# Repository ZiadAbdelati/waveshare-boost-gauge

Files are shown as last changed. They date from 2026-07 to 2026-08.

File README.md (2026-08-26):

# Boost Gauge

An open-source digital boost/vacuum gauge and dashboard for the **[Waveshare ESP32-S3-Touch-AMOLED-1.75](https://www.waveshare.com/esp32-s3-touch-amoled-1.75.htm)** (466x466 CO5300 AMOLED).

It runs an ESP-IDF + LVGL firmware that samples a GM 3-bar MAP sensor through an ADS1115 (with an optional BMP280 for ambient reference), renders a crisp 60 Hz analog-style gauge, and serves a companion web dashboard for telemetry, theming, TPMS, and Wi-Fi/OTA setup.

It swaps straight onto the Waveshare board, replacing the stock factory launcher.

## Screenshots

| Boost / vacuum | Overboost | Neon theme |
|---|---|---|
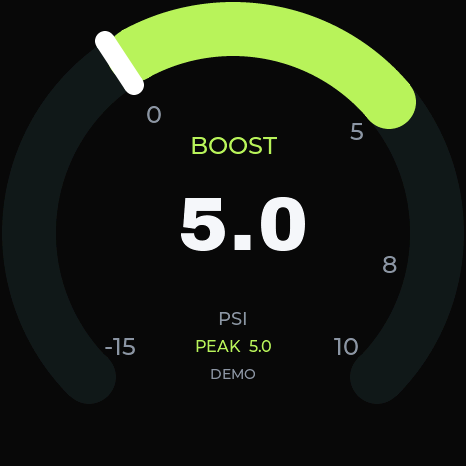
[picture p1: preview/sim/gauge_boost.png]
Boost gauge
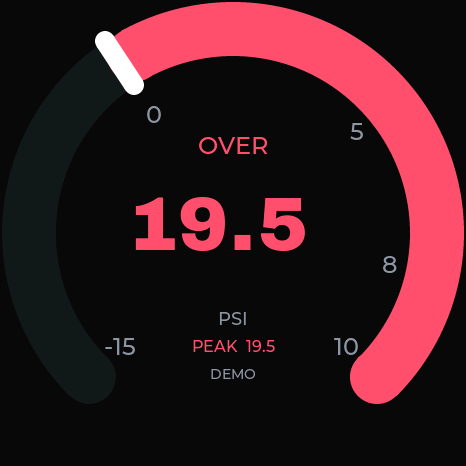
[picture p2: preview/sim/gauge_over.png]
Overboost
|  |  | `tools/sim` generates more |

More rendered previews live in [`preview/sim/`](preview/sim/).

## Features

- **Live gauge at 60 Hz** - a single filled arc that changes climate at zero: teal vacuum, lime boost, red overboost, with a big signed PSI readout and peak hold.
- **Five full gauge faces** (themes), each a distinct layout, not just a palette swap: Dyno Cell, Vault-Tec, Night City, Big Digit, and Neon.
- **Neon variants** - three layouts, four color presets, and SF Alien or Doto readout fonts.
- **Touch gestures** - tap to reset peak, swipe up/down to change themes, swipe left/right for TPMS, hold to dim, and two-finger hold for the AP QR code.
- **Web dashboard** - live cockpit, sparkline, settings, Wi-Fi setup, theme editor, and OTA updates over HTTP/WebSocket.
- **OBD-II / BLE TPMS** - Mazda MX-5 ND tire pressure plus generic mode-01 PIDs and battery voltage through a BLE ELM327 adapter.
- **Battery-backed clock** via a DS3231 RTC, DST-aware timezones, and dim-schedule control.
- **GIF playback** from the raw `media` partition.

## Hardware

- Waveshare ESP32-S3-Touch-AMOLED-1.75
- GM 12223861 (3-bar MAP) sensor through an ADS1115 on the sensor I2C bus
- Optional BMP280 ambient-pressure sensor
- Optional DS3231 RTC
- Optional BLE OBD-II/ELM327 adapter

## Quick start

The prebuilt image needs no ESP-IDF toolchain:

```bash
git clone https://github.com/ZiadAbdelati/waveshare-boost-gauge.git
cd waveshare-boost-gauge/release
python -m pip install esptool

# Linux / macOS
./flash.sh /dev/ttyACM0

# Windows PowerShell (replace COM5 with your port)
python -m esptool --chip esp32s3 -p COM5 -b 460800 `
  --before default_reset --after hard_reset write_flash `
  --flash_mode dio --flash_size 16MB --flash_freq 80m `
  0x0 boost_gauge_merged.bin
```

Newest prebuilt firmware (currently **v0.8.1**, ESP-IDF 5.5.1) is in [`release/`](release/) and on the [releases page](https://github.com/ZiadAbdelati/waveshare-boost-gauge/releases/latest). See [`release/README.md`](release/README.md) for details.

### Connect

- With saved Wi-Fi: use the address printed to serial as `BOOST_WEB_IP=`.
- Without saved Wi-Fi: join **`BoostGauge-XXXX`** / `boost1234`, then open `http://192.168.4.1/`.

## Build from source

Requires ESP-IDF **v5.5.1** with the `esp32s3` target.

```bash
git clone https://github.com/ZiadAbdelati/waveshare-boost-gauge.git
cd waveshare-boost-gauge
idf.py set-target esp32s3
idf.py build
idf.py -p /dev/ttyACM0 flash monitor
```

First build fetches the Waveshare BSP and LVGL from the ESP-IDF component registry. For a stubborn flash, hold **BOOT**, tap **RESET**, start flashing, then release **BOOT** when upload begins.

## Themes

Swipe vertically or use Settings:

```text
Dyno Cell -> Vault-Tec -> Night City -> Big Digit -> Neon -> Dyno Cell ...
```

Zone colors, arc range, zero angle, and theme-specific settings such as Neon layout, preset, and font persist in NVS.

## Project layout

```text
main/       ESP-IDF firmware
web/        dashboard sources embedded into firmware
tools/      asset, mock, benchmark, and cadence utilities
sim/        host LVGL simulator
release/    prebuilt firmware
docs/       technical documentation and measurements
preview/    simulator reference renders
```

## Documentation

- [Architecture](docs/architecture.md)
- [Display & cadence](docs/display-and-cadence.md)
- [Network & telemetry](docs/network-and-telemetry.md)
- [GIF playback](docs/gif-playback.md)
- [TPMS & OBD](docs/tpms-obd.md)
- [Sensors & calibration](docs/sensors-and-calibration.md)
- [GUI guide](docs/gui-guide.md)
- [Themes](docs/themes.md)
- [Release notes](docs/release-notes.md)
- [Regression ledger](docs/regression-ledger.md)

## Restore factory launcher

Flash the factory image from the [Waveshare releases](https://github.com/waveshareteam/ESP32-S3-Touch-AMOLED-1.75/releases).

## BLE central test harness (Intel hackintosh)

`tools/ble_central_test` scans for the gauge (`B6A00000`) and connects; it absorbs the IntelBluetoothFirmware 5→1 state flap (releases the central, waits 3 s, recreates it, retries the scan once) and self-exits instead of hanging. If a connection still fails with `saw N reset(s)`, the Intel stack cannot sustain a GATT link: add `-btlfxbeta` to the boot-args and ensure BlueToolFixup/IntelBTPatcher are current, stop concurrent `itlwm` WiFi scans (`sudo wdutil scan` or assoc churn) during the test, and if it persists prefer a `THIRD_PARTY_DONGLE` USB Bluetooth adapter over the internal Intel radio.

## License

Third-party code and OFL fonts are attributed in their sources. Doto's license ships as [`web/OFL-Doto.txt`](web/OFL-Doto.txt).

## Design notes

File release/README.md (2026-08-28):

# Prebuilt firmware v0.9.2 — companion BLE hardening

Firmware **`v0.9.2`**, built with **ESP-IDF 5.5.1** for **ESP32-S3**, 16 MB
flash. Headlines: the **BLE Control surface is now a real HTTP mirror** —
`/logs` returns a bounded compact window (128 points, decimated evenly across
the requested window so the 9.789 psi/s demo sweep draws triangles, not
staircases), and `/network` GET/PUT/DELETE + `/network/scan` +
`/network/reconnect` are served over Bluetooth, so the companion apps' Settings
and Wi-Fi pages work without joining the gauge's Wi-Fi. Blocking routes (logs
build, Wi-Fi scan, calibration) run on the driver task with heap buffers — the
NimBLE host loop is never stalled. The **OBD2 central defers its scan bursts
while a phone holds the companion link**, so enabling TPMS/OBD2 no longer
starves Logs. Companion apps gained **link self-healing** (iOS re-subscribes
notifications after a board reboot; Android detects and re-bonds a stale bond
left by reflashes), **instant log-window switching** (stale-while-revalidate),
and a **theme preview that actually updates** on selection. Carries v0.9.1's
Display/Demo reorg and v0.9.0's DMA-safe AMOLED path, DS3231/DST clock, and
calibrated GM 12223861 MAP path. The same files are published on the
[latest GitHub release](https://github.com/ZiadAbdelati/waveshare-boost-gauge/releases/latest).

The image reports its own version on `/api/v1/state` (`firmwareVersion`), taken
from `git describe` at build time. This release was tagged first, then
reconfigured/built/flash-verified from the tagged tree, so the board reports a
clean `v0.9.2` (serial-verified: UI ready, brightness, HTTP API ready, BLE
advertising, zero panics).

## Files

| File | Purpose |
|---|---|
| `bootloader.bin` @ `0x0` | 2nd-stage bootloader |
| `partition-table.bin` @ `0x11000` | Partition table |
| `ota_data_initial.bin` @ `0x12000` | OTA data (boots ota_0) |
| `boost_gauge.bin` @ `0x20000` | App image — use for **web OTA** |
| `boost_gauge_merged.bin` @ `0x0` | Full-flash image for a complete reset |
| `flash.sh` + `flash_args` | Helper to flash the merged image |
| `BoostGauge-android-debug.apk` | Android companion (debug-signed, versionCode 3) |
| `BoostGauge-ios-app.zip` | iOS companion `.app` bundle (install via Xcode/devicectl) |
| `SHA256SUMS` | Checksums for everything above |

## What changed since v0.9.1

### Firmware
- **BLE `/logs` route is real.** Compact `{"tMs","psi"}` samples, ~22 B each,
  128 points (cap/32) decimated evenly across the requested `?limit=` — the
  verbose 42-point window aliased the demo sweep into staircase pulses.
- **BLE `/network*` routes.** Settings/Wi-Fi pages in the apps now reflect the
  real STA state (SSID, IP, RSSI, saved networks) and can join/remove networks
  over Bluetooth. Wi-Fi scan runs on the driver task (`APP_EV_SCAN`), never on
  the NimBLE host task.
- **Blocking routes are async.** `/logs` (`APP_EV_LOGS`), `/network/scan`
  (`APP_EV_SCAN`), and `/sensors/calibration` all run on the driver task with
  heap response buffers; the host event loop never blocks.
- **OBD scan coexistence.** The OBD central's retry loop defers new 3 s scan
  bursts while a companion client is connected (they starved the peripheral's
  notification path mid-fragment). Stored-peer connects and real scan hits are
  not gated, so the in-car adapter link is unaffected.
- `APP_BLE_CTRL_RESP_MAX` stays **4096** — an 8 KB bump panicked twice under
  Wi-Fi + LVGL DMA pressure and is not measured-safe.

### iOS companion
- **CCCD self-healing:** Control notifications are re-subscribed on every
  write/timeout failure. A board reboot resets the gauge's subscription state;
  CoreBluetooth never re-issues `setNotifyValue` on auto-reconnect, so
  responses silently vanished — the first request after a gauge reboot now
  heals it (one timeout, then clean).
- **Per-call timeouts:** `/logs` uses a single 20 s attempt + one retry instead
  of the 10 s × 4-retry cascade that re-sent requests whose late responses fed
  a dead pending.
- **Instant window switching:** the Logs view publishes the cached 1m/5m/15m
  window before fetching (stale-while-revalidate).
- **Theme preview updates on selection** (reveal-gate race fixed: explicit
  theme-ID change signal + rescue re-renders re-armed per switch).
- Toasts: one reusable window, bottom capsule, no resurfacing on tab switches;
  timezone selection is local-only until you tap "Sync timezone to gauge"
  (single toast).

### Android companion
- **Stale-bond recovery:** verifies the encrypted link before writing the CCCD;
  on failure removes the stale bond, re-bonds fresh, and retries once. Fixes
  the endless `encryption changed status 13` reconnect loop after reflashing
  the gauge.
- Timezone: selection is local-only; sync sends the selected zone (not a
  phone-derived string) and shows one toast.

## Hardware verification (this release)

- iOS (physical iPhone, pure BLE): Logs window cycle 5m → 1m → 15m → 5m, three
  consecutive passes — `Last X · 128 samples` each, link connected throughout;
  repeated with the OBD2 BLE link enabled after the coexistence fix. Firmware
  serial: every `/logs` built in 3.5–5 ms.
- All five themes cycled over BLE from the app: preview updated each time, no
  reboot, no disconnect.
- Wi-Fi scan over BLE returned live AP rows; Settings shows real STA state.
- Android (physical Pixel): stale-bond recovery verified — `removeBond` →
  fresh pairing → `encryption changed status 0` + continuous 1 Hz state writes
  ≥60 s; 92/92 unit tests.
- Host test suite 11/11.

## Install

- **Full flash (fresh board / reset):** `./flash.sh /dev/cu.usbmodem*`
  (writes the merged image at `0x0`).
- **OTA (web UI → Settings):** upload `boost_gauge.bin`.
- **Android:** install the APK (allows "unknown developer" — it's the debug key).
- **iOS:** unzip and install the `.app` via Xcode's Devices window or
  `xcrun devicectl device install app`.

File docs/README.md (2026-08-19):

# Documentation

Detailed development notes, architecture, and measurements for the Boost Gauge project. The top-level `README.md` is the user-facing quick start; everything substantive lives here.

## Getting started

- [Architecture](architecture.md) — scene system, cached faces, drawing/invalidation rules, cost model
- [Display & cadence](display-and-cadence.md) — AMOLED bring-up, internal-DMA buffers, the 60 Hz render contract
- [Network & telemetry](network-and-telemetry.md) — WebSocket/HTTP control plane, clock/RTC persistence, GIF upload
- [GIF playback](gif-playback.md) — pipeline and animation performance contract
- [TPMS & OBD](tpms-obd.md) — BLE adapter support, Mazda MX-5 ND DID set, simulator
- [Sensors & calibration](sensors-and-calibration.md) — MAP sensor bus, GM conversion, atmosphere calibration
- [GUI guide](gui-guide.md) — gestures, two-page layout, dashboard notes
- [Themes](themes.md) — theme system, Neon internals, UI design tokens
- [Release notes](release-notes.md) — per-version highlights

## Engineering history

- [Regression ledger](regression-ledger.md) — the full measurement history behind every guard rail

Also see the top-level `AGENTS.md`, which carries the currently-actionable invariants (guard rails) repo-wide.

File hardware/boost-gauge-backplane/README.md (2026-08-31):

# Boost Gauge Backplane (tscircuit)

A Ø46 mm rear daughterboard for the Waveshare ESP32-S3-Touch-AMOLED-1.75 that
powers and reads the car's analog boost sensors, adds a BMP280 + DS3231, and
mates face-to-face to the Waveshare's 8-pin H2 expansion header.

## Status

**Source repair and automated PCB checks complete; physical pre-order gates
remain** (see `DESIGN_REVIEW.md` §7). The tracked release files are release
candidates, not fabrication approval, until those checks are recorded.

| Gate | Result |
|---|---|
| `tsci check netlist` | 0 errors / 0 warnings |
| `tsci check placement` | 0 errors; 3 JST access-direction advisories |
| final circuit JSON | 0 error records, 0 long-trace warnings, 0 unrouted records |
| `tsci check shorts --mode pcb` | toolchain-blocked: `layerCanvas.getContext is not a function` twice |
| `tsci build` | autorouted 128 connections / 142 PCB traces / 106 vias, 0 router errors |

## What it does

- **Power**: car 12 V (J1) → F1 fuse → bidirectional SMBJ16CA TVS → 40 V
  DMP4065S reverse-protection P-FET → LMR36520 synchronous buck → 5.016 V →
  VBUS ORing (SS54) → 500 mA-hold F2 PTC →
  SENSOR_5V rail for the sensors. USB VBUS from the Waveshare board ORs onto
  the same rail so the board is bench-configurable without car power.
- **Analog front end**: 4× JST-PH sensor inputs (J2–J5), each with 1 kΩ series
  + 100 nF filter (fc ≈ 1.6 kHz) + BAT54S rail clamps, into an ADS1115 4-ch
  16-bit ADC on the 5 V side of a TCA9406 I2C level translator.
- **Environment**: BMP280 (baro) and DS3231MZ RTC (CR1220 backup) on the 3.3 V
  side, sharing the Waveshare's GPIO17/18 I2C bus through H2.
- **Mechanical**: Ø46.00 mm circle, 3× Ø2.2 NPTH mounts at the Waveshare's
  brass standoffs, H2 1×8 2.54 mm header at y=−18.68 (pin 1 = VBUS).

## Files

- `index.circuit.tsx` — the whole design (schematic + placement + form factor)
- `imports/` — LCSC-verified component models (`tsci import` outputs)
- `reference/` — mechanical mating spec (authoritative) + Waveshare PDFs
- `PLAN.md` — design history, decisions, session log
- `DESIGN_REVIEW.md` — bug audit with evidence, power-path math, gate status
- `dist/` — gitignored build output (regenerate with the commands below)
- `release/` — **tracked** release-candidate outputs of the verified build: Gerbers,
  drills, raw + JLC-filtered BOM/CPL, SVG renders, STEP, SHA256SUMS

## Regenerate outputs

```sh
npm run typecheck
tsci build index.circuit.tsx

# Export the verified route, not a second independent source reroute.
tsci export dist/index/circuit.json -f gerbers -o dist/gerbers
tsci export dist/index/circuit.json -f pcb-svg -o dist/pcb.svg
tsci export dist/index/circuit.json -f schematic-svg -o dist/schematic.svg
tsci export dist/index/circuit.json -f assembly-svg -o dist/assembly.svg
tsci export dist/index/circuit.json -f step -o dist/board.step
```

The Gerber export is a ZIP. Unpack it into `dist/gerbers_dir`, then generate
`bom_jlc.csv` and `cpl_jlc.csv` by excluding `BT1,H2,J1,J2,J3,J4,J5` and every
`TP_*` designator. Validate the archive, exact excluded set, supplier IDs, and
matching filtered BOM/CPL designator sets before explicitly promoting the 19
release files and regenerating `release/SHA256SUMS`. Verify checksums from this
directory with `shasum -a 256 -c release/SHA256SUMS`.

## Ordering (JLCPCB)

- PCB: upload `release/*.gbr` + drill files (2 layer).
- Assembly: upload `release/bom_jlc.csv` and `release/cpl_jlc.csv`
  — these **exclude** the 7 hand-solder parts (J1, J2–J5, BT1, H2) and 17
  PCB-only `TP_*` pads which the raw exports still include.
- Hand-solder at assembly: the bottom/outward JST-PH connectors, the H2 mating
  header, and—only after stack-clearance validation—the top/mating-face
  BS-12-B2AA002 horizontal SMT CR1220 holder. Install the cell after soldering.
- Checksums: `release/SHA256SUMS` covers every tracked artifact; verify after
  download from JLC.

## Before ordering — mandatory

See `DESIGN_REVIEW.md` §7. Required checks include a 1:1 overlay and H2 pinout,
gender, stack-height, and continuity confirmation; measured inter-board
separation and loaded BT1 clearance; bottom connector and cable access against
the flush mount; USB-C plug clearance; BMP280 vent clearance; manual U1 land
pattern comparison; an independent PCB-short DRC; and electrical/thermal bench
validation before installation in a vehicle.

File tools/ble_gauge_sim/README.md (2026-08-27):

# ble_gauge_sim

macOS **CoreBluetooth peripheral simulator** for the ESP32-S3 boost gauge.
It advertises as `BoostGauge` so the iOS and Android companion apps (built in
parallel) can be tested end-to-end over real BLE without the Waveshare board.

Dependency policy: **CoreBluetooth + Foundation only**. No other frameworks,
no third-party packages. Requires macOS 13+.

## Build

```bash
cd tools/ble_gauge_sim
swift build -c release
```

The executable lands at `tools/ble_gauge_sim/.build/release/ble_gauge_sim`.
Xcode/Command-Line Tools with the macOS 13+ SDK is required (@platforms
`.macOS(.v13)`).

## Run

```bash
tools/ble_gauge_sim/.build/release/ble_gauge_sim --verbose
```

Or without the per-request chatter:

```bash
tools/ble_gauge_sim/.build/release/ble_gauge_sim
```

CLI:

| Flag | Meaning |
|---|---|
| `--help` | Usage, GATT map, caveat. |
| `--verbose` | Log every control request/response (default logs connect/disconnect/state/restart events only). |
| `--firmware <string>` | Firmware string in DeviceInfo and Status (default `0.9.0-sim`, e.g. `--firmware v0.9.0-sim`). |

The process runs until interrupted (Ctrl-C). One clean line per event is
printed to stdout: CoreBluetooth state transitions, connect/subscribe,
disconnect/unsubscribe, and (with `--verbose`) each control
request/response.

## What it advertises

- Local name: **BoostGauge**
- Primary service: `b6a00000-0000-4000-8000-00000000b6a0` (in the adv payload)
- Connectable, startAdvertising on launch once CoreBluetooth is powered on.

## GATT map

| Characteristic | UUID suffix | Properties | Payload |
|---|---|---|---|
| Control | `b6a00001-...-b6a0` | write + notify | JSON RPC, requests ≤ 480 B |
| Status | `b6a00002-...-b6a0` | read + notify | `/state`-shaped JSON, notify ~1 Hz while subscribed |
| Log | `b6a00003-...-b6a0` | read | `BGL1\n` + 600 samples (2 min @ 5 Hz); offset reads return the suffix |
| DeviceInfo | `b6a00004-...-b6a0` | read | `{"name":"BoostGauge","fw":"0.9.0-sim","api":1}` |

Status payload (compact `/state`-shaped snapshot, waveform: sine 0-15 psi,
period ~8 s, monotonic `uptimeMs`; `zone` uses the firmware/`docs/bluetooth-gatt.md`
tokens VAC / ATMO / BOOST / OVER):

```json
{
  "psi": 7.32, "peak": 12.4, "zone": "BOOST", "demo": true,
  "uptimeMs": 123456, "brightness": 80, "theme": "dyno-cell",
  "tpms": {"status": "normal", "kpa": [224.3, 225.1, 223.8, 226.0], "valid": [true, true, true, true]},
  "obd": {"state": "ready", "rpm": 850.0},
  "fw": "0.9.0-sim", "transport": "ble"
}
```

## Control protocol

Requests are written to Control as JSON (≤ 480 B):

```json
{"id": 1, "path": "/config", "method": "PUT", "body": {"brightness": 60}}
```

Responses are notified back on Control:

```json
{"id": 1, "status": 200, "body": {"appBle": true, "brightness": 60, "theme": "dyno-cell"}}
```

`status` is an HTTP-style code (200 / 400 / 404 / 405 / 413). Errors use
`{"error": "..."}`. Both `/state` and `/api/v1/state` spellings are accepted
(the firmware HTTP roots). If a request has no parseable `id` the write is
still ACKed at the ATT layer but no JSON response is emitted. A request larger
than 480 bytes is answered `413 {"error": "too_large"}` when its `id` can be
scanned from the payload.

Routes:

| Path | Method | Behavior |
|---|---|---|
| `/state` | GET | Status snapshot (same object as Status characteristic). |
| `/config` | GET/PUT | In-memory config `{"appBle":bool,"brightness":int,"theme":str}`; PUT returns the updated object. |
| `/themes` | GET | `[{"id":"dyno-cell","name":"Dyno Cell"},{"id":"vault-tec","name":"Vault-Tec"},{"id":"night-city","name":"Night City"},{"id":"big-digit","name":"Big Digit"},{"id":"neon","name":"Neon"}]` |
| `/themes/active` | PUT | `{"id":"<theme>"}` → validates, activates, echoes `{"id":..,"activeThemeId":..}`; unknown id → 404. |
| `/tpms/config` | GET/PUT | Firmware-shaped `{"lowKpa":..,"lowPsi":..,"staleAfterMs":..}` (defaults 220 kPa / 15 000 ms, range-checked like firmware). |
| `/time` | POST | Accepts `epochMs`/`timezoneOffsetMinutes`/`timezoneTz` if present → 200 `{"ok":true}`. |
| `/restart` | POST | 200 `{"ok":true,"restartingInMs":400}` and prints the restart event (sim does not reboot). |
| `/logs` | GET | Body `{"count":600}` (default 600, capped at 600) → firmware-shaped `{"samples":[{"tMs":..,"psi":..,"peakPsi":..,"zone":..,"demo":..}]}`. |
| `/page` | PUT | `{"page":0|1}` (or `activePage`) → 200 `{"ok":true,"activePage":..}`. |
| anything else | any | 404 `{"error":"not_found"}`. |

## Log characteristic

Body:

```text
BGL1
t_ms,psi,peak_psi,zone,demo
0,7.50,7.50,BOOST,1
200,7.49,7.50,BOOST,1
...
```

Exactly 600 newline-terminated data lines at 200 ms spacing ending at the
current `uptimeMs`, synthesized from the same sine waveform (running peak
included). Reads honor `CBATTRequest.offset`: `offset > 0` returns the suffix
bytes from that offset; an offset at-or-beyond the end returns a zero-byte
short read (which ends the transfer, per `docs/bluetooth-gatt.md`).

## Caveats

- **Pairing/encryption is NOT simulated.** macOS `CBPeripheralManager` cannot
  require real LE Secure Connections bonding in a useful way for this tool.
  Companion apps must treat `encrypted` as advisory in sim mode (e.g. skip
  start-encryption expectations; no characteristics are protected).
- Config is **in-memory only** — restarting the simulator resets
  `appBle`/`brightness`/`theme` and TPMS thresholds.
- State is single-threaded on the main run loop (CoreBluetooth callbacks and
  the 1 Hz status timer); no locks, no background queues.
- Notifications are serialized per characteristic and fragmented into
  ≤180-byte packets (fits the iOS ATT MTU 185 → 182-byte payload). Clients
  must append packets in arrival order until the buffer parses as one complete
  JSON value (the behavior `docs/bluetooth-gatt.md` requires of apps).
- The Log characteristic carries a **600-sample (2-minute) snapshot** per this
  tool's brief; the firmware ring described in `docs/bluetooth-gatt.md` holds
  18,000 samples (1 hour). The sim deliberately serves the brief's 600-line
  snapshot.
- Advertising is not active until CoreBluetooth reports `state: poweredOn` and
  the service is published (`service added:` + `advertising:` lines).

## Host-side check

```bash
python3 tools/test_ble_sim.py
```

Validates the embedded route/theme table and `BGL1` log format from source
(no radio required).

## Troubleshooting

- **Newly built local binaries won't launch (hang at exec) on a Mac that is
  mid system/Xcode/simulator-runtime install:** the machine-wide code-sign
  validation path can stall for unsigned local binaries. Ad-hoc sign the
  binary and run again:

  ```bash
  codesign -s - --force .build/release/ble_gauge_sim
  ```

  This was required on one development host during an Xcode first-run/simulator
  bootstrap; it is a host quirk, not part of the normal build.
- On the same class of wedged host, `swift build` can stall while SwiftPM
  launches its (unsigned) manifest executable even though `swiftc -typecheck`
  and a direct `xcrun --sdk macosx swiftc -O` compile work. That is an
  environment issue; the direct compile produces the same product.
- CoreBluetooth prints nothing until the daemon delivers a state callback; if
  the whole host's CoreBluetooth is stalled (neither central nor peripheral
  callbacks arrive), wait for the host install to finish before judging the
  simulator.

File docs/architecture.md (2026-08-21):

# Firmware architecture

`main/boost_gauge.c` is a **scene dispatcher**, not a single face.

## Scene model

- `build_scene(style)` / `destroy_scene()` construct and tear down a per-style LVGL object tree. `boost_gauge_update()` dispatches to the matching `update_*()`. `s_built_style` records what is currently on screen.
- **Changing theme rebuilds the scene** rather than recolouring, because each style is a different object tree. `PUT /themes/active` therefore calls `boost_gauge_apply_theme()` under the display lock — without it the picker only took effect after a reboot.
- The `arc` face keeps its original geometry and wedge-invalidation logic verbatim; it is the path the 60 FPS cadence guard was established against.

`app_main()` synchronously builds the persisted scene before it returns. The main task stack is therefore 8,192 bytes; ESP-IDF's 3,584-byte default overflowed while baking a persisted Neon scene before brightness or networking could start. A Neon cold boot must reach brightness and `HTTP API ready`, not merely `display ready`.

## Zero reference

`psi_to_angle()` maps the arc face. `psi_to_sweep(psi, a0, a1)` projects the same zero-referenced scaling into any other sweep, so Vault-Tec and Night City honour the configured `zeroAngle` and scale vacuum/boost independently, exactly like the arc.

## Draw/invalidate must agree

Every moving element draws from a *committed* value that is only advanced when the element is invalidated (`s_vault_needle_deg` / `s_vault_needle_over`, `s_hud_fill_deg` / `s_hud_fill_psi`). Drawing from the live sample while invalidating on a threshold leaves stale pixels — that was the source of the smearing artifacts. The needle also repaints on an overboost **colour** flip, not only on angle change.

## Clip guard

`clip_reaches_radius(layer, r)` reads `layer->_clip_area` (its documented use during draw-task creation) and lets a face skip its outer ring art when only the centre is dirty — the common per-frame case, since digit updates cannot touch a tick ring at r ≥ 194. The Vault needle is deliberately shorter than the tick ring so its dirty rect stays inside the guard.

## Cost model (measured on hardware)

Repainting the full 466×466 face is ~217k pixels; sustained throughput is ~0.9 Mpx/s, so a full-face repaint costs roughly a quarter second. Anything that recolours the whole panel (the `bigdigit` ground) is therefore inherently a hitch and must be quantized. This is also why translucent full-circle overlays were removed: five vignette rings re-blended ~107k px on every needle frame and dropped Vault from 60 to 37 FPS.

## Cached static faces

Vault-Tec, Night City, and Dyno Cell each paint their entire static face **once** into a 434 KB PSRAM `lv_canvas` at scene build (`paint_vault_background`, `paint_hud_face(..., cached=true)`, `paint_arc_background`); every later redraw is a blit rather than re-rasterising vectors. This is the single biggest lever available, because the bottleneck is CPU rasterisation, not the panel link. Measured: Vault median 37 → 61 FPS, min 4 → 54, while *adding* the vignette and scanlines; Night City 32 → 37. Elements that move (needle, fill arc, peak tell-tale, digits) stay as separate objects on top; only genuinely static art belongs in the cache. Vault's completed canvas remains allocated across theme switches because its serial per-pixel error-diffusion vignette is expensive to recreate; range, zero angle, palette, face, and vignette values form its cache key, so a setting change still repaints it once. Other faces free their cache in `destroy_scene()`.

Dyno Cell's cache covers the unfilled track ring, the zero notch, the five scale numerals, and the static "PSI" mark — the value wedge (`s_arc_value_canvas` / `draw_value_arc`), the readout digits, peak, and zone label stay live above it. The value wedge invalidates from its committed smoothed geometry while raw pressure still controls the numeric/color state. Because range and zero-angle move the numerals and notch, `boost_gauge_apply_config()` no longer special-cases arc with incremental patches; it takes the same `destroy_scene()` / `build_scene()` rebuild path as vault/hud/bigdigit on a config change, so the cache repaints rather than keeping stale numerals. Measured hardware, demo mode, 3 fresh boots each, 30 s polling windows of `/api/v1/state`: `worstRenderUs` max 58.4–63.7k µs / mean ~24–25k µs before, 43.8–51.3k µs / ~22.7–23.1k µs after; cadence guard min 56–57 → 58–59, median 60 both. Host audit (`--theme dyno-cell --seconds 25`) is unchanged before/after.

Corollary: effects that would be prohibitive per-frame (vignettes, texture) are essentially free once baked. Prefer baking over per-frame drawing.

**Caching does not help a flat fill.** Big Digit's ground is a solid colour, so there is no vector art to pre-compute — a fill is already the cheapest primitive LVGL has, and 24 cached full-screen grounds would want 10 MB besides. Its cost is the unavoidable 217k-pixel repaint when the colour steps. The fix is to *spread* that repaint, not to precompute it: `BIG_BANDS` full-width bands take the new colour on successive ticks, so one long stall becomes several short ones. This is a direct trade — the shorter the stall, the more the transition reads as a visible wipe:

| `BIG_BANDS` | Worst cycle @40 MHz | Transition |
|---:|---:|---|
| **1** | 45.1 ms (**39 ms** at the current 80 MHz) | **selected** — one clean jump, no wipe |
| 2 | 33.3 ms | a single horizontal split |
| 4 | 25.8 ms | a clearly visible top-to-bottom sweep |

Banding and the clock attack the same stall independently, so `BIG_BANDS = 1` at 80 MHz lands near what 2 bands bought at 40, with no visible transition at all. Total work is conserved, so `renderFps` barely moves between these. A/B any change on `worstRenderUs`.

## RGB565 gradient limits

**RGB565 has too few levels for a gradient over a dark colour.** Vault's face is `#02100a`, whose green sits at **level 4 of 63** in RGB565, so a mathematically exact vignette still resolves to four flat rings on the panel. The web mirror looks smooth only because canvas is 8-bit. The fix is a serpentine Floyd–Steinberg-style **error-diffusion** pass in `paint_vault_background`, with two error rows carrying RGB565 quantisation error into neighbouring pixels. The pattern is baked into the cache so it never shimmers. Any future smooth ramp over a near-black colour needs the same treatment; check the source channel's 565 level before assuming a banding report means the gradient maths is wrong.

## Match the web mirror's method

Vault's CRT treatment is a direct port of `drawVaultGauge`: the vignette is a smooth radial ramp from r=120 to r=233 reaching 60% black, and the scanlines are 1 px rows every 4th line at 16% black, both chord-clipped to the face. The vignette is applied as a **per-pixel pass** over the canvas buffer after the vector art. The scanlines are **not** baked; they are drawn last (`draw_vault_crt`, the topmost child) so they cross the needle and digits as on the web. Their phase comes from absolute screen y, which stops neighbouring dirty regions from disagreeing and producing tearing (an earlier per-region version showed). Cost of the on-top pass: ~1 FPS.

## Invalidate what changed, not the widget

Night City's ghost pass repainted a fixed 310×100 box on every value change; bounding it to the slots that actually changed (usually the tenths alone) took the style from 37 to 42 FPS median and 22 to 31 min. `HUD_GLITCH_DX` is shared between draw and invalidation so the dirty box can never be narrower than the pixels the ghosts touch.

Night City's gradient fill has a measurable but secondary cadence cost. The fill is one quantized solid colour, and each colour-step crossing invalidates and recolours the complete zero-to-value arc. The retained mapping uses one fixed vacuum sentinel plus **24 buckets devoted exclusively to positive pressure**: bucket 1 starts immediately above zero and bucket 24 lands exactly at configured max; firmware, Big Digit, and the web mirror share the same ceiling-based mapping. Reproduce a gradient comparison with `tools/bench_hud_gradient.py`; judge an optimization on render time, pacing, and pixels/s rather than FPS alone.

The ghost's two semi-transparent 96 px label passes were the largest discrete raster cost, so they now pre-blend their colours against the known static face and draw opaque, preserving offsets, glyphs, and dirty regions while avoiding two destination read/blend passes. This intentionally approximates the original alpha composition where the two shifted copies overlap; it is not framebuffer-identical.

The readout cache is one scene-owned, immutable PSRAM block of **34,786 B** containing only digits 0–9, decimal, and minus, reused by the primary readout and ghost pass; surrounding HUD labels keep their source fonts. Draw callbacks publish stable descriptors only; the block is never mutated or republished. Lifecycle is draw-unit safe: drain with `lv_draw_wait_for_finish()` before scene teardown or cache release, and keep the cache alive until all draw units finish. Allocation failure retains the source-font fallback. `BOOST_HUD_READOUT_CACHE=0` provides a compile-time source-font A/B/fallback guard.

Vault-Tec deliberately keeps the same consolidation pattern in a bounded **146×34** six-slot readout object together with `VAULT_NEEDLE_SEGS=3` and the hardware-proven two-triangle needle raster. Two invalidation segments clean up host antialiasing seams but enlarge the dirty regions and worsened the matched hardware tail, so the kept production choice is the bounded consolidated readout plus **three** invalidation segments. Future Vault changes must rerun both the RGB565 stale-pixel audit and interleaved hardware cadence measurements.

The retained Vault renderer removes the **26 px counterweight tail** behind the pivot by default. A persisted `vaultNeedleTail` option in the Vault theme editor and `/themes/config` API restores it when desired. The wedge tip length, 15 px hub, two-triangle raster, three invalidation segments, AA padding, CRT overlay, and 146×34 readout remain unchanged. Draw and both invalidation paths resolve the same runtime tail length; applying the setting rebuilds the scene so old foreground pixels cannot remain. The browser mirror follows the same geometry.

## Geometry animation

Both physical arcs animate geometry through one shared latest-target linear interpolator. Each new sample remains the exact target immediately; the visible endpoint retargets from its currently displayed position over a fixed 40 ms animation, cannot overshoot, and snaps on initialization, scene rebuild, non-finite input, or a gap over one second. There is no adaptive EMA, alpha cap, or small-change suppression. Only geometry is animated: raw pressure still drives numeric readouts, peak/model/API state, and immediate colour/threshold transitions. Draw and invalidation use the same committed visual state.

Two web-mirror fixes closed remaining parity bugs: Night City's chromatic split had become visually negligible at **0.4 alpha / 3 px**; it now uses **0.7 / 6 px**. The Big Digit renderer ignored `bigDigitStaticBg`, `staticColor`, `colorText`, and `textColor`; it now consumes all four settings.

Night City's colour menu also offers a persisted **True black background** checkbox: it replaces the default `#080A08` face with `#000000`, turning unused AMOLED pixels fully off; the cached physical face, screen background, chromatic ghost pre-blend, and browser mirror all consume the same setting. Its gauge track and live fill are **15 px** thick (up from 10 px), with the wider physical invalidation bounds kept in lockstep. The ring is pushed outward from radius 206 to 225; its unchanged 16 px ticks move from radii 198–214 to 217–233 so their outer ends meet the panel edge.

Night City's first sample is the exception to endpoint-only invalidation: after a scene switch it invalidates the complete zero-to-current span, otherwise a rebuild rendered before the first vacuum sample left the fill empty. The host audit deliberately switches into Night City from an already-negative reading to preserve this case. On hardware, the first Vault build took 1077 ms, while three cached returns took 64–101 ms; the Dyno Cell cadence guard after a 3 s settle passed at min 58 / median 61 FPS over 104 samples.

Vault-Tec also seeds its newly-built needle from the last committed pressure on a theme-switch rebuild. Previously the object started at zero for one frame and jumped on the next sample. The simulator audit switches into Vault-Tec at +8.0 PSI before the next gauge update and requires that update to move the needle by 0.000 degrees.

## Reading the metrics

**`render_fps` is not a smoothness metric.** It counts `LV_EVENT_RENDER_READY`, i.e. render cycles actually performed; LVGL only renders when something is invalidated. A face whose content changes less often legitimately reports a lower number while using *less* throughput. Compare `pixelsPerSecond` before concluding a face is too slow. For the organic demo, compare `renderFps` with `gaugeDemandPerSecond`: only a shortfall in a demanded window is a cadence defect. The constant-slew capacity gate remains a direct median `renderFps >= 60` check.

**`worstRenderUs` is the choppiness metric.** It is the longest single `LV_EVENT_RENDER_START` → `LV_EVENT_RENDER_READY` interval in the reporting window: the duration of a cycle, not the gap between cycles. Measuring the gap instead was the first cut of this metric and it was useless, because an idle screen produces long gaps and no stall at all.

## Where the pieces live

- **Web mirror:** `web/app.js` dispatches `drawGauge()` on `activeThemeStyle()` to the active renderer. `tools/mock_server.py` serves the five selectable themes (each with a `style` field). Regenerate embedded assets after any web edit. `setTheme()` drives only the gauge palette, so the dashboard chrome keeps one fixed identity.
- **Simulator:** `sim/` builds the same `boost_gauge.c` on the host and renders headless PNGs, including the generated fonts. SDL2 is optional (only `--window` needs it); `--theme <id>` selects the style, `--neon-layout tube|segments|marquee` and `--neon-preset 0..3` the neon face and colourway, and `--neon-spin` enables the marquee chase (with `--neon-chase DIR` writing a fixed-psi 90 ms/step chase sequence). Both flags exist because the sim does **not** inherit the device's persisted settings: it calls `boost_theme_init()` at startup, and without them it renders the defaults. This is the fastest verification loop; use it before burning a flash cycle.
- **Font:** `main/fonts/alvidafatface-regular.otf` is kept as OTF (CFF master, ~4× smaller, converts cleanly with `lv_font_conv`). The dashboard loads it as an inlined base64 `@font-face` (`"Alvida Fatface"`) prepended to `web/styles.css`.

## Fonts

`main/fonts/` holds generated LVGL fonts; sources live there, under `main/fonts/src/`, or in `web/` when the dashboard serves the same file. All are OFL so they can ship in the image (the web mirror's Bahnschrift/Consolas are Microsoft fonts and cannot be embedded):

| Font | Source | Use |
|---|---|---|
| `alvida_big` | Alvida Fatface | big-digit numeral |
| `font_mono_16/40` | IBM Plex Mono SemiBold | readouts, telemetry |
| `font_cond_14/18/22/32` | Saira Condensed SemiBold | labels |
| `font_cond_96` | IBM Plex Sans Condensed BoldItalic | Night City readout |
| `archivo_black_65` (65 px) | Archivo Black (Google Fonts) | Dyno Cell readout |
| `font_wide_22/32` | Saira SemiCondensed Bold | Big Digit labels |
| `neon_big` (118 px) | SF Alien Encounters Italic | neon readout, all three layouts |
| `doto_big` (126 px) | Doto ROND 100 / weight 700 | optional neon readout, all three layouts |
| `neon_label` (24 px) | SF Alien Encounters regular | neon zone word and `P S I` |

The neon readout is italic; the zone word and `P S I` are the **upright** face, so `main/fonts/` carries both `SFAlienEncounters-Italic.ttf` and `SFAlienEncounters.ttf`. The web mirror inlines both under one family name and selects between them purely by the presence of the `italic` keyword.

The neon fonts carry only the glyphs they use. SF Alien's minus is drawn from bar geometry; Doto's uses three period-sized dots. Their sizes are not free parameters — the readout cell pitch, sprite tile size, and invalidation bounds are derived from the generated `line_height` and widest glyph ink. Regenerate Doto with `python tools/generate_doto_font.py`; its SIL OFL 1.1 license is `web/OFL-Doto.txt`.

Regenerate with `lv_font_conv`, always passing `--lv-include lvgl.h` (the default `lvgl/lvgl.h` does not resolve against the managed component). Glyphs missing from a face can be merged from a second `--font`. Do not try to embed box-drawing/arrow codepoints through shell escapes — draw such marks as shapes instead; escaped UTF-8 has repeatedly been mangled a layer early.

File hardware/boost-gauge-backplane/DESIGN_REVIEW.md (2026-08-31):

# Boost Gauge Backplane — Design Review

Audit date: 2026-08-30. This review covers the tscircuit source, the uploaded
Waveshare mating specification, the final routed circuit JSON, and staged
manufacturing outputs. It does not replace physical fit or powered bench tests.

Face convention used throughout:

- **TOP** = Waveshare-facing, mating, inside face.
- **BOTTOM** = enclosure/mount-facing, outward, back face.

## 1. Mechanical authority and placement

`reference/WAVESHARE_1_75_MECHANICAL_MATING_SPEC.md` supersedes the original
PLAN geometry. The implemented board is a 72-segment Ø46.00 mm circle with
three Ø2.2 mm NPTH holes at `(0,+20.50)` and `(±13.75,-14.70)`. H2 is centered
at `(0,-18.68)`, with eight pins on 2.54 mm pitch. Under the face-to-face mirror,
backplane H2 pin 1/VBUS is at x = -8.89 mm. The USB-C access keepout is on the
backplane's left edge; there is no fabricated outline notch.

Electronics are on TOP where feasible. J1–J5 are the only BOTTOM components,
keeping the flush mount face free of electronics while leaving the cable
connectors outward. Their tscircuit orientation warnings are a horizontal-access
heuristic applied to vertical/top-entry JST-PH parts; real connector bodies and
cables still require a 1:1 mount check.

Explicit keepouts cover the USB-C envelope, all three mount holes, and the
BMP280 vent. The sensor also has a `DO NOT COVER / NO COAT` fabrication note.

## 2. BT1 identity and stack-height decision

BT1 is not a cable header. It is MYOUNG `BS-12-B2AA002` / LCSC `C964721`, a
horizontal SMT CR1220 holder. It is `doNotPlace`, on TOP at `(13.2,-0.5)`, and
must be hand-soldered without the cell installed.

The supplier-family drawing gives a 4.10 mm mechanical holder height. A
Panasonic CR1220 is at most 2.0 mm thick and normally nests in the holder. Use
these as unresolved bounds:

- **4.10 mm likely installed envelope** if the drawing's height includes the
  loaded/nesting envelope.
- **6.10 mm conservative additive bound** only until the supplier or a physical
  section confirms the loaded datum.

The mating specification intentionally leaves daughterboard separation
undefined. It must include the tallest Waveshare rear part, selected H2 stack,
screws/standoffs, solder protrusion, and daughterboard parts. BT1 may remain on
TOP only after that real assembled gap is measured. The generated STEP is not
evidence of fit: DNP bodies are not a complete assembly envelope and tscircuit's
STEP parser rejected several downloaded supplier models.

References: [LCSC holder page](https://www.lcsc.com/product-detail/Button-And-Strip-Battery-Connector_MYOUNG-BS-12-B2AA002_C964721.html),
[supplier-family drawing](https://atta.szlcsc.com/upload/public/pdf/source/20250915/C0E8C58C172AE3B5B92BC8CEB0A088C7.pdf),
[Panasonic CR1220 datasheet](https://energy.panasonic.com/dam/master/pdf/en/datasheet/lithium/CR1220_Datasheet_EN.pdf).

## 3. Electrical audit and repairs

### Vehicle input and buck

- Corrected the series path to `J1 → F1 → CAR_12V_RAW → Q1 →
  CAR_12V_PROTECTED`. D1 is connected from fused RAW to GND.
- D1 is now bidirectional `SMBJ16CA` (`C353385`), avoiding a unidirectional TVS
  forward crowbar during reverse battery. This remains a 12 V automotive design;
  it is not approved for continuous 24 V input.
- Q1 is now the 40 V `DMP4065S-7` (`C182476`) with drain on RAW, source on
  PROTECTED, a 100 kΩ gate pull-down, and a correctly polarized 10 V VGS zener.
- LMR36520 feedback is 100 kΩ / 24.9 kΩ for 5.016 V nominal. BOOT uses only a
  100 nF BOOT-to-SW capacitor; the converter is synchronous.
- L2 is the verified 10 µH `FXL0530-100-M` (`C177248`). Output capacitance is
  two 22 µF capacitors plus 100 nF. The switch node, input HF loop, output caps,
  feedback sense/ground, and exposed-pad grounding have explicit short routes.

These changes improve the paper design, but transient energy, TVS clamp voltage
at real current, MOSFET margin, output ripple, and thermals still require bench
measurement with automotive-source impedance. F1 is fault protection, not a
substitute for validating load-dump behavior.

### VBUS and sensor branch

- D2 (`SS54`) ORs buck output into `VBUS_SHARED` and blocks USB VBUS from
  feeding back into the unpowered buck.
- F2 is `nSMD050-24V` (`C70076`), 500 mA hold / 1 A trip, so the sensor branch
  has meaningful selectivity relative to the 2 A buck. A real harness-short test
  must confirm display behavior and trip/recovery time.

### ADC and I2C

- U2, U3, and U5 now use exact supplier copper land patterns. Their logical pin
  labels were checked against the device pin tables.
- ADS1115 has close 100 nF and 1 µF bypass paths. Each AIN channel is connector
  signal → 1 kΩ → filtered ADC node, with 100 nF to GND and a BAT54S rail clamp.
  The nominal RC corner is about 1.59 kHz.
- The TCA9406 uses 4.7 kΩ pull-ups on both domains and has local VCCA/VCCB
  bypassing. I2C nets carry an explicit 0.2 mm nominal width.
- BMP280 power and bus approaches were rerouted clear of the prior accidental
  contact; its local 100 nF bypass has a 3 mm maximum route.
- DS3231 VCC bypass was moved next to U5 and constrained to 3 mm. VBAT is direct
  to the non-rechargeable CR1220 holder; there is no charging path.

## 4. Supplier footprint review

Fresh exact-import copper for U2, U3, and U5 matches the local wrappers and their
old mismatch warnings are gone. U1 still produces one supplier-footprint IoU
warning (`0.7255`) even though its local copper matches a fresh exact import.
Do not suppress or reinterpret it: compare the exported U1 pads manually against
the TI package land pattern and JLC/EasyEDA part before fabrication.

## 5. Automated verification

The final source was built with tscircuit 0.0.2461 and TypeScript 5.9.3. The
authoritative routed snapshot is `dist/index/circuit.json`.

| Gate | Observed result |
|---|---|
| `npm run typecheck` | pass |
| `tsci check source` | 0 errors / 0 warnings |
| `tsci check netlist` | 0 errors / 0 warnings |
| `tsci check placement` | 0 errors; 3 JST access-direction advisories |
| routing-difficulty | pass; highest local estimate 12% |
| final autoroute | 128 routed connections; 0 jumpers; 0 router errors |
| final JSON | 142 PCB traces; 106 vias; 0 errors; 0 long traces; 0 unrouted |
| critical trace probes | U1 SW→C18 1.88 mm; U1 SW→L2 3.77 mm; U5 VCC→C16 2.08 mm; C7→C5 3.08 mm |
| supplier checker | U1 warning only, IoU 0.7255 |
| bitmap PCB shorts | **blocked by tscircuit CLI defect; failed identically twice** |
| repository host suite | 11/11 passed (loopback-enabled run) |
| repository live-device hardware suite | unavailable: configured board `192.168.50.102` timed out / host down |

`tsci check shorts --mode pcb dist/index/circuit.json` throws
`layerCanvas.getContext is not a function`, including a retry at reduced pixel
density. Therefore “no shorts” is not claimed from that raster checker. The
zero-error circuit JSON and completed router are positive evidence, but an
independent Gerber/PCB DRC remains mandatory.

Schematic autolayout is electrically clean but reports cosmetic overlaps and
long/awkward label routes. The exported schematic is an audit aid, not a
publication-quality service drawing.

The repository `tools/check_hardware_gates.py` suite targets a running firmware
device and is not a static PCB test. Its network-enabled retry could not reach
the configured board, so none of its live boot/display/BLE/media gates are
credited to this hardware revision.

## 6. Manufacturing-output audit

Manufacturing files were staged by exporting directly from the verified circuit
JSON, preventing a second independent autoroute. The Gerber ZIP passes `unzip
-t` and contains 13 raw entries: nine Gerbers, two drill files, raw BOM, and raw
pick-and-place.

Raw BOM/CPL contain 73 designators. The JLC files contain 48 placed components
and exclude exactly:

- hand-solder/DNP: `BT1,H2,J1,J2,J3,J4,J5`;
- PCB-only pads: all 17 `TP_*` designators.

Every filtered BOM row has a supplier ID, and filtered BOM/CPL designator sets
are identical. The fresh exporter produces 19 promoted artifacts plus
`SHA256SUMS`; the historical `F_Fab.gbr` is not regenerated and must not be
carried forward from an older release.

## 7. Pre-order and bring-up gates

The board is a release candidate, not fabrication-approved, until all boxes are
recorded with measurements:

- [ ] Print/export at 1:1 and overlay face-to-face: Ø46 outline, all mounts, H2
      centers, and pin 1/VBUS orientation.
- [ ] Continuity-check Waveshare H2-8 and confirm GPIO16/GPIO18 labeling.
- [ ] Confirm fitted H2 gender, body height, engagement, pin-tail length, and
      solder protrusion before selecting the daughterboard header.
- [ ] Measure assembled board separation and Waveshare rear-part envelope;
      verify loaded BT1 against the conservative height bounds.
- [ ] Check bottom J1–J5 bodies and cable exits against the flush rear mount,
      plus real USB-C plug/cable access.
- [ ] Verify BMP280 vent/no-coat clearance and airflow exposure.
- [ ] Compare U1 Gerber pads to TI and supplier land patterns; run an independent
      PCB/Gerber shorts and clearance DRC.
- [ ] Power first from a current-limited bench supply. Verify polarity behavior,
      5.016 V nominal buck output, VBUS ORing, rail sequencing, sensor-short
      isolation, ADC clamps, I2C devices, ripple/load regulation, and thermal rise.
- [ ] Only after bench validation, exercise the intended 12 V automotive range
      and representative transients; set firmware MAP supply to measured
      `SENSOR_5V`.

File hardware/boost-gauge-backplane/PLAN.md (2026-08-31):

# Boost Gauge Backplane — tscircuit Implementation Plan

Self-contained prompt file for a fresh session. Read this file, then implement.
Original agent spec: `reference/agent-spec.md` (also at the upload path in the
task). All Phase-1 research is DONE; decisions are LOCKED (user-approved).
Do not re-open them. Do not touch firmware in this repo — this work is
additive under `hardware/boost-gauge-backplane/` only.

**2026-08-30 STATUS: source repair and automated PCB audit complete; physical
pre-order gates remain.** Sections §11 and earlier part selections are retained
as history where explicitly marked. The current implementation and audit are
summarized in §12 and `DESIGN_REVIEW.md`.

## 0. Toolchain state (verified this session)

- `bun` installed via `npm install -g bun` (tsci shebang needs it). `tsci` v0.0.2461 works.
- Skill: `/Users/chaotic/.agents/skills/tscircuit` (CLI.md, SYNTAX.md, FOOTPRINTS.md, templates/).
- Project dir exists: `hardware/boost-gauge-backplane/` with `reference/` containing:
  - `waveshare-esp32-s3-touch-amoled-1.75-schematic.pdf` (official, 3 pages)
  - `waveshare-esp32-s3-touch-amoled-1.75-dimensions.pdf` (official drawing, 1 page, 4 views)
  - `waveshare-esp32-s3-touch-amoled-1.75-dimensions.dwg` / `.step` (official CAD)
  - `agent-spec.md`
- This model cannot read PDFs directly. Convert pages with the Swift+CoreGraphics
  script pattern used in Phase 1 (render to PNG at 3x, crop with `sips`), or read
  the PNG crops. A working snippet: `swift /tmp/pdf2png.swift file.pdf outprefix`
  (see git history of this session / rewrite: CGPDFDocument → CGContext → NSBitmapImageRep).
- Bootstrap: `tsci init -y` inside `hardware/boost-gauge-backplane/`, or hand-write
  `package.json`/`tsconfig`/`tscircuit.config.json` + `index.circuit.tsx`.

## 1. Locked architecture decisions (user-approved)

| # | Decision | Choice |
|---|---|---|
| 1 | Stack topology | **Rigid stack off H2.** Waveshare H2 is a **female** 1×8 socket on the board's **bottom** face, axis parallel to the board (pins perpendicular to PCB, pointing away from screen). Backplane carries a **male** 1×8 pin header on its **top** face (the face toward the Waveshare) that plugs down into H2. |
| 2 | Mounting | **Reuse the Waveshare's own 3× M2 pattern.** Backplane has 3 unplated Ø2.2 mm holes with explicit copper keepouts at the exact Waveshare coordinates. Screw, standoff, solder-protrusion, and clamp-up dimensions remain physical validation gates; the mating spec does not define the required separation. |
| 3 | USB/VBUS backfeed | **Single Schottky (SS54) from buck output to VBUS_SHARED.** User asked why: even if car+USB are never simultaneous, plugging USB with the car OFF back-feeds the buck's output node and the 12V rail through the buck's body diode/high-side FET, and the sensor harness. One $0.10 diode makes USB power the display (and via the sensor branch, the bench) with zero contention. ~0.3–0.45 V drop → VBUS_SHARED ≈ 4.6–4.7 V, inside the firmware's 4.50–5.50 V MAP-supply setting. No jumper, no ideal-diode controller. |
| 4 | RTC backup | **BS-12-B2AA002 / C964721 horizontal SMT CR1220 holder, no charging circuit**, on the top/mating/inside face and `doNotPlace`. It is allowed there only after the assembled board gap proves loaded-cell clearance; otherwise relocate it to the outward face. Accept +85 °C cell limit and document hot-dashboard risk. |
| 5 | Sensor/power connectors | **JST-PH 2.0 mm** (user chose PH over GH): 4× B3B-PH-K-S (A0–A3) + 1× B2B-PH-K-S (12V/GND), all through-hole vertical, on the bottom (outward) face, near the perimeter. |
| 6 | Board | Ø46.00 mm round, 2-layer, JLCPCB fab/assemble. **TOP = Waveshare-facing/mating/inside; BOTTOM = enclosure/mount-facing/outward/back.** Put electronics on TOP where feasible; J1–J5 remain BOTTOM for cable access. BT1 is TOP only conditionally per decision #4. |
| 7 | BMP280 placement | **Top (Waveshare-facing) face**, near the perimeter edge — user override. Prevents cabin AC vent airflow from blowing directly onto the vent hole. All other ICs also prefer top face if space allows; connectors remain bottom-only. |
| 8 | Assembly mode | **JLCPCB partial assembly.** JLC installs: ADC, pressure sensor, RTC, buck circuitry, MOSFETs, level shifter, resistors, capacitors, inductor, TVS, fuses, diodes. User hand-solders (doNotPlace): 8-pin display header, 4× sensor connectors (J2–J5), 12V power connector (J1), battery holder (BT1). |
| 9 | Geometry source | **`reference/WAVESHARE_1_75_MECHANICAL_MATING_SPEC.md` supersedes PLAN §4.** Verified coordinates: mounts (0,+20.50)/(±13.75,−14.70); H2 row centerline Y=−18.68, X-center 0, pins −8.89…+8.89 @2.54 pitch. PLAN §4's old numbers (±18.30/+12.80, 0/−20.50, header centerline −12.70/row −13.75) are **WRONG — discard**. User physical observation (rear view: VBUS rightmost, GPIO18 leftmost, USB-C right side) confirms spec's rear-view frame. USB-C notch: keep +X perimeter open instead of cutting the outline. |
| 10 | Daughterboard transform | Face-to-face mirror: **X_db = −X_assembly, Y unchanged.** In backplane top-view coords the H2 row is therefore **pin 1 (VBUS) at (−8.89, −18.68) … pin 8 (GPIO16) at (+8.89, −18.68)**, and the USB-C keepout moves to the **left edge (X ≈ −23, Y ≈ 0)**. Mount holes are symmetric, unchanged. Confirmed by user's physical observation. |

## 2. Verified firmware constraints (read from `main/boost_sensors.c/.h` this session)

- Sensor I²C: port 0, **SDA=GPIO17, SCL=GPIO18, 100 kHz**, proven with ~4.7 kΩ pull-ups.
- **ADS1115 @ 0x48** (ADDR→GND), A0 single-ended, **±6.144 V FSR**, continuous 250 SPS, **VDD = ~5 V** (GM MAP swings to ~4.8 V).
- **BMP280 @ 0x76** (SDO→GND), 3.3 V, firmware requires chip id **0x58** (no BME280/BMP3xx substitution).
- **DS3231 @ 0x68** on the same bus; firmware handles OSF, 2.3–5.5 V supply OK.
- MAP supply config 4.50–5.50 V (default 5.20 V) → **record measured SENSOR_5V in firmware/NVS after first build; no code change needed.**
- H2 GPIOs are 3.3 V, not 5 V tolerant. GPIO17/18 pull-ups must be on the **3V3** side only.

## 3. Waveshare H2 pinout (official schematic page 1, right side)

| H2 pin | Signal | Backplane net |
|---|---|---|
| 1 | VBUS (5 V) | VBUS_SHARED (via SS54 ORing anode side) |
| 2 | GND | GND |
| 3 | 3V3 | 3V3_WAV (input; powers BMP280/RTC/translator low side + pull-ups) |
| 4 | GPIO44 / U0RXD | TP only |
| 5 | GPIO43 / U0TXD | TP only |
| 6 | GPIO17 = SDA | I2C_SDA_3V3 |
| 7 | GPIO18 = SCL | I2C_SCL_3V3 |
| 8 | GPIO16 | TP only |

**Pin-1 orientation — RESOLVED 2026-08-29.** The uploaded mating spec gives the
authoritative rear/component-side view: pin 1 (VBUS) at X=+8.89 (USB-C side),
pin 8 (GPIO16) at X=−8.89. The user's physical observation (rear view: VBUS
rightmost, GPIO18 leftmost, USB-C right) confirms this frame. The old
front-view mirror derivation below is kept only as audit trail — **discard it.**
→ Pre-fab check remains: face-to-face assembly rendering / 1:1 print overlay
per spec §7's mandatory validation rule (mating contact → H2 pin 1 → VBUS).

## 4. Mechanical geometry — **SUPERSEDED by decision #9**

The authoritative source is now `reference/WAVESHARE_1_75_MECHANICAL_MATING_SPEC.md`.
Old PLAN numbers below are retained only for audit trail; **do not use them.**

<details><summary>Old (incorrect) geometry — click to expand</summary>

Origin = board center, +X right, +Y up, **viewed from the FRONT of the Waveshare** unless noted.

- PCB outline: **Ø46.00 mm** (display OD 48.96, AA 43.76 — irrelevant to PCB).
- H2 (female): 1×8 @ 2.54 mm; **centerline at X = −12.70 mm, row at Y = −13.75 mm** (front view),
  axis along X. Pin 1 at the +X end of the row (front view).
- Mounting: **3× M2-H3.5 tapped holes** at **(−18.30, +12.80), (+18.30, +12.80), (0.00, −20.50)** (front view).
  (Drawing also shows 18.68/14.70/23.00/23.80 chains — the ±18.30/+12.80/0/−20.50 set is what the
  photo dimension lines point to; VERIFY per §5.)
- **2× 1.80 mm case-tab slots** near the USB-C end (photo: ~X +15.00, Y −16.50 region). Not needed
  on the backplane; just keep the perimeter clear there.
- **USB-C**: right edge of the board, on the horizontal centerline (Y ≈ 0). The plug extends
  radially outward in the board plane → **the backplane disc needs an edge notch/cutout at the
  USB-C corner** (~10 mm wide × ~5 mm deep at X≈+23, Y≈0) or the plug body collides with the
  backplane edge. Extend the notch to keep the PWR/BOOT edge buttons and the user's mount
  button cutouts usable. VERIFY with a real cable.
- Stack clearance: standard 1×8 female body ≈ 8.5 mm; male header tail engages it. **Top-face
  keepout on the backplane: nothing taller than ~4 mm anywhere within Ø44** (Waveshare bottom
  has TF slot, MX1.25 connectors, ESP32-S3 shield ~1.3 mm, flash ~1.5 mm). Buck/inductor/TVS/FET/
  diodes: SO-8/SMA/SOT-23 are ≤2 mm — fine on top. Coin holder, JST connectors, battery, tall caps:
  **bottom face only**.
- Backplane top-view coordinate transform (backplane's own PCB coords, viewed from its TOP):
  X_bp = −X_front, Y_bp = +Y_front (both boards viewed from the mating side). Header row:
  **Y_bp = −13.75, centerline X_bp = +12.70, pin 1 at X_bp = 12.70 − 3.5×2.54 = +3.81, pin 8 at +21.59.**
  Mount holes (symmetric set, unchanged): (±18.30, +12.80), (0, −20.50).

</details>

**Corrected geometry (from `WAVESHARE_1_75_MECHANICAL_MATING_SPEC.md`):**

- Outline: Ø46.00 mm circle, center (0,0). Rear-view coordinate frame (+X = USB-C side,
  +Y = speaker/battery side, −Y = H2 side).
- Mounts: **(0, +20.50), (−13.75, −14.70), (+13.75, −14.70)** — Ø2.2 mm NPTH.
- H2: 1×8 @ 2.54 mm, row centerline **Y = −18.68**, X-center **0**. Pins at X = ±1.27, ±3.81,
  ±6.35, ±8.89. Rear-view pin order (left→right): GPIO16, GPIO18, GPIO17, U0TXD, U0RXD, 3V3,
  GND, VBUS. Pin 1 (VBUS) at X=+8.89 (USB-C side).
- USB-C: **+X perimeter**. Do NOT cut a notch into the backplane outline (spec §11 says keep
  perimeter open; PLAN's notch idea discarded). Instead: no tall parts near +X edge; the
  backplane is clamped behind by screws, USB plug routes around/below the disc edge.
- 2×1.80 features: ignore per spec §13.
- Inter-board height is undefined by the mating spec. It must be established from
  the tallest Waveshare rear part, the selected H2 stack, screws/standoffs, solder
  protrusion, and daughterboard parts. Electronics are on TOP/inside where feasible;
  J1–J5 remain BOTTOM/outward. BT1 on TOP is conditional on the measured gap.

## 5. Geometry verification procedure (do BEFORE ordering, user-assisted)

**2026-08-29 UPDATE: the uploaded `WAVESHARE_1_75_MECHANICAL_MATING_SPEC.md`
supersedes this section's old numbers.** That spec is a verified extraction from
the official dimension drawing and gives exact rear-view coordinates for the
three mounts and the H2 header (see corrected geometry in §4). The remaining
pre-order check is the 1:1 print overlay + caliper verification per that spec's
§15 (circle Ø46.00, mount spacing 27.50, H2 row Y=−18.68, pitch 2.54, pin-1=VBUS).

1. Export the backplane mechanical layer at 100% scale (1:1).
2. Verify with calipers: circle Ø46.00, bottom mount spacing 27.50, top mount
   Y +20.50, bottom mounts Y −14.70, H2 pitch 2.54, H2 row Y −18.68.
3. Place the actual Waveshare PCB over the print; verify the three mount
   centers and all eight H2 pin centers.
4. Verify pin-1/VBUS orientation face-to-face (not from separate top views).
5. Only then order PCBs. Record results in DESIGN_REVIEW.md.

## 6. Schematic / netlist plan

Rail names (spec §Phase 2): `CAR_12V_RAW`, `CAR_12V_PROTECTED`, `BUCK_5V_RAW`, `VBUS_SHARED`,
`SENSOR_5V`, `3V3` (= H2 3V3 input, name `3V3_WAV`), `I2C_SDA_3V3`, `I2C_SCL_3V3`,
`I2C_SDA_5V`, `I2C_SCL_5V`, `GND`.

### Blocks (use `<schematicsection />` per block)

**A. Automotive input / protection**
- J1 2P JST-PH: `12V_IN`, `GND` (bottom face, perimeter, away from BMP280).
- F1 input fuse 2 A — **RESOLVED: `0466002.NRHF` C3105 (2 A/63 V SMD 1206, stock 94,916)**.
- D1 TVS **SMBJ16CA** (C353385, bidirectional) at CAR_12V_RAW→GND; normal operation is for a
  12 V automotive system, not continuous 24 V input.
- Q1 reverse-polarity high-side P-MOS **DMP4065S-7** (C182476, 40 V): drain=CAR_12V_RAW,
  source=CAR_12V_PROTECTED, gate→GND via 100 kΩ, 10 V zener gate-to-source.
- Input bulk: 2× 22 µF/50 V X7R 1210 + 100 nF at buck VIN. (Ceramic only — no electrolyte in a car.)

**B. Buck 12 V → 5 V**
- U1 **LMR36520ADDAR** (C2879422, 4.2–65 V in, 2 A out, 400 kHz, SOP-8/PowerPAD). Alt:
  MP9943GQ-Z (C477821, 36 V/3 A QFN) — keep LMR36520 as primary (65 V headroom = real load-dump
  margin; MP9943's 36 V needs the TVS to do all the clamping).
- L2 10 µH shielded (FXL0530-100-M C177248, 5.4×5.2×3 mm) on TOP.
- FB divider → 5.016 V. The synchronous converter uses a 100 nF BOOT-to-SW capacitor;
  no external catch or boot diode is fitted.
- Output: 2× 22 µF 0805/1210 X5R + 100 nF.
- **Layout: buck cluster in one sector; ≥8 mm from BMP280, ADS1115, RTC, sensor connectors.**

**C. Power path / VBUS**
- D2 **SS54** (C22452) anode=BUCK_5V_RAW → cathode=VBUS_SHARED → H2 pin 1.
- SENSOR_5V branch: VBUS_SHARED → F2 (nSMD050-24V C70076, 500 mA hold / 1 A trip) → SENSOR_5V.
  Powers: ADS1115 VDD, TCA9406 VHB, 4× sensor connector
  pin 1. A shorted engine-bay harness then browns out only the sensor rail, not the display.
- USB case: USB → Waveshare AXP2101 VBUS = H2 pin 1 = VBUS_SHARED; D2 blocks backfeed into the
  buck. Sensor rail is bench-powered from USB through D2's... NO — D2 is one-way INTO VBUS_SHARED,
  so USB also feeds SENSOR_5V via F2 (reverse-powered from H2). That's desired (spec §4: bench
  power OK) and safe (F2 limits). Document in README.

**D. I²C translation**
- U2 **TCA9406DCTR** (C337496, MSOP-8, 2-bit, auto-direction, Hi-Z when either rail is 0 V —
  satisfies the "sensor rail off, 3V3 alive" requirement). VCCA=3V3_WAV, VCCB=SENSOR_5V.
- Pull-ups 4.7 k on all four nets (SDA/SCL × 3V3/5V sides). 3V3-side pull-ups to 3V3_WAV only.
- A-side: H2 GPIO17/18. B-side: ADS1115 only.

**E. ADC**
- U3 **ADS1115IDGSR** (C37593, VSSOP-10). VDD=SENSOR_5V, ADDR→GND, decoupling 100 nF+1 µF at pins.
- A0–A3: each channel: connector pin 3 → ESD clamp BAV99 (**C916421**; alt 2× 1N4148WS C2128)
  to SENSOR_5V/GND → series 1 kΩ → 100 nF to GND at the ADC pin. RC fc ≈ 1.6 kHz (≫ 62.5 Hz
  gauge rate, fine for boost transients; document). 12 V-on-signal-wire fault: clamp + 1 kΩ limit
  current; verify ADC pin abs-max with the diode clamp math in DESIGN_REVIEW.
- No divider — 0–5 V scaling preserved.

**F. Ambient**
- U4 **BMP280** (C83291, LGA-8). 3V3_WAV, SDO→GND (0x76), CSB→3V3 (I²C mode). **Top
  (Waveshare-facing) face, perimeter edge — user decision #7** (AC vent protection), opposite
  sector from the buck, vent unobstructed, no copper/noise under it, silkscreen
  "DO NOT COVER / NO CONFORMAL COAT" ring + keepout note.

**G. RTC**
- U5 **DS3231MZ+** (C107410, SOIC-8, 2.3–5.5 V, 0x68). VCC=3V3_WAV, VBAT=coin cell + (direct,
  no charger, no series diode — MZ datasheet allows). BT/OSF handled by firmware.
- BT1 CR1220 holder (BS-12-B2AA002 C964721) — **user hand-solders (decision #8)**,
  top/mating face only after measured clearance; **+** pad silkscreened; 100 nF at VCC.
- Note in DESIGN_REVIEW: DS3231M vs old SN is register-compatible at 0x68 (firmware uses
  STATUS/OSF + time regs only — verified against `boost_sensors.c` DS3231 paths this session).

**H. Test points** (top face where reachable, else bottom): TP for CAR_12V_RAW,
CAR_12V_PROTECTED, BUCK_5V_RAW, VBUS_SHARED, SENSOR_5V, 3V3_WAV, GND, I2C_SDA_3V3,
I2C_SCL_3V3, I2C_SDA_5V, I2C_SCL_5V, A0–A3 (post-filter), GPIO16, U0RX, U0TX.

## 7. Part sourcing summary (all LCSC-verified in stock this session)

| Ref | MPN | LCSC | Role | Alt |
|---|---|---|---|---|
| U1 | LMR36520ADDAR | C2879422 | buck 65 V/2 A | MP9943GQ-Z C477821 |
| U2 | TCA9406DCTR | C337496 | I²C translator | PCA9306DCUR C33196 (verify unpowered behavior) |
| U3 | ADS1115IDGSR | C37593 | ADC | ADS1115BQDGSRQ1 C2868291 (auto grade) |
| U4 | BMP280 | C83291 | ambient | none (firmware chip-id lock) |
| U5 | DS3231MZ+TRL | C107410 | RTC | DS3231SN C9866 (SO-16, bigger) |
| Q1 | DMP4065S-7 | C182476 | 40 V reverse polarity | — |
| D1 | SMBJ16CA | C353385 | bidirectional input TVS | — |
| D2 | SS54 | C22452 | VBUS ORing | SS34 C8678 |
| L2 | FXL0530-100-M | C177248 | 10 µH buck inductor | — |
| F2 | nSMD050-24V | C70076 | 500 mA hold / 1 A trip sensor PTC | — |
| J2–J5 | B3B-PH-K-S(LF)(SN) | C131339 | sensor connectors | — |
| J1 | B2B-PH-K-S(LF)(SN) | C131337 | 12 V input | — |
| BT1 | BS-12-B2AA002 | C964721 | CR1220 holder | C5239868 gold |
| passives | 0603/1210, 4.7k/1k/100k, 100nF/1µF/22µF-X5R-50V | various | — | — |

**Open sourcing items — RESOLVED 2026-08-29 (all LCSC-verified in stock):**
1. **F1 input fuse**: `0466002.NRHF` **C3105** — 2 A / 63 V SMD fuse 1206, stock 94,916. No THT fallback needed.
2. **F2 sensor-branch PTC**: `nSMD050-24V` **C70076** — 500 mA hold / 1 A trip.
3. **Gate zener**: `LBZX84C10LT1G` **C12772** — 10 V SOT-23.
4. **Analog clamp**: `BAT54S,235` **C503463** — Schottky series pair.
5. **H2 mating header**: 1×8 2.54 mm THT — hand-solder (`doNotPlace`); gender and fitted
   stack height must be confirmed on the physical Waveshare before ordering.
6. **Test points**: `<testpoint />` pads (no BOM part).

**Assembly mode (user decision #8): JLCPCB partial assembly.**
JLC installs: all ICs, buck circuitry, MOSFET, translator, TVS, fuses, diodes,
inductor, resistors, capacitors. User hand-solders (doNotPlace): H2 1×8 header,
J1–J5 JST-PH connectors, BT1 CR1220 holder.

## 8. tscircuit implementation steps

1. `tsci init -y` in `hardware/boost-gauge-backplane/`.
2. Build the form factor: circular Ø46 outline, 3× Ø2.2 `<hole />` at the corrected
   coordinates, H2 at the corrected top-view coordinates, and a left-edge USB keepout.
   The authoritative outline has no USB notch; verify the Gerber and a real plug.
3. Schematic: one file per section or `<schematicsection />` groups; import parts with
   `tsci import "C..."` (JLCPCB footprints come with LCSC mapping) — do NOT hand-invent
   footprints; registry has none for these (checked: `tsci search "waveshare"` → nothing usable).
4. `tsci check netlist` → fix → `tsci check schematic-placement` → `tsci check placement` →
   `tsci build --pcb-png dist/placement.png` → manual inspect both faces →
   `tsci check routing-difficulty` → `tsci build` (autoroute) → `tsci check shorts` (must pass) →
   manual Gerber-outline/holes inspection (`tsci export` / `--help` for gerber flags).
5. Power nets: `<net>`-based routing intent + wide traces (≥0.5 mm on 5 V, ≥0.8 mm on 12 V),
   GND pour both layers and thermal vias under the LMR36520 PowerPAD.
6. If the autorouter can't close, hand-route the buck hot loop with `<trace />` + `<via />`
   first, then re-run.

## 9. Deliverables (spec §21) — all in `hardware/boost-gauge-backplane/`

source `.tsx` files, form-factor component, `dist/` renders (top/bottom/schematic/3D),
Gerbers + drill + BOM + CPL (or exact `tsci export` commands that produce them),
`README.md` (architecture, H2 pinout incl. mirror explanation, power path + USB caveat,
connector pinout table, I²C addresses 0x48/0x76/0x68, RTC battery, assembly notes,
bring-up procedure from spec §20), `DESIGN_REVIEW.md` (assumptions, load-dump math, buck
thermals at 46 mm, Vgs/zener check, RC filter fc, sensor-rail short behavior, CR1220 temp
risk, unresolved fuse sourcing, geometry-verification results), firmware note:
**no firmware change required; only set MAP-supply NVS to measured SENSOR_5V (~4.6–4.7 V
car / ~4.9 V USB-bench).**

## 10. Acceptance gates (do not claim done without)

- [ ] §5 geometry verification performed on the physical board, numbers recorded.
- [ ] `tsci check netlist`, `check placement`, `check schematic-placement`, `build`, `check shorts` all clean.
- [ ] Gerber edge = Ø46.00; 3 holes match mount; header not mirrored (pin-1 square pad lands on VBUS face-to-face).
- [ ] Measure the complete stack. Verify every TOP/inside component and the loaded BT1 against
      the real inter-board gap; keep J1–J5 BOTTOM/outward and verify cable access against the mount.
- [ ] Every BOM line has a real LCSC number (or documented hand-solder exception).
- [ ] BMP280 on the Waveshare-facing face at perimeter (user decision #7), ≥8 mm from buck, vent keepout + silkscreen warning.
- [ ] GPIO17/18 pull-ups on 3V3 side only; ADS1115 5 V side only; translator = TCA9406.
- [ ] README + DESIGN_REVIEW written; commit under `hardware/` only.

## 11. Historical intermission state (2026-08-29) — superseded by §12

This section records the state that was inherited by the final audit. Its part
choices and “not yet done” list are not current instructions.

**Done this session:**
- `tsci init -y` complete (tscircuit 0.0.2461, bun present).
- All 15 part imports in `imports/` (LCSC footprints verified 98.8–100% IoU):
  LMR36520ADDAR, TCA9406DCTR, ADS1115IDGSR, BMP280, DS3231MZ_TRL, AO3401A,
  SMBJ16A, SS54, FXL0530_4R7_M, B3B/B2B-PH-K-S, BS_12_B2AA002, BZX84_C12_215,
  BAV99 (C916421), BAT54S (C7420333, spare), A_0466002_NRHF (fuse).
- `index.circuit.tsx`: full netlist, blocks A–H, `tsci check netlist` = 0 errors /
  0 warnings. Only genuine datasheet no-connects float (BZX84 NC, ADS1115 pin2,
  DS3231MZ 32kHz/N_RST stub).
- Sourcing resolved (see §7): F1 = 0466002.NRHF C3105 (SMD fuse, no THT fallback
  needed); F2 = BSMD1206-200-12V C883135; zener = BZX84-C12,215 C108437;
  clamp = BAV99 C916421.
- Geometry superseded by `reference/WAVESHARE_1_75_MECHANICAL_MATING_SPEC.md`
  (user-confirmed rear view: VBUS rightmost, GPIO18 leftmost, USB-C right).
- PDF vector extraction tooling built (`/tmp/pdfgeom.c`); dimension drawing
  confirmed Ø46 outline, no mounting holes drawn in the top view (they live in
  the spec's numbers), side-view extracted for stack-height analysis.
- User decisions #7 (BMP280 top face) and #8 (JLC partial assembly) recorded in §1.

**Not yet done (next session):**
1. Schematic fixes: D2 currently wired as boot diode — must be the VBUS ORing
   (A=BUCK_5V_RAW → K=VBUS_SHARED); add a proper CBOOT (100 nF BOOT→SW); FB
   divider values must give 5.00 V exactly per LMR36520 equation (R3/R4 = 52.3k
   was a placeholder; recompute: Vout = 0.6×(1+R3/R4) with LMR36520's FB ref —
   verify against datasheet and adjust R3/R4).
2. `<fuse name="F2" />` has no supplier pinned — replace with a `chip` on the
   C883135 footprint (BSMD1206-200-12V) or `supplierPartNumbers`.
3. Form-factor component `WaveshareBackplane46.circuit.tsx` per mating spec §14:
   Ø46 circle outline (polygon, 72 segments), 3× Ø2.2 NPTH `<hole />` at
   (0,+20.50)/(±13.75,−14.70), H2 `<pinheader pinCount={8} pitch="2.54mm">`
   centered (0,−18.68), USB-C keepout marker on +X, center datum marker.
4. Merge form factor into `index.circuit.tsx`; place per §4 sector rules
   (buck SW/inductor cluster ≥8 mm from BMP280/ADS/RTC/connectors; BMP280 top
   face perimeter per decision #7; tall parts bottom face per decision #8;
   J1/J2–J5/BT1/H2 `doNotPlace` for JLC, hand-solder).
5. Checks → placement → routing (§8 steps 4–6) → shorts → renders → Gerbers.
6. README.md + DESIGN_REVIEW.md (load-dump math, Vgs/zener check, RC fc,
   sensor-rail short behavior, CR1220 temp risk, geometry-verification results,
   assembly-mode BOM/CPL split).

**Key file state:** `index.circuit.tsx` is the working schematic (netlist
clean); `imports/` has all 15 parts; `reference/` has the mating spec + PDFs.

**2026-08-29 intermission addendum (post-geometry-resolution):**
- Mating spec copied to `reference/WAVESHARE_1_75_MECHANICAL_MATING_SPEC.md`.
- User physically confirmed the spec's rear-view frame (rear view: VBUS
  rightmost, GPIO18 leftmost, USB-C right side). PLAN §3's old mirror derivation
  is superseded; §5 rewritten to the spec's §15 caliper/overlay procedure.
- Daughterboard transform (decision #10): X_db = −X_assembly, Y unchanged.
  In tscircuit top-view coords: H2 pin 1 (VBUS) at (−8.89, −18.68) … pin 8
  (GPIO16) at (+8.89, −18.68); USB-C keepout on the LEFT edge (X≈−23, Y≈0).
- BOM/CPL split for JLC partial assembly (decision #8): source marks J1–J5,
  H2, and BT1 `doNotPlace`, but tscircuit still emits them in raw BOM/CPL. The
  release filter removes those seven refs plus all PCB-only `TP_*` pads.
- F2 was subsequently resolved as nSMD050-24V C70076, 500 mA hold / 1 A trip.

## 12. Repair and audit state (2026-08-30)

The final source uses the corrected input topology, bidirectional SMBJ16CA,
40 V DMP4065S-7 P-MOS, 10 µH inductor, two 22 µF output capacitors, 500 mA-hold
sensor PTC, exact supplier copper for U2/U3/U5, close RTC/BMP/ADC/buck bypassing,
named-width power/I²C nets, dual GND pours, and explicit critical routes. H2 is
a real `<pinheader>`. TOP is the inside/mating face; only J1–J5 are BOTTOM.
BT1 is the horizontal SMT CR1220 holder on TOP and is conditional on measured
stack clearance.

Final verified `dist/index/circuit.json`:

- 128 routed connections, 142 PCB traces, 106 vias, 0 router errors.
- 0 circuit error records, 0 long-trace warnings, 0 unrouted records.
- `tsci check netlist`: 0 errors / 0 warnings.
- `tsci check placement`: 0 errors; three horizontal-access advisories on
  vertical/top-entry bottom JST-PH connectors remain a physical cable-access gate.
- `tsci check source`: 0 errors / 0 warnings.
- `tsci check shorts --mode pcb` is **toolchain-blocked**: tscircuit 0.0.2461
  throws `layerCanvas.getContext is not a function`; it failed identically twice.
- Schematic autolayout reports cosmetic overlaps/label routing. The electrical
  netlist is clean, but the generated schematic is an audit aid rather than a
  publication-quality drawing.
- One U1 supplier-footprint IoU warning remains (0.7255). Fresh exact import
  copper matches the local wrapper, but it still requires a manual TI/JLC land-
  pattern check rather than suppressing the warning.

Staged manufacturing outputs are exported from the verified circuit JSON so no
second autoroute is introduced. Raw BOM/CPL contain 73 designators; filtered JLC
files contain 48 placed parts and exclude exactly the seven hand-solder refs plus
17 `TP_*` PCB-only pads. All 48 filtered BOM rows have supplier IDs and the
filtered BOM/CPL designator sets match.

The STEP exporter emits a board model but its parser rejects several downloaded
supplier models. DNP bodies—including BT1, H2, and J1–J5—also do not establish
the assembled envelope. STEP therefore cannot prove stack or mount clearance.

**Remaining physical/pre-order gates:**

- [ ] 1:1 face-to-face overlay: outline, mounts, H2 pitch, pin 1 → VBUS.
- [ ] H2-8 continuity, fitted gender, selected header stack height, solder
      protrusion, screws/standoffs, and actual inter-board separation.
- [ ] Loaded BT1 clearance. Treat 4.10 mm as the likely installed-holder envelope
      and 6.10 mm only as a conservative additive bound until a physical section
      confirms how the 2.0 mm cell nests.
- [ ] Bottom J1–J5 connector bodies and cable exits against the flush rear mount;
      USB-C plug/cable access; BMP280 vent/no-coat clearance.
- [ ] Manual U1 land-pattern comparison and independent PCB-short DRC.
- [ ] Bench bring-up over the intended 12 V automotive operating range: polarity,
      transients, rail sequencing, sensor short, output ripple/load, and thermal.

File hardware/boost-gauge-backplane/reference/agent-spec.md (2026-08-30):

# tscircuit AI Agent Specification — Waveshare Boost Gauge 46 mm Backplane PCB

## Mission

Use **tscircuit** to design a compact, manufacturable round daughterboard/backplane PCB for this project:

**Repository:** `https://github.com/ZiadAbdelati/waveshare-boost-gauge`

The new board replaces the collection of electronics currently housed separately from the display. It must mount directly behind the **Waveshare ESP32-S3-Touch-AMOLED-1.75** and electrically mate through the Waveshare board's rear **8-pin, 2.54 mm expansion header (H2)**.

The goal is a clean, self-contained gauge electronics stack that can be powered from the vehicle and connect directly to external analog automotive sensors.

Do not treat this as a generic ESP32 sensor board. Preserve compatibility with the firmware and electrical assumptions already implemented in the repository unless this specification explicitly allows a change.

---

# 1. Required research before designing

Before selecting components or placing anything, inspect and understand the following source material.

## Project repository

Read at minimum:

- `README.md`
- `docs/sensors-and-calibration.md`
- `docs/troubleshooting/i2c-sensor-bus.md`
- `main/boost_sensors.c`
- `main/boost_sensors.h`

Confirm the current firmware behavior rather than guessing.

Important existing firmware constraints include:

- Dedicated external sensor I²C bus:
  - **SDA = GPIO17**
  - **SCL = GPIO18**
  - **100 kHz**
- ADS1115:
  - address **0x48**
  - `ADDR -> GND`
  - MAP sensor on **A0**
  - powered from the sensor ~5 V rail
  - firmware uses the **±6.144 V PGA range**
  - continuous conversion at 250 SPS
- BMP280:
  - address **0x76**
  - `SDO -> GND`
  - must remain on **3.3 V logic**
  - firmware expects a real BMP280 chip ID, so do not silently substitute a BME280/BMP3xx without a firmware change
- External RTC:
  - firmware currently expects a **DS3231-compatible device at 0x68**
- MAP sensor:
  - GM 12223861 3-bar MAP
  - nominal 5 V ratiometric sensor
- Firmware MAP supply setting:
  - configurable range is **4.50–5.50 V**
  - current default is **5.20 V**
  - the final PCB's actual sensor rail voltage must be reflected in firmware/NVS calibration

The existing I²C troubleshooting documentation also establishes that **100 kHz and roughly 4.7 kΩ pull-ups are intentional and proven in the vehicle environment**. Preserve the 100 kHz design target.

## Waveshare hardware

Use the official Waveshare schematic, hardware reference, and dimension drawing for the **standard ESP32-S3-Touch-AMOLED-1.75** as the mechanical/electrical source of truth.

Important facts to verify:

### Board geometry

- Main PCB outline: **46.00 mm diameter**
- 8-pin header pitch: **2.54 mm**
- Reproduce the Waveshare mounting-hole and H2 locations from the official dimension drawing.
- Do not estimate the mounting-hole or header XY positions from a product photo.

### H2 expansion header pinout

Pin numbering follows the Waveshare schematic:

| H2 pin | Waveshare signal | Use on this daughterboard |
|---|---|---|
| 1 | VBUS | Display/shared ~5 V power |
| 2 | GND | Ground |
| 3 | 3V3 | 3.3 V logic reference / low-power peripheral rail |
| 4 | GPIO44 / U0RXD | Normally unused; optional test pad |
| 5 | GPIO43 / U0TXD | Normally unused; optional test pad |
| 6 | GPIO17 | **Sensor I²C SDA** |
| 7 | GPIO18 | **Sensor I²C SCL** |
| 8 | GPIO16 | Spare GPIO / optional test pad |

All GPIO pins are 3.3 V logic and are **not 5 V tolerant**.

The standard board also already contains a PCF85063 RTC on the Waveshare onboard I²C bus, but the existing boost-gauge firmware uses an external DS3231 on GPIO17/18. Do not remove the external RTC merely because the Waveshare board has its own RTC unless you deliberately implement and document the required firmware/power changes.

---

# 2. Overall board architecture

Create a **46.00 mm round PCB** that stacks directly behind the Waveshare board.

The board needs these functional blocks:

1. Vehicle 12 V input and protection
2. 12 V -> approximately 5 V buck conversion
3. Power injection into Waveshare H2 VBUS
4. Protected ~5 V rail for external sensors
5. ADS1115 4-channel ADC
6. 3.3 V <-> 5 V bidirectional I²C level translation
7. BMP280 ambient pressure sensor
8. Battery-backed RTC, preferably DS3231-compatible
9. External analog sensor connectors
10. Test points / bring-up access
11. Mechanical mating header and matching mounting holes

No separate MCU is required. The Waveshare ESP32-S3 remains the controller.

---

# 3. Automotive 12 V input and power protection

This board will be installed in a car. Do **not** feed raw automotive 12 V directly into a cheap low-voltage buck stage.

Design a compact automotive-tolerant input front end.

## Continuous operating target

Design around a nominal 12 V vehicle system:

- approximately 6–18 V operating input if practical
- normal charging voltage around 13.5–14.8 V
- survive realistic reverse-polarity and transient events

This is not required to be formally ISO 7637 certified, but it should be engineered like an automotive accessory rather than a bench project.

## Required input protection

Include and justify:

- input fuse or resettable PTC
- reverse-polarity protection
  - preferably MOSFET/ideal-diode style if practical
  - Schottky is acceptable only if the loss/thermal penalty is justified
- automotive TVS protection near the power connector
- input bulk capacitance
- local high-frequency decoupling
- optional ferrite/LC/pi filtering if useful
- buck converter with enough input-voltage headroom for a protected automotive rail

Prefer a regulator with:

- **at least 36 V absolute maximum**, preferably **42–60 V**
- at least **2 A output capability**
- good efficiency at the expected load
- practical thermal performance on a 46 mm PCB
- current JLCPCB/LCSC availability

Do not use a regulator that is only barely rated above normal alternator voltage.

Follow the regulator datasheet layout closely. Keep the switch node physically small and keep the switching-power area away from the BMP280, ADC inputs, RTC, and analog connectors.

---

# 4. 5 V power architecture and USB backfeed

This requirement is important.

Waveshare **H2 pin 1 is VBUS**, and the official schematic shows that it is the same USB supply domain used by the display board. A naïve hard connection between the new buck output and H2 VBUS can create reverse-current/backfeed problems when USB-C is connected to a computer for flashing.

Design and explicitly document a safe power-path strategy.

## Preferred behavior

- Vehicle power present, no USB:
  - daughterboard powers the display through H2 VBUS
  - daughterboard powers the ADS1115 and external sensor rail
- Vehicle power absent, USB-C connected:
  - USB can power the Waveshare board
  - it should not reverse-power the vehicle buck converter or 12 V input circuitry
  - ideally the sensor/ADC side may also be bench-powered from VBUS if the power architecture allows it safely
- Vehicle and USB both connected:
  - avoid unsafe source contention/backfeeding

A practical architecture may use:

- a reverse-blocking diode / Schottky / ideal-diode stage between the vehicle buck output and shared VBUS,
- deliberate source priority,
- and/or a clearly documented disconnect jumper if fully automatic power ORing is not practical in the available space.

Do **not** leave the final design as a direct, unprotected buck-output-to-USB-VBUS tie.

If the vehicle-powered H2 rail ends up slightly below 5.00 V because of the power-path device, that is acceptable as long as:

- it remains inside the Waveshare board's valid supply range,
- the GM sensor remains within its useful supply range,
- the ADS1115 remains correctly powered,
- and the actual sensor supply voltage is reflected in the boost-gauge firmware setting/calibration.

The firmware already supports a MAP sensor supply from 4.50 to 5.50 V.

---

# 5. Sensor 5 V rail

Create a clean sensor rail derived from the shared ~5 V supply.

This rail powers:

- ADS1115 VDD
- external 5 V sensor connector pins
- high-voltage side of the I²C translator

Consider a small current-limited load switch or resettable fuse for the external sensor branch so a short in an engine-bay sensor harness does not necessarily reboot the display.

If the sensor rail can be independently powered off while the Waveshare 3.3 V rail remains alive, the I²C translator must support that state without back-powering the 5 V side.

---

# 6. ADS1115

Use a bare ADS1115 IC, not a breakout module.

Required configuration:

- `VDD = sensor ~5 V`
- `GND = common ground`
- address = **0x48**
- `ADDR -> GND`
- A0 = existing GM 3-bar MAP sensor
- expose A1, A2, and A3 for future sensors
- firmware currently samples A0 single-ended at ±6.144 V full scale

Use correct local decoupling immediately adjacent to the device.

Do not power the ADS1115 at 3.3 V unless you intentionally redesign the analog front end and firmware, because the existing project expects approximately 0–5 V automotive sensor signals.

---

# 7. Analog sensor connectors

The daughterboard should expose the ADS1115 analog channels on compact, keyed/locking 3-pin connectors accessible from the outward/back side of the PCB.

Preferred connector assignment:

| Connector | Pin 1 | Pin 2 | Pin 3 |
|---|---|---|---|
| SENSOR_A0 | +5V_SENSOR | GND | ADS A0 |
| SENSOR_A1 | +5V_SENSOR | GND | ADS A1 |
| SENSOR_A2 | +5V_SENSOR | GND | ADS A2 |
| SENSOR_A3 | +5V_SENSOR | GND | ADS A3 |

A0 is mandatory because it is the existing MAP input.

Strongly prefer exposing all four ADS1115 channels. If four 3-pin connectors physically cannot fit without compromising the board, keep A0 and as many additional channels as possible, but **do not silently delete channels**. Document the mechanical tradeoff.

Use the same pin order and orientation on every sensor connector.

Prefer a compact locking connector family that is realistic on a 46 mm board, for example JST-PH/JST-GH or another well-supported equivalent. Choose based on space, current rating, assembly availability, and ease of harness construction.

Clearly label each connector and pin function on silkscreen.

---

# 8. Analog input filtering and fault protection

Each exposed analog channel will leave the PCB and enter an automotive wiring harness.

Add modest input protection without materially changing the expected 0–5 V signal.

For each A0–A3 input, evaluate:

- small series resistor
- small RC low-pass filter
- low-leakage clamps against over/under-voltage
- ESD/transient protection appropriate for a sensor input

A reasonable starting point for the RC network is approximately:

- **1 kΩ series**
- **100 nF to GND**

but verify the resulting bandwidth and ADC settling behavior rather than copying values blindly.

The current gauge updates MAP at 62.5 Hz, so filtering should reduce high-frequency harness noise without noticeably slowing real boost response.

Do not use a default resistor divider that changes normal 0–5 V sensor scaling unless firmware changes are also made.

Protect the ADS1115 against plausible wiring faults such as a signal wire briefly contacting 12 V, while keeping leakage/error low enough for pressure measurements.

---

# 9. I²C level translation

The ESP32 side is 3.3 V and the ADS1115 side is approximately 5 V.

The I²C topology should be:

## 3.3 V / MCU side

Connected to:

- H2 pin 6 / GPIO17 / SDA
- H2 pin 7 / GPIO18 / SCL
- BMP280
- external RTC
- low-voltage side of translator

## 5 V side

Connected to:

- ADS1115 only
- high-voltage side of translator

Preserve the project's **100 kHz** bus speed.

The existing system has proven stable with approximately **4.7 kΩ pull-ups**. Design the effective pull-up resistance in that general range unless the selected translator datasheet requires a different network.

### Translator preference

Prefer a real I²C translator that behaves safely if either supply rail is absent.

A device such as **TCA9406** is attractive because it supports 3.3 V <-> 5 V I²C and provides high-impedance isolation if a supply is at 0 V. Verify current availability and the exact datasheet requirements before selecting it.

A PCA9306 or BSS138-style MOSFET translator is also acceptable, but then explicitly verify:

- pull-up network
- enable/power sequencing
- behavior when one side is unpowered
- no significant back-power path

Do not use a generic push-pull logic translator that is inappropriate for open-drain I²C.

---

# 10. BMP280 ambient sensor

Place a genuine firmware-compatible **BMP280** on the 3.3 V side.

Required electrical setup:

- 3.3 V supply
- I²C address **0x76**
- `SDO -> GND`
- configure CSB appropriately for I²C mode
- local decoupling

Mechanical placement is critical:

- place the pressure sensor near the PCB edge
- keep its pressure opening unobstructed
- keep it away from the buck converter, inductor, TVS, and other heat sources
- leave a silkscreen/keepout note around the vent
- do not place conformal coating, adhesive, foam, or enclosure plastic directly over the pressure port
- design the enclosure interface so the BMP280 sees cabin/ambient air

The BMP280 is the live atmospheric reference used for gauge-pressure calculation and MAP calibration, so thermal/pressure isolation matters.

---

# 11. RTC

The current firmware already supports a **DS3231-compatible RTC at address 0x68** on GPIO17/18.

Preserving that interface is strongly preferred because it avoids a firmware rewrite.

## Preferred implementation

Use:

- DS3231 or a verified register-compatible variant
- 3.3 V main supply if supported by the selected part
- appropriate local decoupling
- backup battery connection
- compact replaceable backup cell or suitable automotive-temperature backup source

If using a primary coin cell:

- **do not implement a charging circuit**
- make polarity extremely clear
- choose a holder/source appropriate for expected vehicle cabin temperature

If the selected DS3231 package is too large, you may propose a smaller I²C RTC, but then:

1. explain exactly why,
2. identify the new address/register model,
3. provide a firmware adaptation plan,
4. do not claim drop-in compatibility.

Note that the Waveshare board itself contains a PCF85063 RTC, but the existing boost-gauge external sensor implementation does not use it. Treat switching to that RTC as a firmware/power architecture change, not as a free PCB simplification.

---

# 12. Mechanical form factor

Create a reusable tscircuit form-factor component for the Waveshare backplane geometry.

## Required outline

- round PCB
- **46.00 mm diameter**
- no copper/components outside the outline

Use a polygonal approximation of the circle if that is the best-supported tscircuit mechanism, but make it visually and dimensionally accurate.

## H2 mating header

Place a 1x8, 2.54 mm mating connector exactly aligned to Waveshare H2.

Critical:

- verify pin 1 orientation from the schematic/dimension drawing
- account for the fact that a back-to-back daughterboard can mirror connector orientation
- render/inspect both board sides so pin mapping is not accidentally reversed

Do not guess the XY position.

Use the official mechanical drawing as the source of truth.

## Mounting holes

Reproduce the Waveshare board's mounting-hole pattern from the official dimension drawing.

Use the matching hole diameters/locations and provide room for practical spacers/standoffs.

The electrical header should not be the only thing resisting vehicle vibration.

## Stack-up and clearance

The daughterboard mounts behind the Waveshare PCB.

Therefore:

- keep the mating/display-facing side as low-profile as possible
- put tall parts, sensor connectors, input power connector, backup battery holder, inductor, and other bulky items on the **outward/back face**
- define keepouts for Waveshare-side components
- make sure the Waveshare USB-C connector can still be accessed for flashing
- preserve access to any buttons/connectors that are needed in the final installation
- confirm that the chosen header/socket height provides enough inter-board clearance

Do not assume two 46 mm discs can simply be placed flush together.

Create a side/3D sanity check of the stack if tscircuit's current tooling supports it.

---

# 13. Connector placement

Required connectors on the outward/back side:

- 2-pin vehicle power input:
  - 12V_IN
  - GND
- A0–A3 three-pin sensor connectors as space allows

Place them for practical harness routing, not merely for autorouter convenience.

Prefer connectors near the perimeter.

Keep the 12 V input region physically separated from the BMP280 and analog signal traces.

---

# 14. Grounding and PCB layout

Target a **2-layer PCB** unless a 4-layer stack is genuinely needed.

Suggested strategy:

- large continuous GND plane wherever possible
- short, wide 12 V and 5 V power paths
- wide copper for the display 5 V feed
- very short regulator hot loop
- keep switching node copper minimal
- keep buck inductor/switch node far from A0–A3 traces and BMP280
- route analog traces away from the switch node
- keep I²C routing short and clean
- place decoupling capacitors adjacent to every IC supply pin
- avoid routing noisy power underneath the BMP280 if possible

Do not split ground into isolated "analog" and "digital" islands unless there is a well-justified return-current plan. A coherent low-impedance ground plane is preferred.

Use trace widths and vias appropriate for the expected current, not generic signal widths on the power rails.

---

# 15. Test points

Provide clearly labeled test points for at least:

- 12V_IN
- protected vehicle input after reverse-polarity stage
- shared/display ~5V rail
- sensor 5V rail
- 3V3
- GND
- SDA_3V3
- SCL_3V3
- SDA_5V
- SCL_5V
- A0
- A1
- A2
- A3

If space permits, also expose:

- GPIO16
- UART TX/RX

These are useful for first-board bring-up and diagnosing the sensor bus without disassembling the whole gauge.

---

# 16. Component sourcing and assembly

This should be a real manufacturable board, not a conceptual schematic.

Use the tscircuit skill and current tscircuit/JLCPCB workflows.

Prefer:

- parts currently stocked by JLCPCB/LCSC
- common passives, preferably 0603 where space permits for easier rework
- manufacturer-supported footprints
- components with real datasheets
- parts suitable for the voltage/current/temperature environment

Use `tsci search --jlcpcb` and/or `tsci import --jlcpcb` extensively where appropriate.

For every nontrivial IC, record:

- manufacturer
- exact MPN
- package
- JLCPCB/LCSC part number if available
- key voltage/current/temp rating
- reason for selection
- at least one substitute where practical

Do not use hobby breakout modules.

The mating header, sensor connectors, backup battery holder, or vehicle connector may be marked DNP/hand-solder if that is more realistic than JLC assembly.

---

# 17. tscircuit workflow

Use the current **tscircuit skill** and follow current tscircuit syntax rather than inventing APIs.

Work in stages.

## Phase 1 — research and block diagram

Before writing the final board:

1. inspect repository firmware assumptions
2. inspect official Waveshare schematic and mechanical drawing
3. decide the exact 12 V protection/buck architecture
4. decide the USB/VBUS power-sharing strategy
5. decide the I²C translator
6. decide RTC package and backup source
7. decide connector family
8. write a short block diagram / design rationale

Do not proceed with unresolved pinout or mechanical ambiguity.

## Phase 2 — schematic/netlist

Create a readable complete schematic/netlist first.

Name rails clearly, e.g.:

- `CAR_12V_RAW`
- `CAR_12V_PROTECTED`
- `BUCK_5V_RAW`
- `VBUS_SHARED`
- `SENSOR_5V`
- `3V3`
- `I2C_SDA_3V3`
- `I2C_SCL_3V3`
- `I2C_SDA_5V`
- `I2C_SCL_5V`

Run the appropriate checks before placement.

## Phase 3 — mechanical form factor and placement

Create the 46 mm round form factor, H2 header, mounting holes, and keepouts first.

Then place functional blocks:

- automotive power region
- ADC / analog region
- level shifter
- BMP280
- RTC
- sensor connectors

Run:

`tsci check placement`

or the equivalent current command provided by the installed tscircuit skill.

Inspect top and bottom PCB renders and correct overlaps/clearance problems before routing.

## Phase 4 — routing

Route critical nets intentionally before relying on generic autorouting:

1. buck converter hot loop
2. high-current 5 V paths
3. ground return
4. analog sensor inputs
5. I²C bus
6. remaining low-current nets

Use copper pours/planes where appropriate.

Then route remaining nets.

## Phase 5 — build and verification

Run the current equivalent of:

`tsci build`

and all available placement/DRC checks.

Resolve:

- overlaps
- unrouted nets
- illegal clearances
- holes outside the outline
- connector courtyard conflicts
- incorrect layer assignments
- copper too close to the board edge

Inspect the final PCB render manually.

Do not consider "the tool built successfully" sufficient proof of correctness.

---

# 18. Mechanical validation requirement

Before declaring completion:

1. verify the generated board is 46.00 mm diameter
2. compare H2 and mounting-hole geometry against the official Waveshare dimension drawing
3. check that the mating header is not mirrored
4. check component height between the two PCBs
5. check USB-C cable access
6. check sensor/power connector access
7. confirm no tall component on the daughterboard collides with the Waveshare board

If possible, export a 1:1 SVG/PDF/image of the backplane mechanical geometry for overlay/printing.

If the current tscircuit exporter has limitations around circular outlines or cutouts, verify the **actual Gerber edge geometry**, not only the browser render.

---

# 19. Electrical validation checklist

Before completion, explicitly review each item:

## Power

- [ ] reverse battery protected
- [ ] input transient/TVS protection present
- [ ] buck input rating justified
- [ ] buck output current and thermal margin justified
- [ ] display VBUS power path defined
- [ ] USB backfeed scenario analyzed
- [ ] sensor rail short behavior analyzed
- [ ] 3.3 V is not overloaded

## I²C

- [ ] GPIO17 = SDA
- [ ] GPIO18 = SCL
- [ ] 100 kHz target
- [ ] ADS1115 = 0x48
- [ ] BMP280 = 0x76
- [ ] RTC = 0x68
- [ ] correct 3.3/5 V level translation
- [ ] powered-off rail behavior checked
- [ ] effective pull-ups appropriate

## Analog

- [ ] A0 is MAP input
- [ ] A1–A3 exposed if feasible
- [ ] 0–5 V sensor scaling preserved
- [ ] input overvoltage protection present
- [ ] RC filtering does not excessively slow MAP response
- [ ] sensor 5 V and ADS supply relationship understood
- [ ] firmware MAP supply value documented

## Mechanical

- [ ] 46.00 mm diameter
- [ ] H2 exact position/orientation
- [ ] matching mounting holes
- [ ] appropriate standoff/header height
- [ ] USB-C remains accessible
- [ ] outward-facing connectors are usable
- [ ] BMP280 vent unobstructed

---

# 20. Bring-up/test procedure to include with the design

Write a short first-board bring-up procedure.

At minimum:

1. Inspect unpowered board for shorts.
2. Power from a current-limited bench supply at 12 V with the Waveshare board disconnected.
3. Verify protected input rail.
4. Verify buck/shared 5 V rail.
5. Verify sensor 5 V rail.
6. Verify no abnormal current or regulator heating.
7. Connect Waveshare board.
8. Verify H2 3.3 V.
9. Run the project's sensor scan endpoint or firmware diagnostic.
10. Expect stable I²C addresses:
    - `0x48` ADS1115
    - `0x68` DS3231
    - `0x76` BMP280
11. Apply known voltages to A0–A3 and verify ADC readings.
12. Connect GM MAP sensor and verify atmosphere reading/calibration.
13. Confirm BMP280 ambient pressure is plausible.
14. Set RTC, remove main power, and verify retention.
15. With vehicle 12 V disconnected, connect USB-C and verify USB does not reverse-power the vehicle input/buck path.
16. Verify USB flashing remains possible with the daughterboard installed.
17. Check A0 noise with the buck converter running.

---

# 21. Required deliverables

Produce a complete tscircuit project, not just screenshots.

Preferred repository location:

`hardware/boost-gauge-backplane/`

Include:

1. tscircuit source files
2. reusable Waveshare 46 mm form-factor component
3. complete schematic
4. PCB layout
5. fabrication-ready Gerbers
6. drill files
7. BOM
8. pick-and-place / centroid file if supported
9. JLCPCB/LCSC sourcing table
10. PCB top render
11. PCB bottom render
12. schematic render
13. 3D render if supported
14. `README.md` explaining:
    - architecture
    - H2 pinout
    - power path
    - USB power caveat/solution
    - sensor connector pinout
    - I²C addresses
    - RTC battery
    - assembly notes
    - bring-up steps
15. `DESIGN_REVIEW.md` containing:
    - assumptions
    - calculations
    - component-selection rationale
    - power/thermal review
    - automotive protection review
    - unresolved risks
16. a concise list of any firmware changes required

If no firmware change is required, explicitly state that the PCB preserves:

- SDA GPIO17
- SCL GPIO18
- ADS1115 0x48
- BMP280 0x76
- DS3231 0x68
- A0 as MAP input

---

# 22. Acceptance criteria

The design is not complete until all of the following are true:

- It physically matches the Waveshare 46 mm PCB form factor.
- It mates with H2 without reversing pin order.
- It can power the Waveshare board from vehicle 12 V.
- It has credible automotive input protection.
- It does not blindly create an unsafe USB-VBUS backfeed path.
- It powers the ADS1115 and external sensors from an appropriate ~5 V rail.
- It translates GPIO17/18 I²C safely between 3.3 V and the ADS1115 5 V domain.
- It includes a firmware-compatible BMP280.
- It includes a battery-backed RTC or clearly justified compatible alternative.
- It exposes A0 and preferably A1–A3 as 3-pin 5V/GND/signal connectors.
- It includes reasonable analog input protection and filtering.
- The BMP280 can breathe ambient air.
- The PCB can actually be fabricated and assembled using the generated files.
- The BOM contains real orderable parts.
- All tscircuit checks/builds complete without unresolved errors.
- The final design has been visually inspected for mechanical and electrical sanity.

---
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

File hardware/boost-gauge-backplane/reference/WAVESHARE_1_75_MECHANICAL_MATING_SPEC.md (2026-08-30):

# Waveshare ESP32-S3-Touch-AMOLED-1.75
# Mechanical Mating Specification for a 46 mm Rear Daughterboard

**Target board:** Waveshare ESP32-S3-Touch-AMOLED-1.75, standard round PCB  
**Purpose:** Provide fixed mechanical datums for a custom PCB that mounts directly behind the Waveshare PCB and mates to its 8-pin H2 expansion header.

This document is intended to supplement the main `CUSTOM_PCB_TSCIRCUIT_AGENT_SPEC.md` so that the PCB-design agent does **not** need to research or estimate the Waveshare board geometry.

---
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

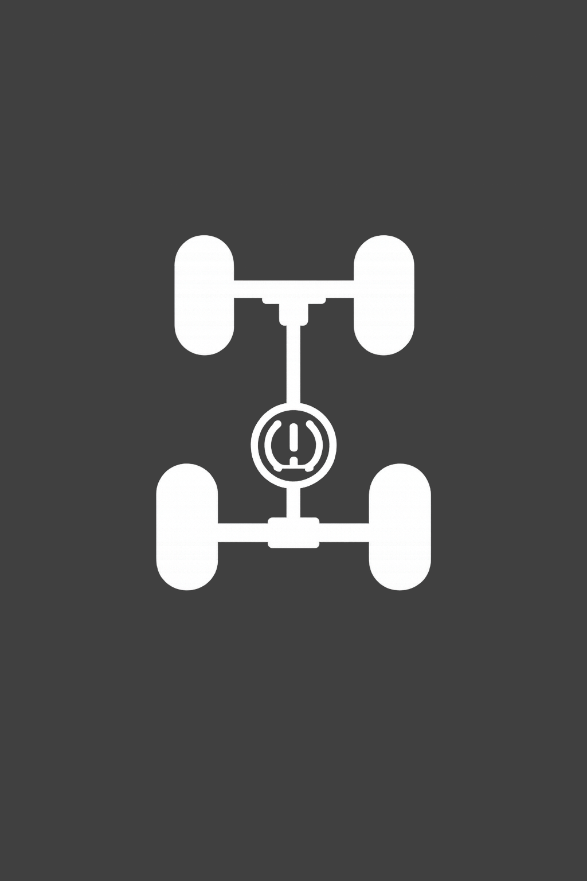
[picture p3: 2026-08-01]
tpmspowertrain.png

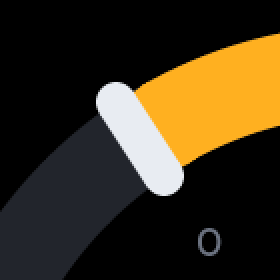
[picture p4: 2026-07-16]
preview/sim/zero_join_boost.png

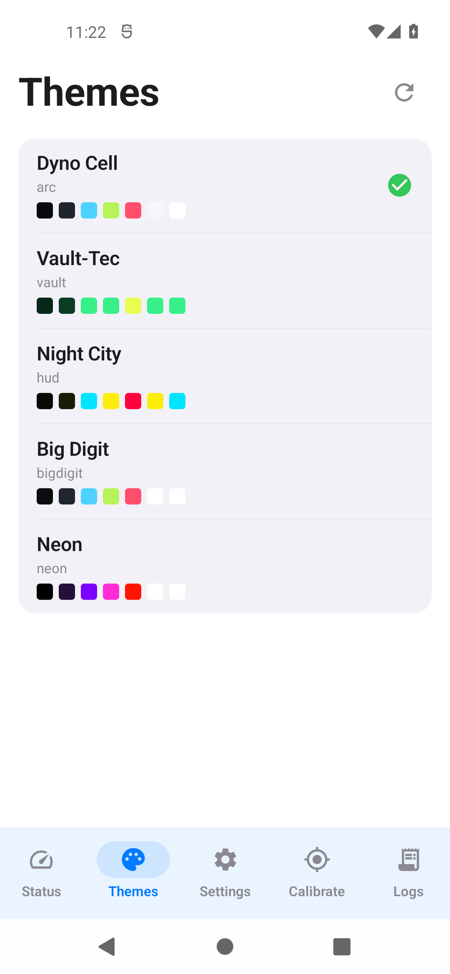
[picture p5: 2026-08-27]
preview/android_screen_themes.png

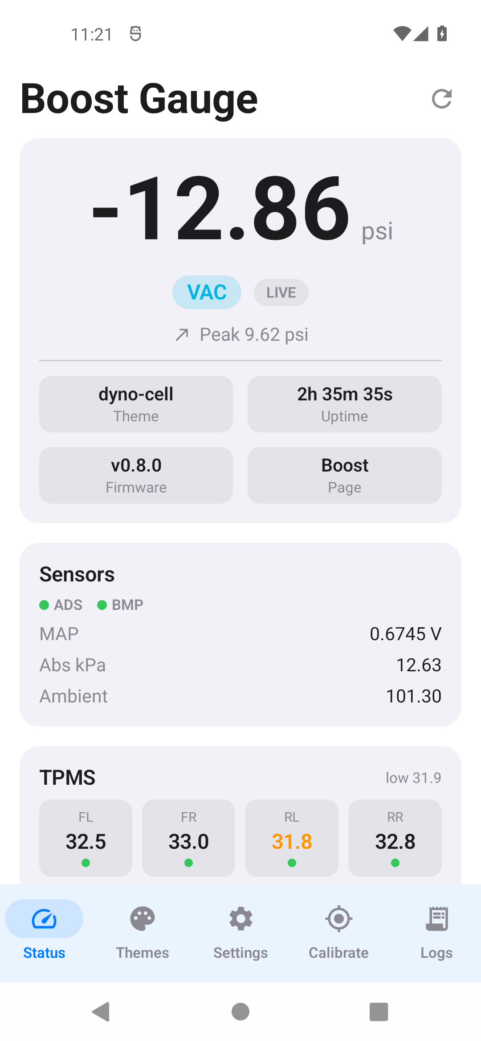
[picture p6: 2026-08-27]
preview/android_screen_styled.png

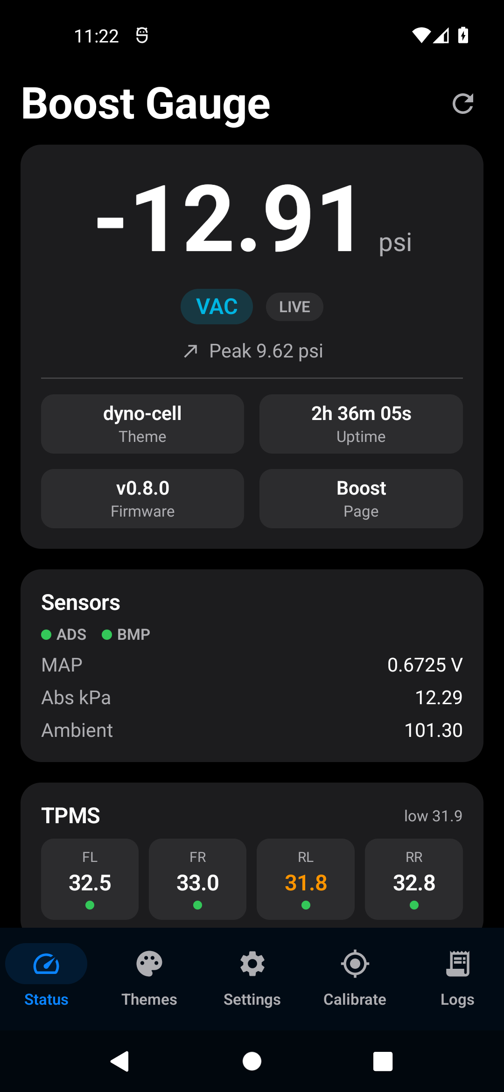
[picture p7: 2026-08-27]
preview/android_screen_styled_dark.png

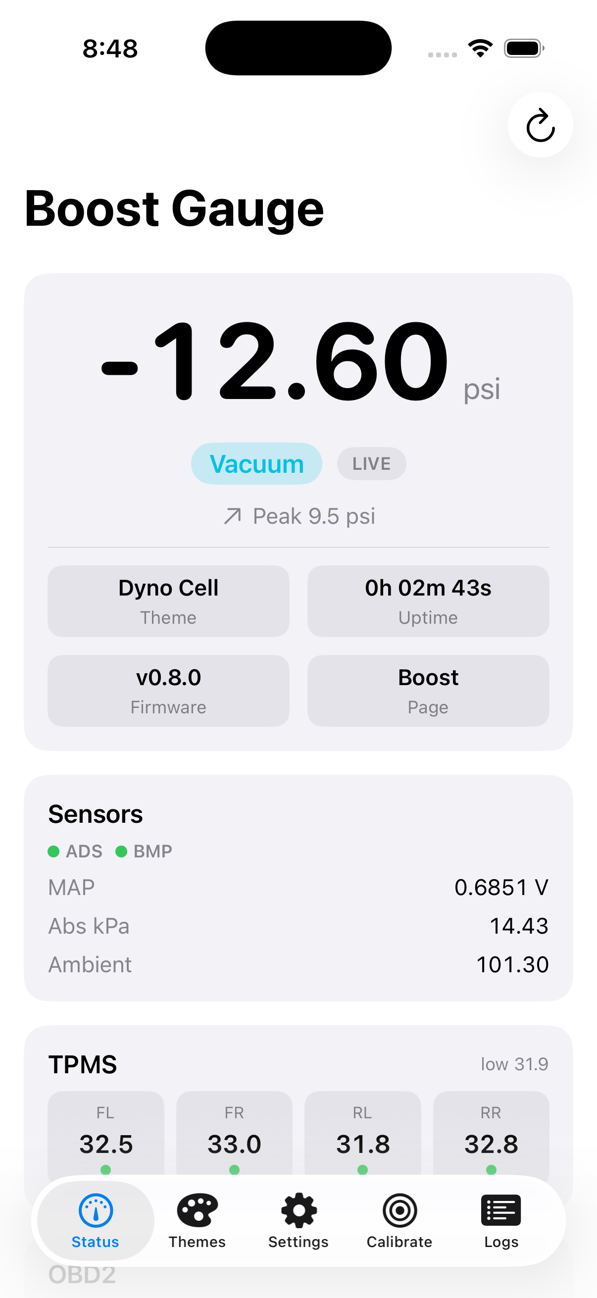
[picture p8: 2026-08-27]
preview/ios_screen.png

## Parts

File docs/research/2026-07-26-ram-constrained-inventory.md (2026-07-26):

# What was blocked by internal RAM — a complete inventory

Date: 2026-07-26
Scope: desk research only. No hardware was touched, nothing was built or
flashed, and no configuration was changed while producing this document.
Trigger: [`docs/research/2026-07-26-ble-wifi-coexistence.md`](2026-07-26-ble-wifi-coexistence.md)
measured `CONFIG_LV_ATTRIBUTE_FAST_MEM_USE_IRAM=y` at **82,812 bytes of DIRAM**
against only **13,611 bytes** of internal free at peak on `main`.

The question this answers: *"What was marked not-an-option because of RAM? Just
the GIF?"*

**Short answer: no.** The GIF decoder is the most conspicuous case because it
boot-looped the board, but at least four other decisions were shaped by internal
RAM, and several more that *look* like RAM decisions are not — they are DMA
capability, PSRAM capacity, CPU rasterisation cost, or correctness. Keeping those
apart is the whole point of the exercise; this project has already lost time to
conflating them twice.

---

## 0. Definitions, because several past mistakes came from mixing these up

| Term | What it is on this board | Who competes for it |
|---|---|---|
| **Internal SRAM / DIRAM** | 341,760 B of on-chip RAM (`dram0_0_seg` in `build/boost_gauge.map`), addressable as either data or instructions. Every byte given to IRAM is a byte taken from DRAM. | everything below |
| **DRAM (internal data RAM)** | The data-side view of DIRAM. `.bss`, `.data`, and the internal heap. | Wi-Fi driver, LWIP, NimBLE, FreeRTOS stacks that touch flash, LVGL draw buffers, static arrays |
| **IRAM** | The instruction-side view of DIRAM. Code that must not take a flash-cache miss (ISRs), plus anything deliberately parked there for speed. | `LV_ATTRIBUTE_FAST_MEM_USE_IRAM`, `ESP_WIFI_IRAM_OPT`, `ESP_WIFI_RX_IRAM_OPT`, `BT_CTRL_RUN_IN_FLASH_ONLY=n` |
| **DMA-capable** | A *property* of internal DRAM, not a separate pool. ESP32-S3 SPI GDMA cannot stream from PSRAM at all. | LVGL draw strips, Wi-Fi static RX buffers |
| **PSRAM (external, SPIRAM)** | 8 MB octal. ~6.4 MB free at runtime (spike, `PSRAM free 6,390,652`). Cannot feed SPI GDMA. Higher latency; pointer-chasing inner loops suffer. | cached face canvases, GIF framebuffer, task stacks that never touch flash, `malloc` by default (`CONFIG_SPIRAM_MALLOC_ALWAYSINTERNAL=0`) |

Three consequences that recur throughout this document:

1. **Freeing IRAM returns DRAM.** Turning off an IRAM option does not "speed
   nothing up and free nothing" — it converts 82.8 kB of instruction space back
   into data space. The spike measured DMA-capable free going **5,823 → 106,235 B**
   in the control build, so the recovered memory really is usable by the display
   and the radio, not just by generic allocations.
2. **Total free is not the binding constraint; the largest contiguous block
   often is.** `main` at peak: 13,611 free but only **7,680 B largest block**.
   NimBLE needs ~22.5 kB contiguous. Wi-Fi does not merely consume internal
   DRAM, it fragments it (59,392 → 7,680 across Wi-Fi + httpd bring-up).
3. **PSRAM being nearly empty is irrelevant to any of this.** 6.4 MB free PSRAM
   never helped the GIF decoder, the radio, or a draw strip.

### How much is actually being unblocked

The "~100 KB" figure needs decomposing, because the spike's 114,023 B control
build had **two** changes, not one:

| Change | DIRAM recovered | Source |
|---|---:|---|
| `CONFIG_LV_ATTRIBUTE_FAST_MEM_USE_IRAM=n` | **82,812** | spike, `idf.py size` 78,953 → 161,765 |
| `CONFIG_ESP_WIFI_IRAM_OPT=n` + `CONFIG_ESP_WIFI_RX_IRAM_OPT=n` | **17,700** | spike, `idf.py size` 53,945 → 71,645 |

So turning off **only** the LVGL option leaves an *estimated* **~96.4 kB** free
internal at peak (13,611 + 82,812 — arithmetic, **not measured in isolation**;
the spike never ran that configuration on its own). The measured 114,023 B
figure requires giving up the Wi-Fi IRAM optimisations as well, which on `main`
today are both still `=y` (`sdkconfig:1393`, `sdkconfig:1395`).

Throughout the table below, "would ~100 KB unblock it?" means the ~82.8 kB
LVGL-only lever unless stated otherwise.

---

## 1. The inventory

Every row cites its source. Where the historical record states no number, the
cell says **not recorded** rather than a guess.

### 1a. Genuinely constrained by internal RAM

| # | What was wanted | Internal RAM it needed | What happened | Source | Would ~100 KB unblock it? |
|---|---|---:|---|---|---|
| 1 | **GIF decoder's `GIFIMAGE` (LZW tables + palettes + file buffer) placed in internal RAM** for decode speed — PSRAM latency dominates a dependent pointer chase | **24,580 B** measured as the internal-free delta | **Reverted.** Boot-looped: `Guru Meditation LoadProhibited` through `wifi_softap_start` / `ieee80211_hostap_attach`. GIF loads at ~3 s, before SoftAP attach; taking 24.5 kB left ~49 kB internal and the Wi-Fi driver faulted on a failed alloc. Crash precedes the HTTP server, so OTA could not recover it — fix went over serial. Pointer indirection kept so a future attempt can place only the hottest few kB | `AGENTS.md:121`; commit `b002e45` body; `main/gif/boost_gif.c:272-279`; `main/gif/boost_gif.c:100-107` | **Yes**, with room to spare — 24.5 kB against ~96 kB. But see §4: the *benefit* was never measured, only the crash |
| 2 | **NimBLE + Wi-Fi coexistence (BLE telemetry to an Android app)** | **29,668 B** at `nimble_port_init()` + advertising start; **36,320 B** total runtime at peak; needs a **~22.5 kB contiguous** block; **6,512 B** static | **Was blocked on `main`, measured unblocked in the spike.** Every intermediate config failed traceably to internal DRAM. With the LVGL IRAM option off: single clean boot, 77,703 B free internal, 63,488 B largest block, cadence unaffected | `docs/research/2026-07-26-ble-wifi-coexistence.md` §"Measured numbers", §"What it took to make it fit"; `docs/plans/2026-07-26-bluetooth-android-app.md:20-57` | **Yes — already demonstrated on hardware.** The single strongest item on this list |
| 3 | **BLE controller code in IRAM** (`CONFIG_BT_CTRL_RUN_IN_FLASH_ONLY=n`), so BLE interrupts don't take a flash-cache miss | "**~20 kB** that this configuration does not have spare" — the spike's own estimate, not a measurement | **Deferred.** The working spike build needed `RUN_IN_FLASH_ONLY=y` to fit. Its Kconfig help warns of a performance cost; it is one of two unseparated candidate causes for HTTP p50 going 25 ms → 88–181 ms | `docs/research/2026-07-26-ble-wifi-coexistence.md:143-146`, §"What I could NOT test" | **Probably** — but note this consumes IRAM, so it partly re-spends what the LVGL change frees. Needs measuring, not assuming |
| 4 | **Keeping `CONFIG_ESP_WIFI_IRAM_OPT=y` / `CONFIG_ESP_WIFI_RX_IRAM_OPT=y` while also running BLE** | **17,700 B** of DIRAM (spike: 53,945 → 71,645) | **Constrained.** The spike had to switch both off to recover HTTP responsiveness under NimBLE. On `main` today both are still `=y` | `docs/research/2026-07-26-ble-wifi-coexistence.md:161`; `sdkconfig:1393`, `sdkconfig:1395` | **Yes** — this is the "don't have to pay it" case. ~82.8 kB is nearly 5x this cost |
| 5 | **Larger LVGL draw strips: 40 lines** (37,280 B/buffer, 74,560 B double-buffered — **+37,280 B internal DMA** over the 20-line production setting) | 74,560 B DMA-capable internal, vs 37,280 B today | **Rejected.** "Wi-Fi route disappeared after flash/load" — the textbook internal-DRAM-exhaustion signature | `README.md:124`; `AGENTS.md:63` | **RAM-wise yes.** But see §3: there is no measured benefit to chase, so unblocking it is not a reason to do it |
| 6 | **Larger LVGL draw strips: 28 lines** (26,096 B/buffer, 52,192 B double — **+14,912 B** over production) | 52,192 B DMA-capable internal | **Rejected.** "HTTP became unresponsive under load." Cause not diagnosed in the record; consistent with httpd/LWIP losing internal allocations, but **not recorded as a RAM measurement** | `README.md:123` | **Probably**, if the mechanism was internal-DRAM pressure. The record does not say it was |
| 7 | **Untrimmed Wi-Fi buffer pools.** Production runs `STATIC_RX_BUFFER_NUM=6`, `STATIC_TX_BUFFER_NUM=6`, `CACHE_TX_BUFFER_NUM=8`, `RX_BA_WIN=6`, `MGMT_SBUF_NUM=8`, all below IDF defaults | **not recorded** — no byte figure was ever written down for this trim | **Constrained**, in the same commit that moved Wi-Fi/LWIP out of the internal DMA heap. The stated rationale is workload ("a four-client control page does not need throughput-oriented Wi-Fi pools"), not scarcity, but static RX buffers must be DMA-capable internal, so the effect is real | `sdkconfig.defaults:29-34`; commit `d2316eb` diff | **Yes, if anyone wants it.** No evidence anyone does — no throughput complaint is recorded |
| 8 | **`CONFIG_SPIRAM_MALLOC_RESERVE_INTERNAL=65536`** — a standing 64 kB internal reservation so display DMA and Wi-Fi can coexist | 65,536 B held back from the general allocator, permanently | **Constraint by design**, not a deferral. Explicitly called out as load-bearing in both the README and the AGENTS invariants | `sdkconfig.defaults:21-24`; `README.md:78-80`; `AGENTS.md:63` | **Do not touch it.** ~100 KB makes it cheaper to keep, not safe to remove |
| 9 | **Boot-time media CRC validation with a 4,096 B scratch buffer on the stack** | 4,096 B on the 3,584 B ESP-IDF main-task stack | **Reworked, not deferred.** Repeatable `main` task stack overflow before networking. Fixed by CRC-ing through a temporary read-only `esp_partition_mmap` instead | `AGENTS.md:108` | **No, and it doesn't matter** — this was stack sizing, not heap scarcity, and the mmap fix is strictly better than a bigger stack |
| 10 | **NimBLE host mempools in internal RAM** (spike) | **not recorded** separately | **Constrained** — moved to PSRAM as one of the cumulative steps needed to fit | `docs/research/2026-07-26-ble-wifi-coexistence.md:160` | **Possibly**, but no reason to: host mempools are not latency-critical the way the controller is |
| 11 | **`CONFIG_BT_CTRL_BLE_MASTER=n`** — set specifically *to save memory* | **not recorded** | **Rejected on correctness, not size.** Its help text ("Enable BLE connection feature") does not describe the central role; with it off the controller reports `CONNECT:0` — an unconnectable peripheral. Must stay `y` | `docs/research/2026-07-26-ble-wifi-coexistence.md:175-179`; `AGENTS.md:148` | **N/A** — a memory-saving attempt that was wrong for a non-memory reason |
| 12 | **`CONFIG_BT_LE_MAX_CONNECTIONS` / `BT_LE_50_FEATURE_SUPPORT`** memory tuning | zero — the symbols do not exist on ESP32-S3 | **No-op.** Accepted silently into `sdkconfig.defaults` as unknown symbols. Same failure class as the phantom 60 MHz QSPI trial | `AGENTS.md:148`; `docs/research/2026-07-26-ble-wifi-coexistence.md:180-183` | **N/A** |

### 1b. Looks like a RAM decision, isn't

| # | Item | Why it is *not* an internal-RAM constraint | Source |
|---|---|---|---|
| 13 | **LVGL draw buffers in PSRAM** (the stock BSP's `use_psram = true`) | A **DMA capability** limit, not a size limit. ESP32-S3 SPI GDMA cannot stream from PSRAM; the bounce-buffer path returns `ESP_ERR_NO_MEM` and the panel never completes a clean full-frame update (half-white/half-green). More free internal RAM does not make PSRAM DMA-capable | `README.md:51-56`, `README.md:71-76`; `AGENTS.md:100`; `main/boost_display.c:19-24`, `:529`; `main/boost_display.h:15-18` |
| 14 | **24-line draw strips** (+7,456 B internal over production) | **Reverted for a subjective reason** — "the live mirror was reported subjectively laggier" — and it produced **no measured physical-FPS gain**. Not a RAM rejection at any point | `README.md:122` |
| 15 | **`heap_caps_malloc_extmem_enable(64 KB)` around GIF widget creation** | An **allocator-targeting** failure, not a capacity failure. Internal free moved by 112 B: the threshold only affects `malloc`, and the ledger records LVGL as allocating from its own builtin pool. Calls removed as no-ops. **⚠ See §4.1 — the recorded root cause is contradicted by the current tree** | `AGENTS.md:120`; commit `b002e45` body; `main/boost_gauge.c:646-648` |
| 16 | **TE / tearing fix by region double-buffering** | Recorded as "a larger change", and the RAM it would need is *far* beyond this lever. The needle's dirty band is 205 of 466 rows → 205 × 466 × 2 = **191,060 B** of DMA-capable internal for that region alone (*arithmetic from the recorded row count, not a measurement*); a full frame is 434 KB. ~100 KB does not reach it. The actual blocker is architectural: TE-at-vblank only fixes the phase of the *first* strip on a CPU-rasterised partial pipeline | `AGENTS.md:123`, `AGENTS.md:129`, `AGENTS.md:125` |
| 17 | **24 cached full-screen Big Digit grounds** | Wants **10 MB** — that is **PSRAM**, and it exceeds the ~6.4 MB free. Also pointless: a flat fill is already LVGL's cheapest primitive, so there is nothing to pre-compute | `README.md:509-511`; `AGENTS.md:114` |
| 18 | **Cached static face art** (Vault, Night City) | **Enabled by PSRAM, never internal-limited.** 434 KB PSRAM `lv_canvas` per face, painted once at scene build. Biggest measured win in the project (Vault median 37 → 61 FPS, min 4 → 54, while *adding* vignette and scanlines) | `README.md:496-504`; `AGENTS.md:115`; `main/boost_gauge.c:31`, `:1490`, `:1922` |
| 19 | **AnimatedGIF turbo LZW path** (`pTurboBuffer = NULL`) | Disabled for **correctness** — turbo failed delta/disposal composition. A turbo buffer would want *more* memory (`LZW_BUF_SIZE_TURBO`), but that is not why it is off | `AGENTS.md:50-58`; `main/gif/boost_gif_dec.c:137-141`; `main/gif/boost_gif_dec.h:59`, `:105` |
| 20 | **8-bit palette-index plane removal** in the vendored decoder | Freed **212 KiB of PSRAM** and cut 434 KB of per-frame PSRAM traffic. Nothing to do with internal DRAM | commit `7633c41` body; `AGENTS.md:50-58` |
| 21 | **Browser GIF preview disabled; device-pixel-ratio capped at 2** | **Browser-side** memory and render cost. No relationship to firmware DRAM | `AGENTS.md:38`, `AGENTS.md:103` |
| 22 | **Needle judder / frames-over-budget / per-face FPS** | **CPU rasterisation cost.** Falsified twice already — not the 0.35° gate, not `LV_DRAW_THREAD_PRIO`. The ESP32-S3 has no 2D accelerator; the panel link is ~6% utilised | `AGENTS.md:122`, `AGENTS.md:126`, `AGENTS.md:115` |
| 23 | **QSPI clock as a general lever** | **Link-bound operations only.** 40 → 80 MHz moves the Big Digit full-screen recolour −17% and the partial-update faces 0–3% | `README.md:530-534`; `AGENTS.md:133` |
| 24 | **Debug snapshot buffer** (`GET /api/v1/debug/snapshot`) | 466×466×2 = 434 KB explicitly allocated `MALLOC_CAP_SPIRAM`. Never contended for internal | `main/boost_web.c:932`; `README.md:631-636` |
| 25 | **Raw dual-slot media store replacing SPIFFS** | A **flash** architecture problem (GC, staging, atomicity), not RAM | `AGENTS.md:101`; `README.md:323-336` |

---

## 2. Genuinely unblocked — ranked by value to effort

**1. BLE + the Android app (plan phases 0–2).** *High value, effort already
largely spent.* This is the only item on the list where the unblocked state has
been **observed on hardware**: single clean boot, BLE advertising alongside
Wi-Fi STA + SoftAP + httpd + 3 WebSocket clients + the display, 77,703 B free
internal, 63,488 B largest block, cadence min 57 / median 60. Phase 0 was
written as a go/no-go gate and it passed. Caveats that are *not* about RAM and
must not be glossed: no BLE central ever saw the advertisement, throughput is
entirely unmeasured, cadence under an active connection is untested, and the
HTTP p50 penalty (25 → 88–181 ms) is real and unattributed. Also gated on the
non-RAM safety item in the plan — one full USB flash to actually activate the
OTA rollback net, which has never been written to this board.
Source: `docs/research/2026-07-26-ble-wifi-coexistence.md`;
`docs/plans/2026-07-26-bluetooth-android-app.md:73-89`.

**2. Not paying for the Wi-Fi IRAM optimisations.** *Moderate value, near-zero
effort.* The spike had to set `ESP_WIFI_IRAM_OPT=n` and `ESP_WIFI_RX_IRAM_OPT=n`
to recover HTTP responsiveness with NimBLE present — a 17,700 B DIRAM recovery
bought by slowing the Wi-Fi path. With 82,812 B available from the LVGL option
alone, that trade is no longer forced: `main` can keep both `=y` and still fit
BLE. This is purely "stop giving something up", so it costs nothing to take.
Source: `docs/research/2026-07-26-ble-wifi-coexistence.md:161`; `sdkconfig:1393,1395`.

**3. BLE controller in IRAM (`BT_CTRL_RUN_IN_FLASH_ONLY=n`).** *Moderate value,
moderate effort, genuinely diagnostic.* It is one of exactly two candidate
causes for the 3.5–7× HTTP latency regression under BLE, and the spike could
not separate them because the IRAM build did not fit. It does now (spike
estimate: ~20 kB). Worth doing **as an experiment first** — if latency recovers,
the answer is "flash-cache misses", and if it does not, the answer is
"coexistence arbitration" and the product decision changes. Note this spends
IRAM back, so it must be measured against the same peak-load heap probe.
Source: `docs/research/2026-07-26-ble-wifi-coexistence.md:143-146`, §"What I could NOT test".

**4. GIF decoder state (or just its hottest arrays) in internal RAM.** *Low
value, low effort, unmeasured upside.* 24,580 B against ~96 kB is comfortable,
and the `GIFIMAGE` pointer indirection was deliberately preserved for exactly
this. If a partial placement is preferred, the two large hot arrays are
`usGIFTable` (4,096 × `uint16` = **8,192 B**) and `ucGIFPixels`
(2 × 4,096 = **8,192 B**), plus `ucFileBuf` (**4,096 B**) — *sizes computed from
the header constants, not measured*. The reason this ranks fourth despite being
easy: **nobody has ever measured what it buys.** The attempt boot-looped before
producing an FPS number, and the surrounding GIF optimisation work delivered
+3% (14.55 → 15 FPS) against a predicted +17%. GIF playback is also an exclusive
path that the cadence guard explicitly does not defend. Do not repeat the
mistake of taking internal RAM for an unpriced speed benefit — that is the exact
pattern this whole document exists to document.
Source: `main/gif/boost_gif.c:272-279`; `main/gif/boost_gif_dec.h:222-231`;
`AGENTS.md:121`; commit `b002e45` body.

**5. Larger draw strips (28 or 40 lines).** *Low value, low effort, evidence
says don't.* RAM-wise these become affordable (+14,912 B and +37,280 B). But the
24-line test — the only one that ran cleanly enough to measure — showed **no
physical-FPS gain**, and the README is explicit that perceived mirror lag is a
network/canvas problem rather than a strip-throughput one. `AGENTS.md:64` forbids
enlarging strips "for an unmeasured speed claim". Unblocking is not the same as
justifying.
Source: `README.md:114-132`; `AGENTS.md:63-64`.

**6. Restoring Wi-Fi buffer pools to IDF defaults.** *Speculative value, low
effort.* Available if throughput ever becomes a complaint. Nothing in the record
says it is one. Leave alone until something asks for it.
Source: `sdkconfig.defaults:29-34`.

**7. General headroom.** Larger httpd stacks, more open sockets, wider JSON
buffers, additional internal-DRAM tasks. Nothing specific is blocked today, but
the current margin — 13,611 B free with a 7,680 B largest block — is why any of
those would have been risky. Worth knowing the constraint is lifted before the
next feature runs into it.

### The price of the lever, which is not yet paid

Every item above is contingent on turning off `CONFIG_LV_ATTRIBUTE_FAST_MEM_USE_IRAM`,
and **that has been validated on exactly one face.** The spike measured
`dyno-cell` (arc) in demo mode: min 57 / median 60 against a min 58 / median 60
baseline — unchanged. The three richer faces (`vault`, `night-city`, `bigdigit`)
are more rasterisation-bound and were **not** measured, and the ledger requires
any style-affecting change to be re-checked **per face** on `worstRenderUs` and
`pixelsPerSecond`, never on `renderFps`. The option's *benefit* has never been
measured on any face; only its cost is known.
Source: `AGENTS.md:147`, `AGENTS.md:111`, `AGENTS.md:116`;
`docs/research/2026-07-26-ble-wifi-coexistence.md:321-325`.

---

## 3. Still blocked, or never RAM-limited

| Item | Status after ~100 KB | Why |
|---|---|---|
| LVGL draw buffers in PSRAM | **Still impossible** | ESP32-S3 SPI GDMA cannot stream from PSRAM. A capability, not a quantity. `README.md:51-56` |
| TE region double-buffering (the real tearing fix) | **Still blocked** | Needs the whole dirty region DMA-capable and internal: ~191 kB for the needle band by arithmetic, 434 KB for a frame. ~100 KB is not close. `AGENTS.md:129` |
| 24 cached Big Digit grounds | **Still blocked, and still pointless** | 10 MB of PSRAM against ~6.4 MB free, to cache a flat fill. `README.md:509-511` |
| Turbo LZW decode | **Unaffected** | Off for delta/disposal correctness. `AGENTS.md:50-58` |
| 24-line strips | **Unaffected** | Reverted for subjective mirror lag with no FPS gain. `README.md:122` |
| `heap_caps_malloc_extmem_enable` | **Unaffected** | Wrong allocator targeted; a capacity change does not fix aim. `AGENTS.md:120` |
| Boot CRC scratch buffer | **Unaffected** | Stack sizing; already fixed better via mmap. `AGENTS.md:108` |
| Needle judder / per-face frame drops | **Unaffected** | CPU rasterisation cost. Falsified twice as a scheduling or gating problem. `AGENTS.md:122`, `:126` |
| QSPI clock for partial-update faces | **Unaffected** | Only full-frame pushes are link-bound. `AGENTS.md:133` |
| Browser GIF preview, DPR cap | **Unaffected** | Browser-side. `AGENTS.md:38` |
| SPIFFS → raw media store | **Unaffected** | Flash architecture. `AGENTS.md:101` |
| `SPIRAM_MALLOC_RESERVE_INTERNAL=65536` | **Keep** | Load-bearing invariant so display DMA and Wi-Fi coexist. `README.md:78-80` |

---

## 4. Explicit uncertainty

Everything in this section is a gap in the record, not a conclusion.

### 4.1 The "wrong allocator" root cause is contradicted by the current tree

`AGENTS.md:120` records the mechanism as: `CONFIG_LV_USE_CLIB_MALLOC=y` is set,
but `lv_conf_internal.h` reads `CONFIG_LV_USE_STDLIB_MALLOC`, which is never
defined, so LVGL falls back to `LV_STDLIB_BUILTIN` and allocates from its own
pool, never `malloc` — therefore `heap_caps_malloc_extmem_enable` could not
reach it.

**In the tree as it stands today, that chain does not hold:**

- `managed_components/lvgl__lvgl/src/lv_conf_kconfig.h:44-45` explicitly bridges
  the symbol: `#elif defined(CONFIG_LV_USE_CLIB_MALLOC)` → `#define CONFIG_LV_USE_STDLIB_MALLOC LV_STDLIB_CLIB`.
- `lv_conf_internal.h:38` includes `lv_conf_kconfig.h` **before** the
  `#ifndef LV_USE_STDLIB_MALLOC` fallback at lines 106-112, so the fallback is
  not taken.
- The link map is decisive: `build/boost_gauge.map:114608` resolves
  `lv_malloc_core` to `liblvgl__lvgl.a(lv_mem_core_clib.c.obj)`, and
  `lv_mem_core_builtin.c.obj` **does not appear in the map at all**. LVGL in
  this build calls `malloc()`.
- `CONFIG_SPIRAM_USE_MALLOC=y` (`sdkconfig:1218`), so
  `heap_caps_malloc_extmem_enable()` is functional in principle.

**What I am *not* claiming.** The empirical result stands unchallenged: internal
free moved by 112 B, so the call did nothing. I cannot say why. Two candidate
explanations, and the record cannot distinguish them:

1. The LVGL version present when the experiment ran (commit `b002e45`, ~2026-07-22)
   lacked the Kconfig bridge, and the component has since been refreshed.
   **This is unverifiable from the repository**: `dependencies.lock`,
   `sdkconfig`, and `managed_components/` are all in `.gitignore` (`.gitignore:1-8`),
   so `git log -- dependencies.lock` returns nothing and there is no record of
   which LVGL version was in the tree at any past commit. The tree today pins
   **lvgl/lvgl 9.4.0**.
2. The stated mechanism was wrong at the time too, and the 112 B result has some
   other cause that was never chased.

**Consequence for this inventory:** row 15 stays classified as "not a capacity
constraint" either way — nothing about 100 KB of extra internal RAM changes an
allocator-aim problem. But the *lesson* recorded in `AGENTS.md:120` ("a Kconfig
symbol existing is not evidence it is the one being read") may be resting on an
incorrect diagnosis, and anyone revisiting GIF decoder placement should verify
empirically rather than trusting either the ledger row or this paragraph. The
ledger's own guard applies to itself: confirm placement with
`esp_ptr_external_ram()` plus free-heap deltas.

**The build tree caveat:** `build/boost_gauge.map` (timestamped 2026-07-26 13:50)
was produced by another agent's in-progress work on branch
`spike/lvgl-iram-benefit`, whose `sdkconfig` I did not read as authoritative for
`main`. The specific facts I take from it — which stdlib malloc core the linker
resolved, and the size of a static array in `libmain.a` — are not affected by
the IRAM option under test, but they are one build's evidence, not `main`'s.

### 4.2 Numbers the record does not contain

| Question | Status |
|---|---|
| What does `LV_ATTRIBUTE_FAST_MEM_USE_IRAM=y` actually *buy*, on any face? | **Never measured.** Only its cost (82,812 B) is known. It was introduced in the initial commit `6812b20` with no rationale and no measurement, and went unpriced for the project's whole history |
| Cadence with the option off, on `vault` / `night-city` / `bigdigit` | **Not measured.** Only `dyno-cell` |
| Free internal at peak with *only* the LVGL option off | **Not measured.** ~96,423 B is my arithmetic (13,611 + 82,812). The measured 114,023 B control also had both Wi-Fi IRAM opts off |
| What the 24.5 kB internal GIF placement would have bought in FPS | **Never measured** — it boot-looped first |
| Which of `usGIFTable` / `ucGIFPixels` / `ucFileBuf` are the "hottest few kB" | **Not measured.** My byte figures are arithmetic from `main/gif/boost_gif_dec.h:222-231`; no profiling exists |
| Free-RAM figures at the 28-line and 40-line strip failures | **Not recorded.** Only the symptoms ("HTTP became unresponsive", "Wi-Fi route disappeared") |
| Internal DRAM saved by the Wi-Fi buffer pool trim | **Not recorded.** No byte figure anywhere |
| Whether BLE's HTTP latency penalty is coexistence or `RUN_IN_FLASH_ONLY` | **Explicitly unseparated** by the spike |
| BLE throughput, MTU, connection-interval behaviour, cadence under an active connection | **Entirely unmeasured** — no central was ever available |

### 4.3 Two documentation inconsistencies found while doing this

Recorded because they touch memory claims, not because they are in scope to fix.
**Neither was changed.**

- **`sdkconfig.defaults:36-37`** says *"The LVGL worker and HTTP server do not
  perform flash writes; keep their stacks in PSRAM"* and sets
  `CONFIG_FREERTOS_TASK_CREATE_ALLOW_EXT_MEM=y`. But `main/boost_web.c:1528`
  sets `cfg.task_caps = MALLOC_CAP_INTERNAL | MALLOC_CAP_8BIT` with
  `cfg.stack_size = 10240`, so the httpd task stack is **internal**, not PSRAM.
  Forcing it internal is almost certainly correct — the httpd task performs OTA
  flash writes, and a PSRAM stack cannot survive a disabled cache — but the
  comment describes the opposite of what the code does. 10,240 B of internal
  DRAM is not nothing at a 13,611 B budget. The LVGL worker half of the claim
  *is* honoured: `main/boost_display.c:607` sets `adapter_cfg.stack_in_psram = true`.
- **`README.md:340`** still refers to *"the active 60 MHz CO5300 QSPI trial"*.
  That trial is the phantom setting corrected in `AGENTS.md:131` and
  `README.md:134-145`; the clock is 80 MHz and owned by `BOOST_LCD_PCLK_HZ`.
  One stale sentence survived the correction.

### 4.4 An internal-DRAM consumer nobody has priced

Not a deferred feature and not something ~100 KB unblocks, but it belongs here
because it is the same failure pattern as the LVGL IRAM option — a static
internal allocation that no document mentions:

`main/boost_model.c:34` declares `static boost_log_sample_t s_logs[BOOST_LOG_CAPACITY]`
with `BOOST_LOG_CAPACITY = 1800` (`main/boost_model.h:18`). The link map places
it at `.bss.s_logs 0x3fcbc8f0 0xa8c0` — **43,200 bytes of internal DRAM**, in
`.bss`, permanently. That is larger than NimBLE's entire 36,320 B runtime cost,
spent on the 2 min 24 s telemetry ring described at `AGENTS.md:35`. It was by
some margin the largest single static internal allocation from `libmain.a` in
the map I inspected.

`CONFIG_SPIRAM_ALLOW_BSS_SEG_EXTERNAL_MEMORY` is not set (`sdkconfig:1223`), so
`.bss` is internal by default; the array carries no `EXT_RAM_BSS_ATTR`. Nothing
in the ring is DMA-touched or accessed from an ISR, and it is written at 12.5 Hz
and read only on CSV export, so PSRAM latency would be irrelevant to it. I have
**not** verified that moving it is safe or that it does not need to survive a
cache-disabled window — that requires reading the write path and the export
path properly, and this was a documentation task. Flagging it, not proposing it.

---
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

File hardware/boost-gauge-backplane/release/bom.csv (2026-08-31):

Designator | Comment | Value | Footprint | JLCPCB Part #
J1 |  |  |  | C131337
F1 |  |  |  | C3105
D1 |  |  |  | C353385
Q1 |  |  |  | C182476
R1 | 100k | 100k |  | C25803
D3 |  |  |  | C12772
U1 |  |  |  | C2879422
L2 |  |  |  | C177248
D2 |  |  |  | C22452
R2 | 100k | 100k |  | C25803
R3 | 100k | 100k |  | C23198
R4 | 24.9k | 24.9k |  | C25804
C4 | 220n | 220n |  | C64705
C5 | 22µ | 22µ |  | C45783
C21 | 22µ | 22µ |  | C45783
C6 | 100n | 100n |  | C14663
C7 | 100n | 100n |  | C14663
C17 | 1µ | 1µ |  | C15849
C18 | 100n | 100n |  | C14663
C1 | 4.7µ | 4.7µ |  | C29823
C2 | 4.7µ | 4.7µ |  | C29823
F2 |  |  |  | C70076
C8 | 10µ | 10µ |  | C19702
U2 |  |  |  | C337496
R5 | 4.7k | 4.7k |  | C23162
R6 | 4.7k | 4.7k |  | C23162
R7 | 4.7k | 4.7k |  | C23162
R8 | 4.7k | 4.7k |  | C23162
C19 | 100n | 100n |  | C14663
C20 | 100n | 100n |  | C14663
U3 |  |  |  | C37593
C9 | 100n | 100n |  | C14663
C10 | 1µ | 1µ |  | C15849
D4 |  |  |  | C503463
D5 |  |  |  | C503463
D6 |  |  |  | C503463
D7 |  |  |  | C503463
R9 | 1k | 1k |  | C21190
R10 | 1k | 1k |  | C21190
R11 | 1k | 1k |  | C21190
R12 | 1k | 1k |  | C21190
C11 | 100n | 100n |  | C14663
C12 | 100n | 100n |  | C14663
C13 | 100n | 100n |  | C14663
C14 | 100n | 100n |  | C14663
U4 |  |  |  | C83291
C15 | 100n | 100n |  | C14663
U5 |  |  |  | C107410
BT1 |  |  |  | C964721
C16 | 100n | 100n |  | C14663
J2 |  |  |  | C131339
J3 |  |  |  | C131339
J4 |  |  |  | C131339
J5 |  |  |  | C131339
H2
TP_12V_RAW
TP_12V_PROT
TP_BUCK_5V
TP_VBUS
TP_SENSOR_5V
TP_3V3
TP_GND
TP_SDA_3V3
TP_SCL_3V3
TP_SDA_5V
TP_SCL_5V
TP_A0
TP_A1
TP_A2
TP_A3
TP_U0RX
TP_U0TX
TP_GPIO16

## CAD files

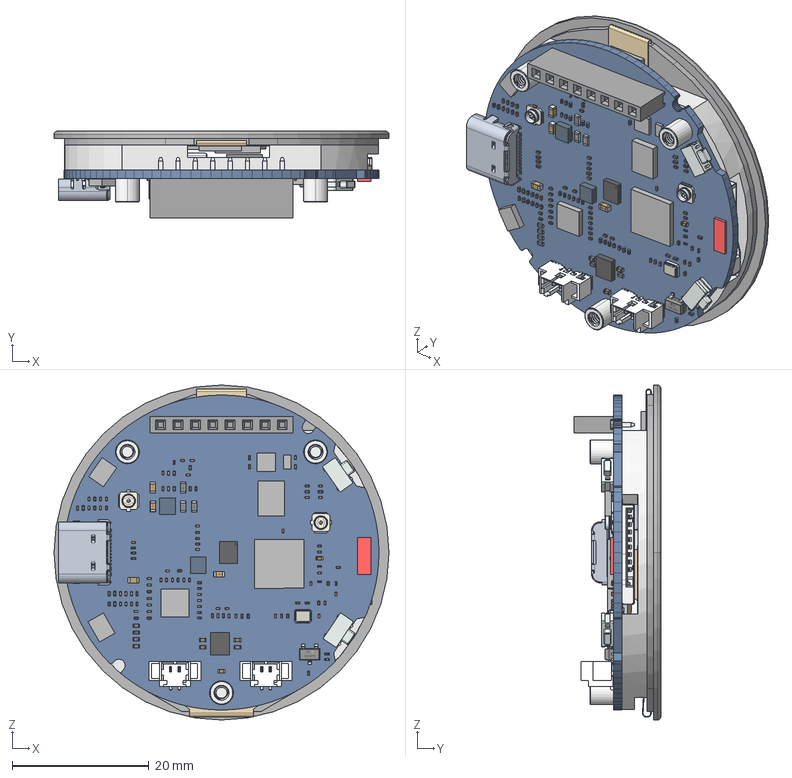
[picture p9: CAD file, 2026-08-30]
hardware/boost-gauge-backplane/reference/waveshare-esp32-s3-touch-amoled-1.75.step
49.0 x 12.7 x 49.0 mm
BOARD
USER_LIBRARY-RES_0603-0201_1 x 49
USER_LIBRARY-RES_0603-0201_2 x 49
USER_LIBRARY-RES_0603-0201_3 x 49
USER_LIBRARY-RES_0603-0201_4 x 49
HP1_25MM-2P-SMT-VERTICAL x 2
USER_LIBRARY-0201_0603M__CAP_1 x 112
USER_LIBRARY-0201_0603M__CAP_2 x 112
USER_LIBRARY-0201_0603M__CAP_3 x 112
3_1_A x 5
3_1_2_A x 4
USER_LIBRARY-U_FL-R-SMT_10_ x 2
L0201_1 x 4
L0201_2 x 4
L0201_3 x 4
EXTRUDED-320759
SWITCH-TS24CA x 2
5_1_2_A x 6
_7_AF0 x 6
EXTRUDED-350241 x 2
EXTRUDED-350664
USER_LIBRARY-QUECTEL_L76
_2_1_2_3_4_AF0 x 3
_7_1_2_AF0 x 3
SOT-23
EXTRUDED-478487
EXTRUDED-479032
EXTRUDED-479427
EXTRUDED-479822
EXTRUDED-480217
USER_LIBRARY-SM2520-4_1
USER_LIBRARY-SM2520-4_2
USER_LIBRARY-SM2520-4_3
USER_LIBRARY-SM2520-4_4
USER_LIBRARY-SM2520-4_5
EXTRUDED-485821
EXTRUDED-487336
EXTRUDED-488179
MICRO_SD_SOCKET_PU
SMTSO-M2-3_5ET x 3
PRT0003
FEMALE-2_54MM-H6-1X8P-V
C0001
FPC
H0175Y003AMT003
ESP32-S3-TOUCH-AMOLED-1_75-PMMA

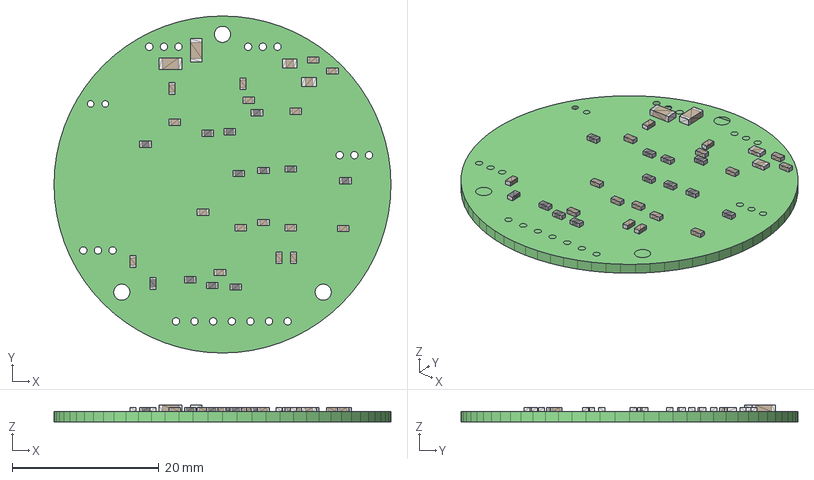
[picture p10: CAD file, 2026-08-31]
hardware/boost-gauge-backplane/release/board.step
46.0 x 46.0 x 2.30 mm

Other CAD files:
hardware/boost-gauge-backplane/reference/waveshare-esp32-s3-touch-amoled-1.75-dimensions.dwg

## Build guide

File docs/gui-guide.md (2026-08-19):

# GUI guide: gestures, pages, and the simulator

## Two-page layout and gestures

`main/boost_page.c/.h` owns two persistent pages: page 0 is the boost gauge and page 1 is the TPMS view. On the boost page, swipe **LEFT** to TPMS; on TPMS, swipe **RIGHT** to return to boost. There is no wrap-around: outward swipes at either end are ignored. Vertical theme swipes work only on page 0, and a tap resets peak only on page 0. A one-second hold toggles brightness on either page. A two-finger tap-and-hold (both fingers down) for three seconds shows a full-screen QR code that joins the SoftAP (`BoostGauge-XXXX` / `boost1234`); the 1 s hold-to-dim is suppressed while both fingers are down, and the QR is dismissed by any fresh tap.

Pointer-device events own the hold deadline independently of target jitter, and brightness is committed only after the panel command succeeds. The page coordinator forwards MAP samples only to the boost scene and TPMS snapshots only to the active TPMS scene.

Theme swipes use the ordered `boost_theme_at()` table, which is also the order emitted by `/api/v1/themes` and consumed by the web picker. The classifier tracks maximum movement during the press, not only the release coordinate: only movement within the 12 px tap slop resets peak, movement from 12 through 47 px is a rejected drag, a valid predominantly vertical drag at 48 px or more changes one theme, and horizontal or ambiguous drags do nothing. Returning to the start after a meaningful drag is still a drag, not a tap. Theme changes persist through the active-theme model path and rebuild the LVGL scene in the existing locked LVGL context.

There is intentionally no crossfade or slide animation. The live gauge uses partial internal-DMA strips, and rich faces cache static art in PSRAM; a smooth transition would require unsafe full-frame dual-scene storage or an expensive full-panel repaint that would violate the 16 ms display budget. The bounded transition is an immediate single-scene swap rather than a misleading effect.

GIF playback suppresses tap-reset, theme swipes, and page switches, but the one-second hold-to-dim still works over media.

## Dashboard behavior

- **Live / Fallback / Disconnected:** the connection badge always exposes the active transport.
- **Canvas smoothing:** 35 ms EMA over WebSocket targets; rendering is decoupled from packet cadence.
- The **gear icon** opens `/settings.html` (Wi-Fi, gauge range/zero, themes, TPMS, clock) — a separate document so browser back/forward works normally.

## Desktop simulator

Same LVGL UI, no board required:

```bash
cmake -S sim -B sim/build
cmake --build sim/build -j"$(nproc)"
./sim/build/boost_gauge_sim --screenshot preview/sim
python3 sim/raw_to_png.py preview/sim
```

Headless LXC/CI works as-is (memory display + snapshot). Windowed:

```bash
xvfb-run -a ./sim/build/boost_gauge_sim --window
```

See `sim/README.md`. Rendered screenshots live under `preview/sim/`.

The sim does **not** inherit the device's persisted settings; it calls `boost_theme_init()` at startup and renders the defaults unless told otherwise. Useful flags: `--theme <id>`, `--neon-layout tube|segments|marquee`, `--neon-preset 0..3`, `--neon-spin` (enable the marquee chase), `--tpms [normal|stale|disconnected]`, and `--screenshot [dir]`. This is the fastest verification loop — use it before burning a flash cycle.

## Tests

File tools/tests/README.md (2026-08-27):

# Boost Gauge regression tests

Two runners keep the AGENTS.md guard rails and the regression ledger
(`docs/regression-ledger.md`) executable:

| Runner | When | What it verifies |
|---|---|---|
| `python3 tools/test_suite.py` | **before every commit** | all host-side tests (existing harnesses + ledger-derived contract tests) |
| `python3 tools/check_hardware_gates.py` | **before every release / flash-to-car** | the live board's physical gates (cadence, WebSocket pool, media, OTA, logs, …) |

Both are **stdlib-only** (plus the repo's own scripts). Neither flashes the
board; `check_hardware_gates.py` only talks to the board over HTTP/WebSocket,
and its optional `--serial` capture is read-only (DTR/RTS off) - if another
session owns the port it reports SKIP, never FAIL.

## Host suite

```bash
python3 tools/test_suite.py                 # full run, one summary table
python3 tools/test_suite.py --verbose       # stream each test's output
python3 tools/test_suite.py --filter gatt   # regex on test basenames
python3 tools/test_suite.py --quick         # skip slow-flagged tests
python3 tools/test_suite.py --list          # show the registry
```

The runner invokes the four pre-existing standalone harnesses as subprocesses
(`test_mock_api.py`, `test_ble_sim.py`, `test_map_conversion.py`,
`test_rtc_epoch.py`) and then the ledger tests under `tools/tests/`. Exit code
is non-zero if anything fails. `--quick` currently changes nothing (no host
test is flagged slow yet; the slow benches are the hardware gates); the flag
and its registry plumbing are the future-proofing mechanism.

### tools/tests/ ledger tests

| Test | Guards (regression-ledger rows) |
|---|---|
| `test_web_api_contract.py` | Every `/api/v1` schema the apps parse (`/state` incl. tpms/obd/display, `/config` incl. `appBle`, `/themes` order Dyno Cell→Vault-Tec→Night City→Big Digit→Neon, `/tpms/config` bounds 100-400 kPa / 2000-120000 ms, `/time` + firmware `409 clock_rejected` 5-min rule, `/logs.csv` header, `/media` 409 overlap + repeat DELETE, `/ota` 0xE9 magic, `/restart`, `/network` GET/PUT/DELETE + saved-list semantics) |
| `test_gatt_contract.py` | Three-way consistency of `docs/bluetooth-gatt.md`, `main/boost_app_ble.c`, `tools/ble_gauge_sim`: UUIDs, 480 B/413 rule, BGL1 log format, zone tokens VAC/ATMO/BOOST/OVER, one-in-flight, `api:1` |
| `test_theme_store_invariants.py` | `s_defaults[]` order + names; sport-cluster token absence; `demoFastSweep` persisted separately from `demoMode` (`demo_fast_sweep` vs `demo_mode`) and never reset by `boost_sim_init()`; firmware/mock/sim order agreement |
| `test_nvs_key_inventory.py` | Every NVS key has an ESP_OK-gated restore (absent → default) and the ledger bounds: tpms low/stale, brightness 0-100, `BOOST_PXSHIFT_SEC_*` 30-3600, rotation 0/90/180/270, vignette ≤90, neon layout/preset clamp, saved-count ≤5, MAP supply and calibration schema gating, `app_ble` default off |
| `test_network_semantics.py` | `BOOST_NET_MAX_SAVED == 5`, scan/reconnect suspension while AP clients connected or STA has IP, timer-only auto-reconnect backoff, `BOOST_AP_PASSWORD == "boost1234"`, AP SSID `BoostGauge-%02X%02X`, QR payload format, saved-list MRU/DELETE semantics |
| `test_gesture_constants.py` | `TAP_SLOP_PX 12`, `SWIPE_MIN_PX 48`, 4:5 ratio classifier expressions, `HOLD_DIM_MS 1000`, `QR_HOLD_MS 2200` (ledger/source; AGENTS.md top-text "3 s" is flagged as doc drift), `TPMS_CAPSULE_GROW 2` in firmware + web mirror |
| `test_cadence_guard_math.py` | Pass/fail math of `check_display_cadence.py` (warmup, median ≥60, 59/60 edges, insufficient samples) and `bench_theme_matrix.py` demand coverage (≥95%, zero-demand idle, per-window cap) cross-checked against the real modules on synthetic samples |

## Hardware gates

```bash
# Full release gates (this Mac without Wi-Fi: add --skip ap)
python3 tools/check_hardware_gates.py --url http://192.168.50.102

# Skip the risky local-machine gates: AP-join (disassociates this Mac's WiFi)
# and BLE advertisement (needs blueutil/system BT data)
python3 tools/check_hardware_gates.py --skip ap --skip ble

python3 tools/check_hardware_gates.py --json           # machine-readable report
python3 tools/check_hardware_gates.py --serial /dev/cu.usbmodem14101   # read-only serial capture
```

Gates (each prints PASS/FAIL/SKIP + measured numbers + the ledger rows it
guards): `boot-health`, `cadence` (30 s soak, median ≥60), `fast-slew`
(per-theme constant-slew sweep, median ≥60, prior theme/config restored),
`ws-pool` (3 clients receive; a 4th is rejected/closed for itself only),
`http-latency` (p50 < 400 ms, informational), `ap-join` (BoostGauge-* SoftAP,
password `boost1234`, DHCP, GET /state, **always** restores the Mac's prior
Wi-Fi in a `finally` block), `ble-advertise`, `media-smoke` (tiny GIF upload →
commit → delete → empty, repeat delete harmless), `ota-state` (bad-magic body
rejected 400; no real OTA image is ever posted), `logs-ring` (strictly
increasing `t_ms`, exact CSV header, DELETE clears; the live 5 Hz ring starts a
fresh rebuild within ~100 ms).

Exit code is non-zero if any gate FAILs (SKIP is allowed). The gate runner
reboots the board via `POST /api/v1/restart` during the per-theme sweep (that
is `tools/bench_fast_motion.py`'s own precondition) and restores the pre-gate
theme/demo/pixel-shift state afterwards.

## Convention

1. Run `python3 tools/test_suite.py` before every commit - it must be green.
2. Run `python3 tools/check_hardware_gates.py` (with `--skip ap` on a Mac you
   cannot disassociate, and `--skip ble` where blueutil is unavailable) before
   every release and before flashing the car.
3. A hardware measurement claim must quote the gate output, never a host-only
   run.

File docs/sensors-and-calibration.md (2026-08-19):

# MAP sensor bus and calibration

## Sensor bus

The dedicated sensor bus is I2C port 0: **SDA=GPIO17**, **SCL=GPIO18**. It remains separate from the Waveshare BSP bus on GPIO15/14 and avoids the UART-default GPIO43/44 pads.

- ADS1115 is `0x48` with ADDR grounded; the 5 V GM 12223861 three-bar MAP signal is read on A0.
- BMP280 is `0x76` with SDO grounded and must remain on 3.3 V logic.
- `SENS_I2C_HZ` in `main/boost_sensors.c` is **100 kHz**. The run passes through a MOSFET level shifter with 4.7 kΩ pull-ups, whose rise times do not comfortably support 400 kHz in a vehicle. It is not an API, UI, NVS, or Kconfig setting.
- The sensor task runs at **16 ms**, matching the cadence contract. ADS1115 is read every loop (62.5 Hz MAP), BMP280 every tenth (6.25 Hz ambient).
- `GET /api/v1/sensors/scan` uses ESP-IDF `i2c_master_probe()`, which probes at 100 kHz independently of `SENS_I2C_HZ`, and requires four consecutive ACKs before reporting an address. That filter exists because a sweep through *changing* addresses was observed to invent one-off phantom addresses on an electrically empty bus.

Bench history for the bus failures that preceded this is in `docs/troubleshooting/i2c-sensor-bus.md`. The short version: the bus was restored by replacing the ADS1115 assembly. GPIO17/18 were never damaged, the RX/TX remap was never needed, and the 400 kHz → 100 kHz reduction was **not** the fix.

## MAP conversion (GM 12223861)

The GM 12223861 curve is defined at a **5.00 V** supply by 0.619 V → 40 kPa and 4.818 V → 304 kPa. The sensor is ratiometric, so a supply that is not 5.00 V is normalized out before the transfer function is applied:

```text
normalized_volts = map_volts * 5.00 / supply_volts
nominal_kpa      = 62.8721124 * normalized_volts + 1.08216242
corrected_kpa    = nominal_kpa + calibration.offset_kpa
gauge_kpa        = corrected_kpa - ambient_kpa      (BMP280, live)
```

The configured supply defaults to **5.20 V** and is editable in Settings. Because gauge pressure subtracts the *current* BMP280 reading, weather and altitude drift correct themselves; only sensor error needs calibrating.

## Calibration

Calibration is **manual and never automatic.** With the engine off and both the MAP port and the BMP280 open to the same atmosphere, Settings → *Calibrate MAP to ATM* observes ~2 s of samples and stores `offset_kpa = mean(bmp) - mean(nominal)`. It refuses stale, unstable, implausible, or over-limit readings, and a failure never disturbs the existing calibration. Recalibration **replaces** the offset — nominal is always recomputed from raw volts, so offsets cannot compound.

One known pressure identifies zero error but cannot independently identify sensor gain, so the correction is deliberately **additive in kPa**: exact at atmosphere (the reading that must be right), degrading gracefully toward full boost. `ref_map_volts` is stored so a second calibration point could be added later without a schema migration. Do not convert this to a multiplicative fit on one point.

Supply voltage and the calibration record live under their own NVS keys (`map_vsup`, `map_cal`) in the `boost` namespace rather than inside `boost_config_t`, so growing them never risks discarding existing gauge settings. Editing the supply after calibrating re-derives the offset from the stored raw reference instead of stacking a correction on the old normalization. Note: a badly wrong supply entry is absorbed into a correspondingly large offset — the gauge still reads zero at atmosphere but is mis-scaled under boost, so check the displayed offset after changing supply and recalibrate.

Calibration diagnostics live on `GET /api/v1/sensors/calibration`, deliberately *not* on `/state` or the WebSocket payload: that path runs at 62.5 Hz into a smaller JSON buffer, and Settings must be able to show real sensor state even while demo mode is driving the gauge.

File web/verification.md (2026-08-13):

# Web Control Plane Verification

This checklist is for firmware **0.3.0-web** and the current raw-media/WebSocket
control plane. Run live checks against a board on a trusted LAN or its SoftAP;
the mock server covers only static assets and simple HTTP wiring.

## Environments

| Environment | URL | Real firmware? |
|---|-----|---|
| STA/LAN | `http://<BOOST_WEB_IP>/` | Yes |
| SoftAP | `http://192.168.4.1/` | Yes |
| Mock | `http://127.0.0.1:18080/` | No |

## Baseline and API smoke

Against `BOOST_WEB_IP` (or `192.168.4.1` in SoftAP mode), confirm:

1. `/`, `/app.js`, and `/styles.css` load from local assets.
2. `GET /api/v1/state`, `/config`, `/network`, `/themes`, `/logs`, and
   `/media/status` return valid JSON.
3. `POST /api/v1/time` returns an `epochMs` close to the host clock.
4. `PUT /api/v1/config` changes brightness and the subsequent state reflects
   it; apply the change asynchronously without making the dashboard unusable.
5. `PUT /api/v1/themes/active` succeeds for every returned theme id.
6. Enable a whole-day dim schedule and then disable it; the physical
   brightness follows each change.
7. `GET /api/v1/logs?limit=120`, `DELETE /api/v1/logs`, and
   `GET /api/v1/logs.csv` all work.
8. `PUT /api/v1/network` with `keepPassword:true` returns promptly and an
   unchanged STA remains connected.
9. An invalid OTA body is rejected with 4xx.

Example read-only/API probes:

```sh
BOARD_URL="http://${BOOST_WEB_IP:?set BOOST_WEB_IP}"
curl -fsS "$BOARD_URL/api/v1/state"
curl -fsS "$BOARD_URL/api/v1/config"
curl -fsS "$BOARD_URL/api/v1/network"
curl -fsS "$BOARD_URL/api/v1/themes"
curl -fsS "$BOARD_URL/api/v1/media/status"
curl -fsS "$BOARD_URL/api/v1/logs?limit=120"
curl -fsS "$BOARD_URL/api/v1/logs.csv" -o /tmp/boost-gauge-log.csv
```

## Raw-media upload and migration checks

Use a valid 466 × 466 GIF fixture whose size is exactly **1,379,129 bytes**.
The browser preview is intentionally disabled. Record the `time_total` from
the upload and verify the returned status reports the committed media:

```sh
GIF='/path/to/IMG_5325-ezgif.com-optimize (2).gif'
test "$(stat -c%s "$GIF")" -eq 1379129
curl --fail --silent --show-error \
  --output /tmp/media-upload.json \
  --write-out 'upload_time_total=%{time_total}\nhttp_code=%{http_code}\n' \
  -X POST "$BOARD_URL/api/v1/media" \
  -H 'Content-Type: image/gif' \
  -H 'X-Filename: full-fixture.gif' \
  --data-binary @"$GIF"
curl -fsS "$BOARD_URL/api/v1/media/status"
```

Latest hardware result: the full **1,379,129-byte** upload completed in
**7.504 s** through the raw dual-slot partition. This is the current speed
baseline; do not substitute the earlier fragile tuned-SPIFFS result (7.37 s)
or the prior SPIFFS regression (about 172 s).

Defend atomicity and cancellation with an existing committed GIF:

1. Upload a small valid GIF and confirm `media/status` says `present:true`.
2. Start the full upload, then click **Delete** before it completes. The
   browser must abort the XHR, wait for that request to settle, and only then
   send `DELETE /api/v1/media`.
3. Confirm the aborted upload does not replace the prior GIF. The previous
   committed media is preserved and restored after the abort; the subsequent
   delete then removes it.
4. Issue Delete twice more after the upload has settled. Both repeated deletes
   must succeed and leave `present:false`; no stale playback or UI error may
   remain.
5. For a direct overlap test, send DELETE while POST is still active. The
   server must reject the overlap with **409** (`media_upload_in_progress`);
   the browser's ordered cancel-and-delete path should avoid that race.

The raw-media migration guard is architectural, not just a speed check:

- Partition label is `media`, offset `0x820000`, size `0x7E0000`, split into
  two slots. Confirm the table before flashing:

  ```sh
  grep -E '^media[[:space:]]' partitions.csv
  ```

- The inactive slot erases only the required aligned range, streams payload and
  CRC, and writes the committed header last. On boot, the store scans
  CRC-valid headers and selects the newest generation. Reboot after a commit
  and confirm `GET /api/v1/media/status` still reports the same GIF.
- Playback maps the committed payload through the LVGL variable descriptor;
  it is not a `/spiffs/active.gif` staging-file check. An aborted or invalid
  upload must leave the prior valid slot selected.

## Live telemetry and browser responsiveness

The live path is WebSocket, not SSE: connect to `/api/v1/state/ws`. The server
uses a fixed pool of **3 clients**, each with at most one in-flight heap-owned
frame, and broadcasts at a bounded **20 Hz**. A new dashboard must not evict an
existing socket. The browser sends an application heartbeat every **750 ms**;
the server consumes it. Verify three concurrent dashboards remain WebSocket
`OPEN` for 30 seconds with heartbeat active and no HTTP polling. The latest
hardware capacity run kept three sockets open while a fourth dashboard remained
live through HTTP fallback; no existing dashboard was evicted.

The connection badge reports **Live · WebSocket 20 Hz**, **Live · HTTP 4 Hz**,
or **Disconnected**. The browser applies only strictly newer `uptimeMs` targets,
renders a 35 ms EMA on every `requestAnimationFrame`, and resets timing after a
gap greater than **1 s**. The sparkline remains **4 Hz** and canvas DPR is capped
at **2**. On the demo waveform, collect ten seconds of browser samples and require
approximately 50 ms WebSocket target spacing; compare target-to-render error with
the prior 10 Hz / 90 ms EMA baseline rather than using physical-display FPS.

Background logging is independent of transport cadence: firmware stores one
sample every 200 ms (**5 Hz**), so the 18,000-row ring covers **1 hour**. CSV
export must preserve that full retained window.

Close or block the WebSocket and verify the browser starts HTTP
`GET /api/v1/state` fallback at **4 Hz** (every 250 ms). A successful fallback
sample must change the badge to **Live · HTTP 4 Hz**; it becomes **Disconnected**
only when state polling also fails. Restore the socket and verify the badge
returns to **Live · WebSocket 20 Hz** without duplicate polling timers.

### Fourth-client capacity check

Use four separate browser tabs or four WebSocket clients against
`ws://<board>/api/v1/state/ws` while the board is publishing telemetry:

1. Open clients 1–3 and confirm all three remain `OPEN` for at least 30 s with
   the 750 ms application heartbeat and no HTTP polling.
2. Open client 4. Its handshake is the only one that may be closed/rejected;
   clients 1–3 MUST remain open and continue receiving newer `uptimeMs` values.
   A fourth tab must not evict an existing dashboard or cause its badge to
   churn.
3. In the fourth tab, block/close WebSocket traffic. Confirm
   `GET /api/v1/state` runs every 250 ms (4 Hz), and that a successful sample
   shows **Live · HTTP 4 Hz** while WebSocket retries occur every 1 s. The badge
   becomes **Disconnected** only after both transports fail.
4. Restore the socket and confirm polling stops with one timer, the badge changes
   to **Live · WebSocket 20 Hz**, and clients 1–3 were never disconnected.

This check distinguishes capacity rejection of the newcomer from the forbidden
behavior of failing the whole fourth dashboard or evicting an existing client.

### GIF ownership and lifecycle check

Trace one upload through the board logs/source before changing playback. Verify
the custom layers are web upload, raw dual-slot CRC/committed-header publication,
`esp_partition_mmap`, and the locked `lv_image_dsc_t`/`lv_gif` gauge integration.
Verify `lv_gif.c` delegates `GIF_openRAM`/`GIF_playFrame` to bundled
AnimatedGIF for parsing, LZW, frame timing, and composition; this is not a
project-written decoder. Confirm the intentional standard-decoder choice: the
full framebuffer is zeroed and `pTurboBuffer` is null because turbo did not
compose delta/disposal frames correctly. During delete or replacement, verify
the order display lock → destroy widget → unmap; mapped bytes must not be freed
or unmapped while the widget exists. The custom display flush remains the
internal-DMA partial CO5300 path and is not GIF decompression.

During a 30-second dashboard soak, exercise a control (for example, theme or
brightness) while telemetry is active. Latest verified result: maximum
main-thread probe was **9 ms**, with **no freezes longer than 500 ms**.
Telemetry publication is outside the LVGL worker, so GIF playback must not
stall the WebSocket stream.
## Clock and CSV verification

The **Sync Time** control is the only synchronization action. Its `POST
/api/v1/time` supplies browser `Date.now()` and the configured offset; firmware
calls `settimeofday` and saves epoch plus monotonic checkpoint/config to NVS.
On reboot it restores that checkpoint and advances only by monotonic delta when
applicable. There is no RTC/NTP resynchronization in this path, so opening the
dashboard alone does not sync the device.

CSV `timestamp_local` must be `%Y-%m-%dT%H:%M:%S` with no suffix;
`utc_offset_minutes` remains separate. Hardware verification produced **1,800
rows**, `badTimestampCount 0`, and offset `-300` minutes.
***
***

## Physical cadence and crash-log guards

With GIF media deleted and the live gauge animating, run the cadence guard:

```sh
python3 tools/check_display_cadence.py \
  --url "${BOARD_URL}" --seconds 30
```

Latest hardware result was **min 61, median 63 over 112 samples**. The gauge
and sampling contract remains **16 ms / approximately 60 Hz**. Do not run
this live-gauge threshold while GIF playback is active; GIF decoder rendering
is a different workload.

Capture the serial output during the live-gauge and media/reboot checks, then
fail the review if any display-memory, panic, reset, or crash marker appears:

```sh
! grep -E \
  'ESP_ERR_NO_MEM|send color data failed|Guru Meditation|panic|abort|rst:0x|Brownout' \
  serial.log
```

The expected result is no matching line. In particular, preserve the DMA
display path's no-`ESP_ERR_NO_MEM` behavior while Wi-Fi is active.

## Mock and SoftAP smoke

Mock-server wiring (no WebSocket or hardware claims):

```sh
python3 -m py_compile tools/mock_server.py
node --check web/app.js
python3 tools/mock_server.py --host 127.0.0.1 --port 18080
curl -I -s http://127.0.0.1:18080/
curl -fsS http://127.0.0.1:18080/api/v1/state
curl -fsS http://127.0.0.1:18080/api/v1/config
curl -fsS http://127.0.0.1:18080/api/v1/themes
curl -fsS http://127.0.0.1:18080/api/v1/logs.csv
```

On hardware, join `BoostGauge-XXXX` with `boost1234`, open
`http://192.168.4.1/`, and repeat the live WebSocket, media, cadence, and
serial crash-log checks above. The physical gauge must resume after media is
deleted and its PSI must change during the live sweep.

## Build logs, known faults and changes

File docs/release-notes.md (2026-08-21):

# Release notes

The latest release notes also ship in `release/` (see `release/README.md`). Prebuilt firmware is on the [releases page](https://github.com/ZiadAbdelati/waveshare-boost-gauge/releases/latest).

## v0.8.1

v0.8.1 adds **Doto** as the second Neon readout face and fixes two rendering regressions found while validating the new font.

- **Doto Neon readout.** Tube, Segments, and Marquee can use a modular Doto ROND 100 / weight 700 readout, persisted through NVS and mirrored in the dashboard. Doto uses raw A8 coverage without the SF Alien halo, plus a custom three-dot minus with tested signed spacing.
- **Neon ATMO label.** The zero-pressure zone now reads `ATMO` in white in both firmware and the web mirror.
- **Marquee wrap fix.** Spin and zone-flip invalidation now wrap complete bulb indices, preventing the outer-ring bulb at 12 o'clock from retaining stale colour across circular group boundaries.
- **Boot reliability.** The ESP-IDF main-task stack is 8,192 bytes so a persisted Neon scene can finish its synchronous glyph bake before brightness and networking start.
- **Reproducible assets.** The prepared static Doto dashboard font and SIL OFL license ship with the firmware; `tools/generate_doto_font.py` deterministically regenerates the LVGL subset.

Host verification covers the native geometry assertions, firmware/web parity, deterministic font and embedded-asset generation, Python/Node syntax, MAP conversion, RTC epoch conversion, and the ESP-IDF build. Hardware acceptance results are recorded in `release/README.md` and the regression ledger.

## v0.8.0

The headline of v0.8.0 is the **battery-backed clock**: the wall clock is now authoritative from a **DS3231 RTC on the sensor I2C bus**, so it survives power-off without Wi-Fi, the dim schedule stays correct, and a wrong browser clock can no longer corrupt it. Timezones are now **DST-aware** via a POSIX TZ string, and a pair of latent bugs in the RTC write path and the `/state` offset were fixed on hardware.

- **DS3231 RTC as boot-time clock authority.** `boost_sensors_rtc_read/write` (probe 0x68 on the shared sensor bus) reject OSF/garbage/implausible time; the seed runs before boot brightness is decided, so a night boot with a set RTC comes up dim from the first frame with no Wi-Fi. A browser Sync writes the RTC as calibration. Hardware-verified across soft resets and a full power-off.
- **RTC is the write authority too.** `POST /api/v1/time` more than 5 min from a valid DS3231 is rejected with `409 clock_rejected` *before* touching the system clock/NVS/RTC.
- **OSF cleared on write.** The DS3231 does *not* auto-clear its oscillator-stop flag when the time registers are written; `boost_sensors_rtc_write()` now clears it explicitly (status 0x0F) under the bus-admin lock.
- **DST-aware timezone (POSIX TZ string).** Config stores `timezoneTz` (e.g. `EST5EDT,M3.2.0/2,M11.1.0/2`) applied via `setenv("TZ")+tzset()`; the dim schedule, CSV, and the effective offset use `localtime()`, so DST is automatic. `/state` reports the DST-effective offset; `/config` keeps the stored standard offset for the dropdown.
- **`/state` offset stability.** `publish_sample()` no longer clobbers the DST-effective `timezoneOffsetMinutes` with the stored standard offset, which previously made the dashboard clock flicker by one hour across DST.
- **I2C bus hardening.** RTC read/write now hold the bus-admin mutex (the reset takes no lock); recovery honors ADS/BMP re-config returns (no silent 0 V false-good) and re-probes devices absent at boot; the live scan is time-capped (5 s).
- **Web fixes.** The timezone dropdown no longer reverts to the old zone when saving; the `UTC-04:00` entry is relabeled **Atlantic Time**; the Sync button is renamed **Save**.

Hardware verification this release covered boot, LAN + SoftAP network access, the DS3231 seed/authority and OSF clearing, the DST-effective `/state` offset, the bus scan and RTC coexistence, and the served web assets. The display cadence/media paths are unchanged from v0.7.1 (this release touches clock, I2C, and web only).

## Earlier releases

See the [GitHub releases page](https://github.com/ZiadAbdelati/waveshare-boost-gauge/releases) and the tags for notes on prior versions.

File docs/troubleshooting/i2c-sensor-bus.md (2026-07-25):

# Troubleshooting the external I2C sensor bus

Bench investigation log for the ADS1115 + BMP280 bus on I2C port 0
(SCL=GPIO18, SDA=GPIO17, 100 kHz). Kept out of the README because it is history,
not architecture; the README states the final design and the regression ledger in
`AGENTS.md` carries the durable lessons.

## Final state

Both devices are discoverable and reading on the **original** GPIO18/17 pins:

```
{"busUp":true,"recoveries":0,"found":["0x48","0x76"]}
"sensors":{"adsPresent":true,"bmpPresent":true,"fault":false,
           "mapVolts":1.5735,"ambientKpa":98.58}
```

The bus was restored by **replacing the ADS1115 assembly**, per the
`2026-07-25-map-atmosphere-calibration-design.md` field finding. GPIO17 and
GPIO18 were not damaged, the RX/TX remap was never needed, and the 400 kHz to
100 kHz reduction was **not** the fix. 100 kHz is retained on its own merits: the
run passes through a MOSFET level shifter with 4.7 kOhm pull-ups, whose rise
times do not comfortably support 400 kHz in a vehicle.

## What the symptoms looked like

The sequence is worth recognising because almost every stage pointed somewhere
misleading.

1. Both sensors undetected. `/api/v1/sensors/scan` returned `found: []`.
2. The board schematic was decoded to confirm GPIO17 is clean: ESP pin 23, TP14,
   and the header, nothing else. The clamp had to be external.
3. SCL measured correctly at the level shifter (3.3 V on LV2, 5.5 V on HV2) while
   SDA measured **0 V** on LV1/HV1. Moving SDA to LV4/HV4 restored it: the scan
   found both addresses and blowing into the MAP sensor moved the gauge.
4. It failed again spontaneously, minutes later, with SDA back at 0 V.
5. Boot-time and runtime bus recovery were implemented and flashed. Both ran and
   the bus stayed empty, which **rules out a stuck slave holding SDA** — a
   clock-out releases that. This is a physical fault, not an I2C lockup.
6. With both sensors and the level shifter removed entirely, an otherwise empty
   bus carrying only pull-ups still returned changing one-off addresses on every
   sweep. That turned out to be a scanner artifact, not a bus fault (below).
7. A BMP280 wired directly at 3.3 V, with the ADS removed, still would not ACK
   reliably: 0-4 successes per 32 probes at `0x76`, against 0-2/32 for the
   deliberately absent `0x48` control.

Stages 6 and 7 are the reason this took so long: a broken measurement instrument
was layered on top of a genuine hardware fault, and each one kept producing
evidence that discredited the other.

## Diagnostic reasoning that held up

- **A disconnected SDA floats high.** With I2C active, SDA is open-drain and
  idles high through the pull-up. A steady 0 V therefore means something is
  actively pulling it down — a short, or a device clamping the line. It does not
  mean "not connected".
- **A voltage-high reading does not prove continuity.** Both the MCU side and the
  sensor module have pull-ups, so each end can read 3.3 V with the wire between
  them broken. Continuity must be tested endpoint-to-endpoint with power off.
- **Clock-out recovery that changes nothing is informative.** It falsifies the
  entire class of stuck-slave explanations in one test.
- **Boot-time presence flags are not evidence of a live sensor.** `adsPresent`
  and `bmpPresent` were both true while the bus was dead, because they record
  what answered once at boot. This is why the calibration path now gates on
  explicit freshness (`ads_age_ms` / `bmp_age_ms` / `bmp_updates`) instead.

## The phantom-address scanner bug

Independently of the hardware fault, `/api/v1/sensors/scan` was inventing
addresses. Three controls isolated it:

| Control | Result | Reading |
|---|---|---|
| Manual bit-banged probe at unused `0x55` | 0/64 ACKs, idle-low counters both zero | The bus is electrically clean and idles correctly |
| Driver `i2c_master_probe()` repeatedly at fixed `0x55` | 64/64 `ESP_ERR_NOT_FOUND` | The driver does not false-ACK at a *fixed* address |
| Driver probe at onboard touch `0x5A` | 8/8 ACK | The driver does detect a device that is genuinely there |

Phantoms appeared only when `i2c_master_probe()` swept through **changing**
addresses. Requiring **four consecutive ACKs** before reporting an address made
20/20 empty-bus scans correctly empty, at 19-38 ms per scan.

This strongly implicates the changing-address probe sequence. Without waveform
capture it does not formally rule out every data-pattern-dependent electrical
mechanism, so the four-ACK filter is retained as the guard rather than treated as
a closed root cause.

## If it happens again

In order, cheapest first:

1. `curl http://<board-ip>/api/v1/sensors/scan` — expect `["0x48","0x76"]`.
   Check `recoveries`: a climbing count means the bus is wedging and self-healing.
2. `curl http://<board-ip>/api/v1/sensors/calibration` — check `mapAgeMs` and
   `bmpAgeMs`. Fresh ages with a stale-looking gauge is a conversion problem, not
   a bus problem. `-1` means the sensor has never read successfully.
3. Power off, then **continuity-test endpoint-to-endpoint**: VCC, GND, SCL, SDA.
   Near-zero ohms on each intended conductor, and no SCL/SDA short to ground.
4. Reseat every jumper at both ends and tug-test. An intermittent that works then
   fails on bench vibration is a connector, not firmware.
5. Only then suspect the level shifter or a device. Swap one part at a time and
   require **sustained valid reads**, not just an address ACK — address presence
   and working device are separate gates, as stage 7 above demonstrates.

Firmware self-heal is already in place and does not need to be re-added: an
in-place `i2c_master_bus_reset()` fires after sustained read failures and once at
boot if nothing answers, serialized against HTTP scans by a bus-admin mutex.

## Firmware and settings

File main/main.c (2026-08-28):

#include "freertos/FreeRTOS.h"
#include "freertos/task.h"
#include "freertos/queue.h"

#include "esp_log.h"
#include "boost_display.h"

#include "boost_brightness.h"
#include "boost_gauge.h"
#include "boost_page.h"
#include "boost_model.h"
#include "boost_theme.h"
#include "boost_sim.h"
#include "boost_sensors.h"
#include "boost_tpms.h"
#include "boost_tpms_mock.h"
#include "boost_app_ble.h"
#include "boost_obd.h"
#include "boost_obd_ble.h"
#include "esp_ota_ops.h"
#include "esp_partition.h"
#include "boost_web.h"

static const char *TAG = "boost_main";

/*
 * The one place the demo/real source is chosen. Demo mode (persisted, default
 * off) runs the synthetic sweep; otherwise we hand back the latest real-sensor
 * snapshot, which the sensor task computes on its own cadence so neither the
 * LVGL timer nor the web task ever blocks on an I2C read.
 */
static boost_sample_t next_sample(void)
{
    if (boost_theme_demo_mode()) {
        return boost_sim_tick();
    }
    return boost_sensors_get_sample();
}

/* LVGL timer owns the physical gauge, preserving its 16 ms render cadence. */
static void gauge_timer_cb(lv_timer_t *timer)
{
    LV_UNUSED(timer);
    const boost_sample_t sample = next_sample();
    boost_page_update(&sample);
    lv_timer_set_period(timer, 16U);
}

/* TPMS runs on its own slow cadence: tire pressures change in seconds, not
 * milliseconds, so a 250 ms tick keeps the page fresh without sharing the
 * 16 ms gauge path. With the OBD2 BLE link enabled the OBD driver publishes
 * real vehicle data and the mock provider stays idle; otherwise the mock
 * stands in so the page stays lively on the bench. */
static void tpms_timer_cb(lv_timer_t *timer)
{
    LV_UNUSED(timer);
    /* The mock stands in ONLY while demo mode drives the gauge: on the bench
     * the page stays lively without hardware, but a real vehicle (demo off)
     * with no adapter must show no data, never simulated pressures. */
    if (boost_theme_demo_mode() && !boost_theme_tpms_ble()) {
        boost_tpms_mock_tick(lv_tick_get());
    } else {
        boost_tpms_age(lv_tick_get());
    }
    boost_tpms_snapshot_t snapshot;
    boost_tpms_get_snapshot(&snapshot);
    boost_page_update_tpms(&snapshot);
    float psi[4];
    bool valid[4];
    for (int i = 0; i < 4; ++i) {
        psi[i] = snapshot.wheel[i].psi;
        valid[i] = snapshot.wheel[i].valid;
    }
    boost_model_publish_tpms(psi, valid, (int)snapshot.status);
}

/* Web/model publication stays independent when a GIF occupies the LVGL worker. */
static void sample_task(void *arg)
{
    (void)arg;
    TickType_t next_wake = xTaskGetTickCount();
    while (true) {
        const boost_sample_t sample = next_sample();
        boost_model_publish_sample(&sample);
        /* Kick the WebSocket push task straight away: the sample is the event,
         * so remote clients no longer wait out a free-running 50 ms timer. */
        boost_web_notify_sample();

        boost_display_metrics_t metrics;
        boost_display_get_metrics(&metrics);
        boost_model_set_display_metrics(&metrics);
        boost_model_refresh_status();
        boost_model_apply_schedule();

        vTaskDelayUntil(&next_wake, pdMS_TO_TICKS(16));
    }
}

void app_main(void)
{
    ESP_LOGI(TAG, "Boost gauge starting");

    /* Before boost_model_init(): the model resolves the active theme by id and
     * must see any persisted colour overrides. Mounts NVS itself, so this does
     * not depend on running after boost_model_init(). */
    boost_theme_init();
    ESP_ERROR_CHECK(boost_model_init());

    /* Real-sensor path: I2C on GPIO18/17 (separate from the BSP touch bus on
     * GPIO14/15). Brings up the bus, probes ADS1115 (0x48), BMP280 (0x76) and
     * the DS3231 RTC (0x68), and starts the reader task. Runs regardless of the
     * demo flag so a runtime flip to real mode has data waiting; init logs which
     * sensors were seen. Deliberately before boot brightness is decided and the
     * panel is started: a valid DS3231 seeds the wall clock, so a night boot
     * comes up dim from the first frame instead of bright until a browser sync. */
    if (!boost_sensors_init()) {
        ESP_LOGW(TAG, "no MAP/ambient sensors detected; real mode will fault until wired");
    }
    if (boost_model_seed_clock_from_rtc() != ESP_OK) {
        ESP_LOGW(TAG, "no valid DS3231 time; clock falls back to NVS/sync");
    }

    boost_config_t cfg;
    boost_model_get_config(&cfg);

    const int boot_pct = boost_model_boot_brightness();
    /* Boot the panel fully dark (0%) and ramp to the schedule brightness only
     * after the first gauge frame is on screen, so the uninitialized white GRAM
     * never flashes - not even at the dim night level. */
    lv_display_t *disp = boost_display_start(0);
    if (disp == NULL) {
        ESP_LOGE(TAG, "boost_display_start failed");
        return;
    }

    /* Apply the persisted tearing-effect preference now that both the theme
     * store and the display exist. Default is off. */
    boost_display_set_te(boost_theme_te_sync());
    boost_display_set_region_dbuf(boost_theme_region_dbuf());
    boost_display_set_te_scanline(boost_theme_te_scanline());

    /* Start from persisted config. Long-press toggles between the configured
     * high/low pair - the same brightnessLow the dim schedule uses - rather
     * than the compile-time fallbacks. Brightness stays 0% until the first
     * frame renders below, then ramps to boot_pct. */
    boost_brightness_set_levels(cfg.brightness_high, cfg.brightness_low);

    boost_sim_init();

    /* TPMS service: mock provider until the BLE adapter profile is verified. */
    boost_tpms_init();
    boost_tpms_start();
    boost_tpms_mock_set_scenario(BOOST_TPMS_MOCK_NORMAL);

    ESP_LOGI(TAG, "sample source at boot: %s", boost_theme_demo_mode() ? "DEMO (sim)" : "real sensors");

    /* The physical gauge receives samples directly in its LVGL timer. */

    if (boost_display_lock(-1) == ESP_OK) {
        boost_page_create();

        const boost_sample_t initial = next_sample();
        boost_page_update(&initial);
        lv_timer_t *gauge_timer = lv_timer_create(gauge_timer_cb, 16, NULL);
        if (gauge_timer == NULL) {
            boost_display_unlock();
            ESP_LOGE(TAG, "failed to create gauge timer");
            return;
        }
        lv_timer_ready(gauge_timer);
        lv_timer_create(tpms_timer_cb, 250, NULL);
        boost_display_unlock();
        ESP_LOGI(TAG, "main stack minimum free after scene build: %u B",
                 (unsigned)(uxTaskGetStackHighWaterMark(NULL) * sizeof(StackType_t)));
    } else {
        ESP_LOGE(TAG, "display lock failed during UI create");
        return;
    }
    /* The first frame is on screen now (dark gauge over a dark panel): ramp to
     * the schedule brightness. The short delay lets the LVGL worker finish the
     * first render so the white boot GRAM is never shown at any brightness. */
    vTaskDelay(pdMS_TO_TICKS(100));
    boost_brightness_init(boot_pct);
    const BaseType_t sample_task_ok = xTaskCreatePinnedToCore(
        sample_task, "boost_sample", 4096, NULL, 4, NULL, 0);
    if (sample_task_ok != pdPASS) {
        ESP_LOGE(TAG, "failed to start sample task");
    }

    esp_err_t web_err = boost_web_start();
    if (web_err != ESP_OK) {
        ESP_LOGE(TAG, "web control plane failed: %s", esp_err_to_name(web_err));
    }

    /* BLE radio: the OBD2 BLE central and the companion-app GATT peripheral
     * share one NimBLE host. Brought up AFTER the web control plane so a BLE
     * init failure can never precede OTA recovery (the RAM boot-loop class).
     *
     * Ordering is load-bearing (hardware-verified 2026-08-23: a boot-looping
     * LoadProhibited in ble_hs_lock when the host APIs ran unmounted):
     *   1. boost_obd_ble_init() MOUNTS the host (nimble_port_init; RAM-guarded,
     *      idempotent) whenever EITHER persisted toggle may need the radio.
     *   2. boost_app_ble_init() reads its persisted toggle and registers the
     *      companion GATT service — legal only while the host is mounted but
     *      NOT started. Skipped safely when the mount was refused.
     *   3. boost_obd_ble_host_start() starts the host task; ble_gatts_start()
     *      then runs from the host sync callback.
     * appBle gates ADVERTISING, not registration, so flipping it at runtime
     * never needs the host to restart. If the host was never mounted at boot
     * (both toggles off), boost_app_ble_start() performs mount -> register ->
     * start itself on demand. */
    boost_obd_init();
    const bool obd_ble = boost_theme_tpms_ble();
    if (obd_ble) {
        boost_obd_ble_init();
    }
    boost_app_ble_init();
    boost_obd_ble_host_start();
    boost_obd_set_enabled(obd_ble);
    if (boost_app_ble_enabled()) {
        boost_app_ble_start();
    } else {
        boost_app_ble_stop();
    }

    /* OTA rollback gate. With CONFIG_BOOTLOADER_APP_ROLLBACK_ENABLE, a freshly
     * OTA'd image boots in PENDING_VERIFY and must confirm itself healthy or the
     * bootloader reverts to the previous slot on the next reset. "Healthy" here
     * means the control plane came up, i.e. the device can be reached for the
     * *next* OTA - which is exactly the property a rolled-back boot loop lacks.
     * The board runs from 5 V with no serial, so this auto-revert is the safety
     * net that makes a bad flash recoverable without a cable. */
    if (web_err == ESP_OK) {
        const esp_partition_t *running = esp_ota_get_running_partition();
        esp_ota_img_states_t state;
        if (running != NULL && esp_ota_get_state_partition(running, &state) == ESP_OK &&
            state == ESP_OTA_IMG_PENDING_VERIFY) {
            if (esp_ota_mark_app_valid_cancel_rollback() == ESP_OK) {
                ESP_LOGI(TAG, "OTA image confirmed healthy; rollback cancelled");
            } else {
                ESP_LOGW(TAG, "failed to mark OTA image valid");
            }
        }
    } else {
        ESP_LOGW(TAG, "control plane down; leaving OTA image unconfirmed for rollback");
    }

    ESP_LOGI(TAG, "tap=reset peak · hold 1s=brightness toggle · AP password boost1234");
}

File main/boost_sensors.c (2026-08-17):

#include "boost_sensors.h"

#include <math.h>
#include <string.h>
#include <sys/time.h>
#include <time.h>

#include "freertos/FreeRTOS.h"
#include "freertos/task.h"
#include "freertos/semphr.h"

#include "driver/i2c_master.h"
#include "esp_log.h"
#include "esp_timer.h"
#include "nvs.h"
#include "nvs_flash.h"

static const char *TAG = "boost_sensors";

/* ---------------------------------------------------------------------------
 * Bus + address map
 * ---------------------------------------------------------------------------
 * Our sensors live on a bus that is deliberately separate from the BSP's
 * touch/IO-expander bus (BSP_I2C_SCL=GPIO14, BSP_I2C_SDA=GPIO15, port 1). We
 * take I2C port 0 on the exposed GPIO18/17 pads, which the BSP pin map never touches, so there
 * is no double-init of a bus the BSP already owns and no pin collision.
 *
 * 100 kHz is deliberate and load-bearing: it is the rate the bus was proven
 * stable at during the hardware investigation. Do not raise it.
 */
#define SENS_I2C_PORT       I2C_NUM_0
#define SENS_SCL_GPIO       18
#define SENS_SDA_GPIO       17
#define SENS_I2C_HZ         100000
#define SENS_IO_TIMEOUT_MS  50

#define ADS1115_ADDR        0x48   /* ADDR pin -> GND */
#define BMP280_ADDR         0x76   /* SDO pin  -> GND */
#define DS3231_ADDR         0x68   /* battery-backed UTC RTC */
/* A single probe on this bus has been observed to ACK a phantom address once;
 * four consecutive ACKs is the filter that made the scanner trustworthy. */
#define SCAN_CONFIRM_ATTEMPTS 4
/* A live scan is a poor witness on this bus (a real device has measured 0-4 of
 * 32 ACKs) and each probe can time out at SENS_IO_TIMEOUT_MS, so the full sweep
 * could hold the bus-admin lock - and thus the httpd task - for tens of seconds
 * on a hung bus. This budget bounds one scan to a few seconds. */
#define SCAN_TIME_BUDGET_US (5 * 1000 * 1000)
/* How long the RTC read/write (called from the main/httpd tasks) will wait for
 * the bus-admin lock before giving up, so a Sync/seed never blocks behind a
 * long scan or recovery. */
#define RTC_LOCK_WAIT_MS 500

/* ---------------------------------------------------------------------------
 * ADS1115 (GM 3-bar MAP on A0, single-ended)
 * ---------------------------------------------------------------------------
 * Registers: 0x00 conversion, 0x01 config.
 *
 * Config word we program (continuous conversion so the reader just fetches the
 * latest code without a per-read wait):
 *   OS=1  MUX=100 (AIN0 vs GND)  PGA=000 (+/-6.144 V FSR)  MODE=0 (continuous)
 *   DR=101 (250 SPS)  COMP disabled (COMP_QUE=11)
 *   -> high byte 0xC0, low byte 0xA3
 *
 * PGA note: the GM 3-bar sensor is ratiometric to its supply and swings up to
 * ~4.8 V, so the ADS1115 must be 5 V powered and the +/-6.144 V range is the
 * only one that covers the full span. LSB = 6.144/32768 = 187.5 uV. If the ADS
 * is instead run at 3.3 V, the input cannot exceed VDD; change the divider /
 * range accordingly. These are the two knobs to touch, nothing else.
 */
#define ADS_REG_CONVERSION  0x00
#define ADS_REG_CONFIG      0x01
#define ADS_CONFIG_HI       0xC0
#define ADS_CONFIG_LO       0xA3
#define ADS_FSR_VOLTS       6.144f
#define ADS_VOLTS_PER_LSB   (ADS_FSR_VOLTS / 32768.0f)

/* ---------------------------------------------------------------------------
 * GM 12223861 three-bar MAP transfer function  (absolute pressure)
 * ---------------------------------------------------------------------------
 * The published curve is a straight line through two points, both specified at
 * a 5.00 V supply:
 *
 *     0.619 V -> 40 kPa
 *     4.818 V -> 304 kPa
 *
 * so, in kPa per volt,
 *
 *     slope     = (304 - 40) / (4.818 - 0.619)
 *               = 264 / 4.199
 *               = 62.8721124...          -> MAP_KPA_PER_VOLT
 *     intercept = 40 - slope * 0.619
 *               = 40 - 38.9178375...
 *               =  1.08216242...         -> MAP_KPA_INTERCEPT
 *
 * Check: 62.8721124 * 4.818 + 1.08216242 = 304.000 kPa.
 *
 * The sensor is ratiometric, so a supply that is not 5.00 V scales the whole
 * output. Normalize the measured voltage back onto the 5.00 V curve before
 * applying the line:
 *
 *     normalized_volts = map_volts * 5.00 / supply_volts
 *     nominal_kpa      = MAP_KPA_PER_VOLT * normalized_volts + MAP_KPA_INTERCEPT
 *     corrected_kpa    = nominal_kpa + cal.offset_kpa
 *     gauge_kpa        = corrected_kpa - ambient_kpa
 *
 * This replaces an earlier "volts / 0.0059 V-per-kPa" approximation that read a
 * real 1.5735 V atmosphere sample as 165 kPa. Do not re-derive these constants
 * from a slope-only datasheet blurb; the intercept is not zero.
 *
 * boost_sensors_nominal_kpa() is the only place this arithmetic lives.
 */
#define MAP_CURVE_SUPPLY_V  5.00f          /* supply the two-point fit is defined at */
#define MAP_KPA_PER_VOLT    62.8721124f    /* 264 / 4.199 */
#define MAP_KPA_INTERCEPT   1.08216242f    /* 40 - 62.8721124 * 0.619 */

/* ---------------------------------------------------------------------------
 * BMP280 (ambient reference)
 * ---------------------------------------------------------------------------
 */
#define BMP280_REG_ID        0xD0   /* 0x58 for BMP280 (0x60 = BME280) */
#define BMP280_REG_RESET     0xE0
#define BMP280_REG_CALIB     0x88   /* 24 bytes: dig_T1..T3, dig_P1..P9 */
#define BMP280_REG_CTRL_MEAS 0xF4
#define BMP280_REG_CONFIG    0xF5
#define BMP280_REG_PRESS_MSB 0xF7   /* press[3], temp[3] contiguous from here */
#define BMP280_CHIP_ID       0x58
/* ctrl_meas: osrs_t x1 (001), osrs_p x4 (011), mode normal (11) -> 0x2F */
#define BMP280_CTRL_MEAS     0x2F
/* config: t_sb 0.5ms (000), IIR filter x4 (010), spi3w off -> 0x08 */
#define BMP280_CONFIG        0x08

/* Fallback when the BMP280 is absent: run off a standard atmosphere so the
 * gauge is still usable (degraded), rather than reading nonsense. Whenever this
 * constant is in force the published sample sets ambient_is_fallback, and
 * calibration refuses to use it as a reference. */
#define STANDARD_ATM_KPA     101.325f

#define KPA_TO_PSI           0.145037738f

/* Reader cadence. ADS every loop; BMP once every N loops (ambient drifts
 * slowly, and forced/normal-mode BMP reads are the slow ones we keep off the
 * fast path). The 16 ms loop is the AGENTS.md cadence contract: 62.5 Hz MAP,
 * and 62.5/10 = 6.25 Hz ambient. */
#define SENS_LOOP_MS         16
#define BMP_EVERY_N          10

/* Sustained read failures before we assume the bus is wedged and try to clock
 * it free. 63 loops x 16 ms = 1008 ms, i.e. about one second; the same count
 * also acts as the backoff before the next attempt. */
#define SENS_RECOVER_AFTER   63
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

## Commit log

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2026-07-16 Add headless LVGL desktop simulator and fix zero-centered arc
    - sim/ builds shared boost_gauge UI with LVGL 9 + memory display
    - headless screenshots for VAC/ATMO/BOOST/OVER under preview/sim
    - vacuum arc now fills from the zero notch, not the scale minimum
    - rebuild release binaries from ESP-IDF 5.5.1
    [main.c]
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2026-07-16 Add 2s long-press brightness toggle
    Short tap still resets peak. Hold ~2s toggles AMOLED brightness
    between 100% and 12% via CO5300 panel command.
    [main.c]
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2026-07-17 Fix frozen physical gauge and web controls
    Physical face was starving on LVGL lock while SSE held httpd workers.
    Lower UI rate, pin gauge to core 1, shorten SSE sessions, harden POST
    body parsing, queue theme apply, and fix mobile time-picker layout.
    [main.c]
2026-07-17 Hard-fix frozen gauge and 405 web controls
    LVGL timer-driven physical UI updates; control APIs switched to GET
    query params to eliminate Method Not Allowed; mobile time layout fix;
    firmware version 0.2.2 for flash verification.
    [main.c]
2026-07-17 Fix physical gauge updates and web control 405s (0.2.3)
    - Update LVGL under display lock every 50ms (no timer/SSE dependency)
    - Control routes registered as HTTP_ANY; drop SSE for status polling
    - Replace iOS time inputs with hour/minute selects side-by-side
    - Remove bottom hint strip that showed as a gray bar
    - Expose ui_psi in /api/status for on-device verification
    [main.c]
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2026-07-22 Turn themes into real multi-style gauge faces
    A "theme" was only a palette swap over one arc face. It is now a style:
    boost_theme_t carries an enum (arc/vault/hud/bigdigit), boost_gauge.c is a
    scene dispatcher with build_scene/destroy_scene per style, and a theme change
    rebuilds the scene rather than recolouring it. psi_to_sweep() projects the arc's
    zero-referenced scaling into each face's own sweep so every style honours the
    configured zeroAngle. Selection persists in NVS and is mirrored by web/app.js
    and the desktop simulator.
    Three new faces join Dyno Cell: Vault-Tec, Night City, and Big Digit.
    Performance work, all measured on hardware:
    - Cache static face art once into a PSRAM lv_can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
    [boost_display.c]
2026-07-22 Add theme colour configuration and finish the OTA path
    Themes carry a working copy over the built-in table, with the three zone
    colours (vacuum/boost/overboost) editable through PUT /api/v1/themes/config and
    persisted in NVS. Overrides are matched by theme id, not table index, so a
    firmware update that adds or removes a theme cannot paint one theme with
    another's colours. Face, track, text, muted and zero stay fixed: a theme whose
    face and text are both settable is a theme that can be made unreadable. The
    dashboard grows a per-theme colour editor, debounced so one drag of a picker is
    a single request rather than fifty scene rebuilds, and repaints its own canvas
    immediately so the control doe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
    [boost_web.c, main.c]
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2026-07-22 perf(web): cut sample-to-remote-render latency
    Four changes against the measured ~95 ms mean / ~190 ms p95 pipeline.
    TCP_NODELAY (main/boost_web.c): httpd_config_t never set .open_fn, so
    Nagle applied to every connection. esp_http_server writes a response in
    many small send() calls -- ~15 for HTTP headers, two per WebSocket frame
    (header then payload) -- so every fragment after the first waited on a
    peer ACK. Measured: first 70 B at 2.6 ms, remaining 459 B at 45-50 ms.
    IDF only sets TCP_NODELAY transiently around error responses, never for
    normal responses or WS frames, and .open_fn is the only per-connection
    hook. setsockopt failure logs a warning and lets the connection proceed.
    Event-dr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
    [boost_web.c, main.c]
2026-07-22 Vendor the GIF layer, add pixel shift, cut GIF frame cost
    Three tracks, all verified on hardware over OTA.
    GIF: the README documented two local edits to lv_gif.c that no longer existed
    in the tree - .gitignore excludes managed_components/, so a dependency refresh
    had silently reverted them. One was a framebuffer zero-init, whose absence
    meant the first frame rendered over uninitialised PSRAM. The widget and the
    AnimatedGIF decoder are now vendored into main/gif/, with the upstream sources
    filtered out of the LVGL component at CMake level so a mismatch fails as a
    duplicate-symbol link error rather than reverting silently.
    On that base: the 8-bit palette-index plane is removed. In cooked mod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
    [boost_gif_dec.h]
2026-07-22 Add display settings toggles; measure the GIF work on hardware
    Pixel shift and the Big Digit static ground are now switchable from the
    settings page, both persisted in NVS and carried on PUT /themes/config.
    Verified end to end on the device, including across a reboot.
    Measured the GIF optimisations with a real 466 px GIF loaded, and the results
    are mostly negative - recording them so they are not re-attempted blind.
    Playback went 14.55 -> 15 FPS, about +3%, not the predicted +17%.
    The dirty-rect invalidation buys nothing: the instrumentation reports the mean
    frame rect at 97-98% of the canvas, so there is no smaller region to invalidate.
    The agent that wrote it predicted exactly this and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
    [boost_web.c]
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2026-07-22 Error-diffuse the vignette; colour the Big Digit readout
    Vignette: ordered dithering is replaced with Floyd-Steinberg. Bayer quantises
    each pixel independently, so on a face whose green sits at level 4 of 63 the
    wide flat plateaus between the two or three available transitions survived and
    read as faint rings. Error diffusion carries the rounding forward, so the local
    average tracks the ideal ramp continuously. The ramp also moves from smoothstep
    to smootherstep - zero first and second derivative at both ends - and maximum
    darkening drops 0.50 -> 0.40. This is a serial pass with two error rows, far too
    slow per frame and completely free once baked into the cached face.
    Big Digit gains a sec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
    [boost_web.c]
2026-07-22 TE sync, tighter needle invalidation, configurable pixel shift
    Three parallel tracks, integrated and measured on hardware.
    TE synchronisation. The schematic decode was right: the tearing-effect line is
    GPIO13 and the panel drives it. Rather than the adapter's TEAR_AVOID_MODE_TE_SYNC
    - which drains the semaphore and waits per *flush*, so a needle update costs 2-3
    waits and a full repaint 24 - the gate hangs off the adapter's custom_draw_bitmap
    hook, honoured only in TEAR_AVOID_MODE_NONE. A gate is armed at
    LV_EVENT_RENDER_START, the first strip of the cycle waits, later strips stream
    unblocked: one wait per render cycle. Every wait is bounded at 25 ms, never
    portMAX_DELAY, and eight consecut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
    [boost_display.c, boost_web.c]
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2026-07-23 Big Digit text colour; fix gradient toggle resync
    Add a configurable readout text colour for Big Digit (default white), so a white
    static background can carry black digits. Verified black-on-white on the panel.
    Persisted in NVS, shown in the theme editor whenever the readout is not sweeping
    the zone colours.
    Fix the gradient-fill toggle unchecking itself after a couple of seconds:
    queueThemeConfig refreshed bigDigitStaticBg/ColorText from the response but not
    arcGradient/hudGradient/bigDigitStaticColor, so the debounced re-render read the
    stale false and cleared the box even though the device had saved it. All toggle
    fields now resync from the response.
    TE investigation: the settings toggl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
    [boost_web.c]
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2026-07-23 Replace simulated MAP data with real ADS1115 + BMP280 sensor reads
    Add a project-local sensor path that drives the gauge from a GM 3-bar MAP
    sensor (ADS1115 A0, 0x48) referenced against a BMP280 ambient baseline
    (0x76), on a dedicated I2C bus (SCL=GPIO18, SDA=GPIO17, port 0) kept
    separate from the BSP touch/IO-expander bus (GPIO14/15, port 1).
    - boost_sensors.{c,h}: compact, well-commented ADS1115 (continuous A0,
    +/-6.144V FSR) and BMP280 (normal mode, Bosch integer compensation)
    drivers plus a reader task. Reads run on their own cadence (50 Hz MAP,
    5 Hz ambient); the display timer and web task only copy the latest
    snapshot under a short mutex, so a slow I2C read never stalls the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
    [boost_sensors.c]
2026-07-23 Add I2C bus scanner and OTA rollback net for the sensor path
    GET /api/v1/sensors/scan probes every 7-bit address on the sensor bus and
    reports which ACK — a serial-free way to diagnose the wiring, since the board
    now runs from 5 V with no USB. busUp:false means the bus never came up; an empty
    found[] with the bus up points at wiring / power / pull-ups / swapped SDA-SCL;
    0x48 + 0x76 confirm the ADS1115 and BMP280.
    Also enable CONFIG_BOOTLOADER_APP_ROLLBACK_ENABLE and confirm the running image
    healthy once the web control plane is up (esp_ota_mark_app_valid_cancel_rollback
    in app_main). A freshly OTA'd image that cannot reach a serviceable state now
    auto-reverts to the previous slot instead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
    [boost_sensors.c, boost_web.c, main.c]
2026-07-23 Self-heal a wedged I2C sensor bus
    A slave whose transaction is interrupted (a power glitch, a marginal contact)
    can sit holding SDA low forever, waiting for clocks that never come, and the
    master then just times out every read. A soft reboot does not fix it because the
    ESP resetting does not reset the slave. Add the standard recovery: detach the
    I2C peripheral from the pins, bit-bang up to 9 SCL pulses to walk the stuck
    slave through its byte and ACK until it releases SDA, issue a STOP, then rebuild
    the bus and re-arm the sensors.
    Runs in two places: the reader task triggers it after ~1 s of consecutive read
    failures (with that interval doubling as the backoff), and boot runs it once if
    nei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
    [boost_sensors.c, boost_web.c]
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2026-07-25 Convert MAP with the real GM curve and calibrate against the BMP280
    The gauge read +9.63 PSI of boost sitting at atmosphere. The placeholder
    transfer function (V - 0.6) / 0.0059 was never checked against the
    datasheet and overstated a real 1.5733 V reading by ~66 kPa. Both sensors
    were healthy throughout, which is what made it dangerous: every diagnostic
    looked fine.
    Replace it with the two-point GM 12223861 fit defined at the curve's 5.00 V
    reference supply (0.619 V -> 40 kPa, 4.818 V -> 304 kPa), normalize the
    actual ratiometric supply out before applying it, and add a manual one-point
    atmospheric calibration against the BMP280.
    The correction is deliberately additive in kPa. One known p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
    [boost_sensors.c, boost_web.c]
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2026-07-25 Stop themes owning brightness, and report the real firmware version
    Two independent reports from the panel status box.
    Brightness: boost_model_set_active_theme() overwrote and persisted
    cfg.brightness_high/low from the theme's own pair on every theme switch -
    dyno-cell 92/18, vault-tec 85/12, night-city 90/14, big-digit 90/16. Any
    hand-set brightness was destroyed by picking a different face, with no way
    to keep it. The dim schedule was working correctly the whole time; the
    high/low values it selects between had simply been replaced underneath it,
    which is why it looked like the schedule was being ignored.
    Brightness is a display setting owned by the user and the schedule, so the
    theme no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
    [boost_web.c]
2026-07-25 Stop the state poll erasing errors, drop LIVE text, correct the WS rate
    Three dashboard fixes.
    pollState() called showError("") on every successful /state sample - 4 Hz
    on HTTP fallback - so it retracted errors it never raised. Measured against
    the pre-fix tree, a validation error survived 223 ms. Every write to the
    shared box now carries its source: ERR_LIVE for unattended telemetry
    (pollState, WebSocket frames) and ERR_USER for a gesture's outcome, with a
    producer clearing only what it raised and ERR_USER outranking ERR_LIVE in
    both directions. Tagging beats a dwell timer because this is an ownership
    bug, not a timing one. Measured after: 14.9 s and 24.4 s dwell, 0 hidden
    samples across 1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
    [boost_web.c]
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2026-07-27 Stop a WebSocket disconnect permanently burning a pool slot
    state_ws_get() released a slot by setting fd = -1 and nothing else, leaving
    inflight set and payload pointing at a context state_ws_send_done() would free.
    That completion only clears inflight when client->fd == ctx->fd, which can
    never match again once fd is -1, and slot allocation needs fd < 0 && !inflight.
    The slot was dead until reboot, so a dashboard disconnect cost 62.5 f/s of
    telemetry and after three every client fell back to 4 Hz HTTP.
    Release now goes through one state_ws_release_locked() that clears fd, payload
    and inflight together and bumps a per-slot generation. The ctx carries the
    generation it was queued under, and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
    [boost_web.c]
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2026-07-27 spike: temporary internal-heap probe for the LVGL IRAM A/B
    GET /api/v1/debug/heap reports internal/DMA/PSRAM free, largest block and
    minimum-ever free so internal DRAM can be sampled at genuine peak (display
    rendering, STA + SoftAP, HTTP live, 3 WebSocket clients) from the LAN.
    Measurement scaffolding only; reverted later on this branch.
    [boost_web.c]
2026-07-27 Revert "spike: temporary internal-heap probe for the LVGL IRAM A/B"
    This reverts commit 9c192e77f2cd149551afc779339e369f6c3c61de.
    [boost_web.c]
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2026-07-28 Region-dbuf worst case: adaptive TE wait, and Fix 1's blocker documented
    Two hypotheses from the user's brief, both tested with evidence rather than
    assumed:
    Fix 1 (LVGL rasterising directly into the PSRAM canvas, eliminating the
    LVGL-strip -> canvas memcpy in te_draw_bitmap_cb): investigated and NOT
    built. display_manager_validate_tearing_mode() in the vendored adapter
    (managed_components/espressif__esp_lvgl_adapter) only accepts tear_avoid_mode
    NONE/TE_SYNC for ESP_LV_ADAPTER_PANEL_IF_OTHER, which is what this QSPI/CO5300
    panel uses. DOUBLE_DIRECT - the only path to LV_DISPLAY_RENDER_MODE_DIRECT -
    is rejected for that interface, and esp_lv_adapter_register_display() returns
    NULL. Confirme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
    [boost_display.c, boost_web.c]
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2026-07-28 Per-span TE-wait proof: score early/late against each span's own range
    te_wait_for_region_spans() replaces te_wait_for_region(): instead of one
    early/late question about the union of top_row/bottom_row across every span
    in a cycle, ask the same question per span, using each span's own y0/y1 and
    (for EARLY on the second and later spans) a scan position projected forward
    by a deliberately pessimistic estimate of how long transferring the earlier
    spans takes. A scan position sitting in the gap between two disjoint spans -
    routine on vault-tec, where the needle and a digit-slot label invalidate in
    the same cycle at unrelated y ranges - can be genuinely late for the near
    span and genuinely early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
    [boost_display.c]
2026-07-28 Fix per-span EARLY projection: use the write's own row time, not the scan's
    The first cut of te_wait_for_region_spans() converted an earlier span's
    height directly into "scan rows" 1:1 - equivalent to assuming the WRITE
    moves at the same (slower) rate as the SCAN. That is far more pessimistic
    than intended and cost real skips: an ordinary tall first span (the vault
    needle near vertical is ~150-200 rows) alone was often enough to inflate the
    projected scan position past what the old union check needed, so cycles the
    union proved EARLY could no longer be proved EARLY per-span. Measured via a
    hardware A/B on this branch (rebuild+reflash between arms, same
    demoFastSweep harness): fast-sweep rend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
    [boost_display.c]
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2026-07-31 fix: boost_ws stack overflow from web-TPMS buffer growth
    The web-TPMS integration grew the state_json serialization buffer on the
    boost_ws task stack (768 -> 1024 B) and enlarged boost_state_t (copied
    on-stack inside state_json). The 3072-word task stack was sized for the
    pre-TPMS footprint; the extra ~300 B pushed it over the edge, causing a
    stack overflow -> reset loop that made the web UI unreachable (the server
    came up for <1 s then crashed before any browser could connect).
    Fix: make the 1 KB serialization buffer static in state_ws_push (safe --
    single caller, sequential, no reentrancy) and bump the task stack from
    3072 to 4096 words for defensive headroom.
    Verified on hardware: boot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
    [boost_web.c]
2026-07-31 feat: render TPMS as page 2 of the gauge-face mirror with synced toggle
    The web TPMS data now lives inside the 466x466 gauge-face mirror canvas
    as a true second page, not a side widget. The mirror reproduces the
    panel's two pages: page 0 the themed boost face, page 1 a canvas face
    that faithfully mirrors the on-device TPMS layout (same geometry, colors,
    and OK/STALE/LOW/OFFLINE status semantics, with a live pulse on non-OK
    states). The flat side-rail TPMS panel is removed.
    Sync model copies the theme picker exactly:
    - Device -> web: boost_model_refresh_status() reads boost_page_active()
    and emits activePage in the WebSocket state JSON; app.js watches it and
    flips the mirror, toggle, pag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
    [boost_web.c]
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2026-08-04 feat: finish TPMS pages and gauge performance tuning
    Rebuild the TPMS device and web faces around the processed powertrain art,
    add synchronized page controls and Vault needle options, and tighten gauge
    rendering, gradients, brightness handling, touch timing, and TE fail-safes.
    Includes simulator/firmware validation updates and regenerated embedded web
    assets.
    [boost_display.c]
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2026-08-07 feat: neon marquee three-ring stage ladder with rotating chase
    Redesign the marquee border from a single 72-bulb accent ring into three
    zone-mapped rings (innermost vacuum, middle boost, outermost overboost):
    - Rings at 176/200/224 (NEON_BULB_RING_STEP 24, 1.5x spread), all 216 bulbs
    baked in dim track; accents staggered per ring ((i + 2z) % 6 < 2) so lit
    rings form a diagonal, never radial spokes.
    - Cumulative stage ladder: ring z's 24 accent bulbs light in that ring's
    zone colour once the reading has REACHED that zone. Zone flips invalidate
    only the changed rings' 12 pair-boxes each, inside LVGL's 32-slot buffer.
    - The shared 118px NEON_BIG readout draws scaled to 0.87 (one sprite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
    [boost_web.c, main.c]
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2026-08-11 perf: neon A8 segment tiles, gradient tube arc, teScanline, demand-aware cadence gates
    Known-good optimization pile, plus the banded-flip-sweep attempt that was
    reverted on the user's glass review (see ledger row).
    Neon:
    - Tube run drawn as one lv_draw_arc carrying a pre-baked radial-gradient
    RGB565 image per zone (3 baked at scene build, flip switches the image).
    Fixes the white cap's non-uniform AA edge (image is 2*(NEON_R+MARGIN) px).
    - Segments: 162 A8 coverage band tiles baked once and recoloured/blitted at
    runtime (zero live ring arcs); symmetric-difference invalidation
    (boost_neon_seg_diff) invalidates only segments whose painted state changed.
    - Per-glyph readout/sign invali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
    [boost_display.c, boost_web.c]
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2026-08-11 feat: neon tube/segments geometry rework (two-tone track, wider segments, centred marker)
    - Tube: four-band lit run (dark halo 20 / bloomed inner 16 / HSL-lightened outer 16 / white cap 6), track split into two distinct tones that read as a smooth dark->light gradient; outer colour is a general HSL-lightness rule applied to any user zone colour, never a white-lift (washed) or a deepen (sandwich).
    - Tube 0 marker: 25% narrower (NEON_TUBE_ZERO_DEG 2.25) and centred on the real zero via NEON_TUBE_ZERO_CENTER 0.25 to offset lv_draw_arc's trig-table edge quantisation.
    - Segments: NEON_NSEG 54->45 (4-degree lit wedges with the original 2-degree gap restored), halo 20 px vs 25 px body so the inner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
    [main.c]
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2026-08-11 perf(display): TE-scanline write-ahead for wide-region flips, teScanline web mirror
    The region-dbuf EARLY/LATE proof waited for the next V-blank whenever the
    scan sat inside [y0,y1) - for the wide neon flip bands that is up to a full
    ~16.75 ms period. But the burst writes faster than the scan (31.4-31.6 us/row
    incl. CASET/RASET intercepts vs ~35.95 us/row scan), so a mid-band start can
    finish the span before the scan reaches it, carrying the same one-frame-old
    semantics LATE already accepts. Accept the first span (rows_before == 0) when
    the projected collision row C = (S*ts - y0*tw)/(ts - tw) clears the bottom +
    margin, guarded on the panel measuring faster than the write. No new toggle
    (rid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
    [boost_display.c]
2026-08-11 perf(neon): defer the zone-flip run recolor one frame (word-first, arc-next-frame)
    The boost↔overboost flip recolors the whole lit run in one frame - the widest
    dirty region on the tube/segments faces (105,041 px tube / 125,192 px
    segments). The word, readout and peak flip instantly; only the run is
    expensive. Deferring the run repaint to the next sample moves the full-run
    recolor out of the flip frame without spreading it across frames (the banded
    sweep was rejected by the user on 2026-08-10). One 16 ms frame of old-colour
    ring at each crossing is the whole visual cost.
    g_neon_flip_pending + s_neon_flip_lo/hi (non-static global so the sim can read
    it): the color_flip branch stores the fu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
    [main.c]
2026-08-12 fix(neon): peak/zero marker geometry, sweep ceiling, halo tip pump; tighten invalidation
    The tube peak tell-tale reused the segments marker (snapped to the 6-deg
    grid, body width, live zone colour) and the zero marker was redrawn at the
    wrong band depth; both are corrected and the two layouts' invalidation
    bounds tightened, then the halo tip extension that was supposed to fix a
    perceived inner-ring lag was reverted because LVGL's 1-deg integer arc
    grid quantized it into a 0/1 deg pump.
    - Tube peak marker: continuous arc at the exact peak angle (no segment
    snap), full NEON_TUBE_TRACK_W depth, drawn BEFORE the run so the lit arc
    sweeps over it, always drawn (no flicker), dimmed vacuum ton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
    [main.c]
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2026-08-12 perf(arc): tighten dyno value-arc flip invalidation to 30deg flat boxes
    The boost->overboost crossing repaints the whole lit run; the value-arc
    invalidation used 90deg chunks with rounded bboxes, inflating every box by the
    cap reach. Switch to 30deg flat boxes with end-chunk cap pads + interior AA
    margin (the neon ring's measured knee). Flashed + measured on the board:
    crossing worstRenderUs median 52 -> 41.5 ms, renderGapMax 52.7 -> 42.3 ms,
    sweep guard holds (min 58 / median 60, teTimeouts 0, demand coverage 1.0).
    The sim audit now crosses the overboost threshold for dyno-cell too (span 22)
    so the full-run recolor is stale-pixel-validated, not just neon's.
    Docs: crossing pinned at the ha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
    [main.c]
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
